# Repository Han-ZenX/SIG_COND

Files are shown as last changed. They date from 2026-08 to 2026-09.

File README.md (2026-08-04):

# SIG_COND - 高精度频率计前端双通道信号调理电路模块

[]()
[]()
[]()

## 项目概述

SIG_COND 是一款专为高精度频率计设计的前端双通道信号调理电路模块，提供卓越的信号采集和处理能力。该模块支持灵活的阻抗切换和 AC/DC 耦合切换，能够处理从微伏级到大幅度的宽范围信号，并配备标准的 SPI 和 I2C 双接口通信方式。

### 核心特性

- ✅ **双通道独立信号调理** - 两个完全独立的信号通道，可同时采集两路信号
- ✅ **阻抗自动/手动切换** - 支持高阻抗和低阻抗模式的灵活切换，适配不同信号源
- ✅ **AC/DC 耦合切换** - 支持交流耦合和直流耦合模式切换，适应多种应用场景
- ✅ **宽动态范围** - 从小幅度微弱信号到大幅度强信号，全覆盖处理
- ✅ **双接口通信** - 同时支持 SPI 和 I2C 接口，灵活选择通信方式
- ✅ **高精度信号采集** - 低噪声、低失真设计，确保测量精度
- ✅ **模块化设计** - 分层架构，易于集成和扩展

## 目录结构

```
SIG_COND-master/
├── firmware/          # 固件代码（MCU 控制程序）
│   ├── boards/        # 板级配置文件
│   ├── include/       # 头文件
│   ├── lib/           # 第三方库
│   ├── src/           # 源代码
│   │   ├── app/       # 应用层业务逻辑
│   │   ├── drivers/   # 外设驱动（SPI/I2C 等）
│   │   ├── hal/       # 硬件抽象层
│   │   └── services/  # 服务层（通信、配置管理等）
│   └── tests/         # 单元测试
│
├── hardware/          # 硬件设计文件
│   ├── schematic/     # 原理图
│   ├── pcb/           # PCB 布局文件
│   ├── bom/           # 物料清单
│   ├── gerber/        # 生产 Gerber 文件
│   ├── 3d/            # 3D 结构模型
│   └── pinout/        # 引脚定义
│
├── software/          # 配套软件
│   ├── desktop/       # PC 桌面应用
│   ├── mobile/        # 移动应用
│   └── cloud/         # 云端服务
│
├── docs/              # 技术文档
│   ├── architecture/  # 架构设计文档
│   ├── api/           # API 接口文档
│   ├── hardware/      # 硬件说明
│   └── user-guide/    # 用户手册
│
├── tests/             # 系统测试
│   ├── unit/          # 单元测试
│   ├── integration/   # 集成测试
│   └── hwt/           # 硬件在环测试
│
├── tools/             # 工具链
│   ├── scripts/       # 构建脚本
│   └── utilities/     # 辅助工具
│
└── ci/                # CI/CD 流水线配置
```

## 硬件规格

### 通道特性

| 参数 | 指标 |
|---|---|
| 通道数 | 2 路独立通道 |
| 输入阻抗 | 可编程切换（高阻/低阻） |
| 耦合方式 | AC/DC 可选 |
| 输入范围 | 微伏级～大幅度信号 |
| 信噪比 | 高信噪比设计 |
| 带宽 | 宽频带响应 |

### 接口规范

#### SPI 接口
- 时钟频率：最高可达 XX MHz
- 模式：支持 Mode 0/1/2/3
- 数据位：8/16/32 位可选
- 引脚定义：见 `hardware/pinout/pinout.md`

#### I2C 接口
- 速率：标准模式 (100kHz)、快速模式 (400kHz)、高速模式 (3.4MHz)
- 地址：可配置 I2C 地址
- 支持多主机和从机模式

## 软件架构

本项目采用**分层模块化架构**，核心设计原则：

- **更换 MCU 只改 HAL 层，业务逻辑零修改**
- **各层解耦，独立编译和测试**
- **支持多板级并行开发**

### 层次结构

```
┌─────────────────┐
│     App Layer   │  ← 业务逻辑、状态机、用户交互
├─────────────────┤
│  Services Layer │  ← 通信协议、配置管理、数据存储
├─────────────────┤
│   Drivers Layer │  ← SPI/I2C 驱动、外设控制
├─────────────────┤
│     HAL Layer   │  ← GPIO、时钟、中断抽象
└─────────────────┘
```

## 快速开始

### 环境要求

- CMake 3.16+
- ARM GCC 工具链 (10-bit-32bit)
- Python 3.8+ (用于构建脚本)
- Git + Git LFS (大文件支持)

### 构建固件

```bash
# 克隆仓库
git clone --recurse-submodules https://github.com/your-repo/SIG_COND.git
cd SIG_COND

# Debug 版本构建
cmake -B firmware/build -DBOARD=default
cmake --build firmware/build

# Release 版本构建
cmake -B firmware/build -DBOARD=default -DCMAKE_BUILD_TYPE=Release
cmake --build firmware/build --config Release

# 使用构建脚本（推荐）
python tools/scripts/build.py --board=default
python tools/scripts/build.py --board=default --release
```

### 烧录固件

```bash
# 烧录到目标板
python tools/scripts/build.py --flash
```

## 使用说明

### 初始化配置

1. **接口选择**：通过软件配置选择 SPI 或 I2C 通信接口
2. **阻抗设置**：配置通道输入阻抗模式（高阻/低阻）
3. **耦合方式**：选择 AC 或 DC 耦合
4. **增益设置**：根据信号幅度调整放大倍数

### 典型应用场景

- 🔬 实验室精密测量
- 📡 通信信号分析
- ⚡ 电力电子监测
- 🎵 音频信号测试
- 🏭 工业过程控制

## 开发指南

### 新增功能

```bash
# 创建功能分支
git checkout -b feat/new-feature

# 开发完成后
git add .
git commit -m "feat: 添加新功能"
git push origin feat/new-feature
```

### 硬件改版

当需要修改硬件设计时：

```bash
# 1. 更新原理图和 PCB（在 EDA 工具中）
# 2. 更新引脚定义
cp -r hardware/schematic/v1.0 hardware/schematic/v2.0

# 3. 更新固件板级配置
cp -r firmware/boards/default firmware/boards/v2.0

# 4. 编译验证
cmake -B firmware/build -DBOARD=v2.0
```

## 测试

```bash
# 运行单元测试
python tools/scripts/build.py --test=unit

# 运行集成测试
python tools/scripts/build.py --test=integration

# 完整测试套件
python tools/scripts/build.py --test=all
```

## 版本历史

### v1.0.0 (2026-08-04)
- ✨ 初始版本发布
- ✅ 实现双通道信号调理
- ✅ 完成阻抗切换功能
- ✅ 完成 AC/DC 切换功能
- ✅ 支持 SPI 和 I2C 接口
- ✅ 实现宽范围信号处理能力

## 技术支持

如需技术支持或遇到问题，请：

1. 查阅 [用户手册](docs/user-guide/)
2. 查看 [API 文档](docs/api/)
3. 提交 [GitHub Issue](https://github.com/your-repo/SIG_COND/issues)

## 贡献指南

欢迎贡献代码！请阅读 [贡献指南](CONTRIBUTING.md) 后提交 PR。

## 许可证

本项目采用 MIT 许可证。详见 [LICENSE](LICENSE) 文件。

---

**注意**：本产品仅供教育和专业用途，使用前请确保安全操作规范。

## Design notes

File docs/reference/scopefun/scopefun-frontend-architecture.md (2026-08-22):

# ScopeFun 前端信号链架构分析

> 分析对象：`Scopefun原理图.pdf`（21 页）。前端在 p2–p5，四通道完全相同，本文以 p2 的**通道 4** 为准，位号后缀 `_4`。支撑电路取自 p10（偏置与失调）和 p13（前端电源）。
>
> PDF 为纯矢量图、文字已转曲，本文全部结论由渲染后逐页读图得出，**器件规格未经数据手册核实**。

四通道相同的模拟前端，从 BNC 到 ADC 共四级。核心是 **BUF802 与 OPA140 组成的混合路径缓冲**——它把 AC/DC 耦合切换从射频通路挪到了低频通路，因此一颗 CMOS 模拟开关就够，不需要射频继电器。

---

## 目录

- [信号链总览](#信号链总览)
- [Stage 1 端接与阻抗切换](#stage-1-端接与阻抗切换)
- [Stage 2 50× 衰减器](#stage-2-50-衰减器)
- [Stage 3 混合缓冲与 AC/DC 耦合](#stage-3-混合缓冲与-acdc-耦合)
- [Stage 4 可编程增益放大](#stage-4-可编程增益放大)
- [支撑电路](#支撑电路)
- [七个值得借鉴的手法](#七个值得借鉴的手法)
- [对频率计前端的适配](#对频率计前端的适配)
- [本文未覆盖的部分](#本文未覆盖的部分)
- [附：原理图切片](#附原理图切片)

---

## 信号链总览

四级串联，每一级由一个继电器或一颗芯片主导。级号是真实的信号顺序。

| 级 | 名称 | 主器件 | 作用 |
|---|---|---|---|
| **1** | 端接与阻抗切换 | `K1000_4` UD2-4.5NUN-L | DPDT 继电器选路 + 汇合，50 Ω 端接或 1 MΩ 高阻 |
| **2** | 50× 衰减器 | `K1001_4` + 976k/20k | 1× 直通或 50× 分压，多阶补偿网络 + 可调微调电容 |
| **3** | 混合缓冲与 AC/DC | `BUF802` + `OPA140` + `TMUX4053` | 高频走 JFET，低频走精密运放，AC/DC 在低频路径切换 |
| **4** | 可编程增益 | `LMH6518` | 单端进差分出，失调由 DAC 从 IN_N 注入 |

四级之后是 ADC Driver（p6–p9）与 ADC（p11），对频率计不适用，本文不展开。

---

## Stage 1 端接与阻抗切换

> Termination and Attenuation · `K1000_4` · 原理图：[`p2_term_L.png`](./p2_term_L.png)

### 信号路径

```
J1002_4 (BNC) ── BNC_IN ── K1000_4A pin3 (COM)
                              │
   ┌──[pin4] TERM_50Z ────────┴──┬── R1025_4  49.9Ω ── GND      (50 Ω 端接)
   │                             │
   │                             └── R1021_4  15Ω ────┬── TERM_50Z_R ── K1000_4B pin5
   │                                 C1058_4 18pF ────┘
   │                                 + R1053_4 0Ω  (与 15Ω 并联)
   │
   └──[pin2] TERM_1M ── R1022_4 30Ω ── TERM_1M_R ────────────── K1000_4B pin7
                                       C1022_4 (DNP) ── GND
                                                                      │
                                                    K1000_4B pin6 (COM) ── ATTEN_IN
```

一颗 DPDT 继电器用掉两组触点：**A 组选路、B 组汇合**。这是双通路架构的标准用法——两组触点同步动作，保证输入端和输出端永远选中同一条路径。

### 元件

| 位号 | 值 | 作用 |
|---|---|---|
| **R1025_4** | 49.9 Ω | 50 Ω 档的端接电阻，接在继电器输出侧、限流电阻之前 |
| **R1021_4** | 15 Ω | 50 Ω 路径的串联阻尼／限流 |
| C1058_4 + R1053_4 | 18 pF + 0 Ω | 并联在 15 Ω 两端做高频旁路，抵消它在高频段的插损。容抗等于 15 Ω 的频点约 590 MHz |
| **R1022_4** | 30 Ω | 1 MΩ 路径的串联限流保护。相对 1 MΩ 可忽略，故障时限制冲入后级的电流 |
| C1022_4 | DNP | 预留位，不贴 |

### 继电器驱动值得单独看

```
+VUSB ──┬── R1027_4 22Ω ──┬────────── pin1 (线圈+)
        │                  │
   C1026_4 22µF        C1027_4 22µF     C1009_4 1µF
        │                  │                 │
       GND                GND               GND

pin8 (线圈−) ──┬── D1000_4 (1N4148WT-7) ── +VUSB   续流
               └── Q1002_4 (DMN62D0UW) ── GND

TERMD ──┬── R1029_4 10K ── Q1002_4 栅极
        └── R1031_4 10K ── GND                      栅极下拉
```

**22 Ω 串联 + 44 µF 储能**——切换瞬间由大电容放电提供吸合所需的大电流，稳态时 22 Ω 限制保持电流。既降低了对 +VUSB 的冲击，又减少了线圈持续发热带来的热漂移。

**栅极 10 K 下拉（R1031_4）**——控制信号悬空或上电未初始化时，MOS 确定关断，继电器状态不会不确定。四个通道八个继电器每一个都配了下拉。

---

## Stage 2 50× 衰减器

> 50x Attenuator · `K1001_4` · 原理图：[`p2_term_R.png`](./p2_term_R.png)

只有 **1× 和 50× 两档**，没有 10×、没有 100×。这印证了通用做法：衰减档是保护档，不是量程档——量程由后面 LMH6518 的可编程增益和失调 DAC 承担。

### 分压与补偿网络

```
ATTEN_IN ── K1001_4A pin3 (COM)
              ├──[pin4] ATTEN_1X ─────────────────── K1001_4B pin5
              │                                              │
              └──[pin2] ATTEN_50X_IN                         │
                          │                                  │
                          ├── R1001_4 1K ── C1011_4 3pF ── GND   (输入阻尼)
                          │
                          ├── R1024_4 976k ─────────────┬── ATTEN_50X_OUT ── pin7
                          │                             │
                          ├── C1023_4 3pF ──┐           ├── R1026_4  20k    ── GND
                          │                 ├── M ──────┤   C1021_4  3pF    ── GND
                          └── C1012_4 0.3pF │           └── C1059_4  2–6pF  ── GND  ★可调
                              └ R1002_4 976k┘
                                    M ── C1025_4 8pF ── GND
                                    M ── C1024_4 1pF ── ATTEN_50X_OUT
                                                                  │
                                             K1001_4B pin6 (COM) ── ATTEN_OUT
```

直流分压比由主链决定：

```
20k / (976k + 20k) = 1/49.8 ≈ 1/50
```

高频段则由电容网络决定。`C1012_4 0.3pF`、`C1023_4 3pF`、`C1024_4 1pF`、`C1025_4 8pF` 与 `R1002_4 976k` 构成的中间网络，是在基本的两元件补偿之外再加的**多阶极点／零点整形**，用来把过渡区的响应压平。这比教科书上的「上下臂各并一颗电容」复杂得多，是宽带衰减器做到平坦的实际代价。

### 两个工程细节

- `C1059_4` 是 **2–6 pF 可调电容**，装在下臂。杂散电容量产不可控，补偿必须留一个可调元件，出厂用方波逐档校准——和示波器探头上那颗补偿螺丝是同一回事。
- 衰减器区域盖了**金属屏蔽罩**：`SHLD1000_4`（TE 2118727-2）和 `SHLD1001_4`（TE 2118728-2，DNP 预留）。高阻抗节点必须屏蔽。

---

## Stage 3 混合缓冲与 AC/DC 耦合

> Input Buffer and AC/DC Coupling · `BUF802` + `OPA140` + `TMUX4053` · 原理图：[`p2_buf.png`](./p2_buf.png)

整个前端最精彩的一级。BUF802 是双路径器件：**高频走内部 JFET 缓冲，低频和直流走外部精密运放经 Aux 输入注入**。两条路径在芯片内部合并，输出既有 JFET 的带宽，又有精密运放的直流精度。

### 双路径结构

```
                        ┌── 高频路径 ───────────────────────────┐
ATTEN_OUT ── R1035_4 30Ω ── ATTEN_OUT_R ── C1030_4 1nF ── BUF_IN ──┤ pin2  IN
    │                                                              │
    │                          R1038_4 10M ── BUF_IN_BIAS ─────────┤ pin3  IN_Bias
    │                                                              │
    │                   ┌── 低频/直流路径 ──┐                       │  BUF802
    ├── R1039_4 909k ───┤                   │                      │  U1009_4
    │                   ├─ C1031_4 10nF ─┐  │                      │
    ├── R1047_4 90.9k ──┘   (可被短路)   │  │                      │
    │        │                           │  │                      │
    │       GND                          ▼  │                      │
    │                            OPA140 U1011_4 (+)                │
    │                            DC_FB ────── (−)                  │
    │                                    │                          │
    │                              OPA_OUT ── R1043_4 2K ──────────┤ pin4  IN_Aux
    │                                         C1035_4 100pF ∥       │
    │                                         C1034_4 100pF ── GND  │
    │                                                               │
    │                              R1036_4 35.7k ── −5V ────────────┤ pin7  R_Bias
    │                                                               │
    └───────────────────────────────────────── BUF_OUT ◄────────────┤ pin11 OUT
                                                   │
              DC 伺服：BUF_OUT ── R1041_4 90.9k ── R1042_4 90.9k
                                       └── R1044_4 10K ── DC_FB ──► OPA140 (−)
```

### AC/DC 切换在低频路径上完成

**这是本次分析最有价值的发现。** 主高频路径上的 `C1030_4 1nF` 是**固定隔直电容，永不切换**——因为高频路径本来就只传交流，直流分量完全由 Aux 路径提供。于是 AC/DC 切换只需要在低频路径上做，而那条路径是高阻、低频的，**一颗 CMOS 模拟开关就够，完全不需要射频继电器。**

| 耦合方式 | `DC_CPLD` | TMUX4053 动作 | 效果 |
|---|---|---|---|
| **DC 耦合** | 1 | S1B–D1 导通，短路 `C1031_4`；S2B/S3B 接入 `C1002_4 68pF` | OPA140 直接看到分压后的直流，Aux 路径传递直流分量 |
| **AC 耦合** | 0 | S1A–D1 导通（S1A 悬空即断开），`C1031_4 10nF` 串入；S2A/S3A 接入 `C1001_4 100pF` | OPA140 看不到直流，输出中直流分量被消除 |

#### 交越补偿随耦合方式一起切换

注意上表第三列的后半段：AC 耦合接 **100 pF**，DC 耦合接 **68 pF**，原理图上明确注了 *"This cap is switched in during AC / DC coupling"*。

原因是 AC 耦合时低频路径里串入了 `C1031_4 10nF`，改变了该路径的传递函数，两条路径的**交越频率**随之偏移，必须重新补偿才能保证合并后的响应平坦。`TMUX4053` 三组开关由同一根 `DC_CPLD` 同步驱动，一次动作同时完成耦合切换和补偿匹配。

### 直流精度靠伺服环路

输出 `BUF_OUT` 经 `90.9k / 90.9k / 10K` 分压得到 `DC_FB`，送回 OPA140 的反相输入。OPA140 比较输入分压与输出分压，通过 Aux 路径持续校正 BUF802 的直流输出——**整机的直流精度由 OPA140 这颗精密运放决定，而不是由 JFET 决定**。这正是混合架构存在的意义。

### 元件

| 位号 | 值 | 作用 |
|---|---|---|
| R1035_4 | 30 Ω | 进 BUF802 前的串联限流／阻尼（与 Stage 1 的 30 Ω 同一思路） |
| C1030_4 | 1 nF | 高频路径固定隔直，不参与 AC/DC 切换 |
| R1038_4 | 10 M | BUF802 的 IN_Bias 偏置电阻 |
| R1039 / R1047 | 909k / 90.9k | 低频路径分压，合计约 1 MΩ，分压比 1/11 |
| R1043_4 | 2 K | OPA140 输出到 IN_Aux 的串联电阻，与切换电容一起决定交越特性 |
| **R1036_4** | 35.7 k | R_Bias 到 −5 V，设定 BUF802 静态电流。图上注明约 **24 mA/rail**；换 100k 则降到约 17 mA/rail |
| U1001_4 | TMUX4053 | 三组 SPDT 模拟开关，±5 V 供电，EN 接地常使能，SEL1/2/3 全部并到 `DC_CPLD`，`R1052_4 10K` 下拉 |

---

## Stage 4 可编程增益放大

> Programmable Gain Amplifier · `LMH6518` · 原理图：[`p2_pga.png`](./p2_pga.png)

```
BUF_OUT ── R1037_4 49.9Ω ── BUF_OUT_R ──► pin6  IN_P        pin15 OUT_P ──► R52_4 0Ω ── OUT_P
                                                            pin14 OUT_N ──► R97_4 0Ω ── OUT_N
PGA_BIAS ───────────────────────────────► pin7  IN_N        pin13 VCM   ──► VCM
                                                            pin1/2/16 AUX_P / AUX_N / AUX_VCM ── 未使用
PGA_CSn  ──► pin9  CSn  (R1033_4 10K 上拉)
PGA_SDIO ──► pin10 SDIO                  电源：pin3/4 VCC ◄── +VPGA (+5V 经 FB1000_4 120Ω@100MHz)
PGA_SCLK ──► pin11 SCLK                        pin12 VDD ◄── +3V3_PGA
                                               pin5/8 GND, pin17 PAD ── GND
```

**单端驱动、差分输出。** LMH6518 的输入引脚是 `IN_P`／`IN_N` 一对，但用法是单端：信号经 49.9 Ω 进 `IN_P`，`IN_N` 接一个直流参考电平 `PGA_BIAS`。芯片放大的是两者之差。

### IN_N 就是失调／电平注入点

`PGA_BIAS` 由 `+VBIAS`（2.5 V 基准）经 `R1045_4 ∥ R1046_4`（1K ∥ 1K）与 DAC 输出的 `TRIM` 信号混合形成，`TRIM` 先过一颗 `FB1001_4 120Ω@100MHz` 磁珠再进来，`C1042_4 100nF` 滤波。

改变 `IN_N` 的电平，就等于移动了信号的参考零点。对示波器这是**垂直位置**；对频率计，这就是**触发电平**——而且是在放大之前设定的，DAC 的分辨率要求远低于在比较器端设阈值。

### 省电细节

原理图注明 *"Max VCC current before configuration (AUX output on): 0.225 A / after configuration turns off AUX output: 0.165 A"*。**ScopeFun 没有使用 AUX 输出**，并在 SPI 配置时主动关闭它，省下 60 mA。`J3_4`／`J4_4` 两个 UFL 座标为 DNP，看得出原本打算把 AUX 引出。

---

## 支撑电路

### 基准与失调 DAC（p10）

> 原理图：[`p10_trim.png`](./p10_trim.png)、[`p10_bias.png`](./p10_bias.png)

| 位号 | 器件 | 说明 |
|---|---|---|
| U4 | REF2025 | 精密基准。**+VBIAS 取自 VREF 脚 = 2.5 V**，原理图注明「VBIAS Pin is 1/2 of 2.5V VREF，Use VREF For OUR +VBIAS」——即不用它自带的 1.25 V 分压脚 |
| U5 | 运放反相器 | 10k/10k 增益 −1，把 +2.5 V 翻成 **−VBIAS = −2.5 V**，反馈上并 C4 补偿，±5 V 供电 |
| U3 | MCP4728 | **4 通道 12 位 I²C DAC（带 EEPROM）**，+5 V 供电，默认地址 `1100000`。VOUTA–D 分别给四个通道的 TRIM |
| Q1 / Q2 | DMN62D0UW | I²C 电平转换，3.3 V ↔ 5 V，配 4.7K 上拉四颗 |

### 前端电源（p13）

> 原理图：[`p13_fe_pwr.png`](./p13_fe_pwr.png)

| 位号 | 器件 | 说明 |
|---|---|---|
| U15 | TPS7A9101 | **超低噪声 LDO**，+5V3 → +5 V（图上算得 5.01 V），软启动 13 ms（刻意大于前级的 6 ms）。注明 968 mA / 728 mA 两个负载点 |
| U16 | NCP161ASN330 | +5 V → +3V3_PGA，给 LMH6518 的数字域 |
| FB1000 / FB1001 | 120Ω@100MHz | 磁珠分域：PGA 电源与 TRIM 信号各自隔离 |

模拟前端用的是**超低噪声 LDO 而不是普通 LDO**，且每一路电源都配了 10 µF + 1 µF 的密集去耦阵列（单通道就有近二十颗）。高阻节点对电源纹波极其敏感，这笔成本省不得。

---

## 七个值得借鉴的手法

### 1. 把 AC/DC 切换挪出射频通路

混合路径架构下，直流分量只走低频支路，所以耦合切换也只需在低频支路上做。一颗 TMUX4053 取代了射频继电器和大体积高压隔直电容——这是 BUF802 架构带来的最大结构性简化。

### 2. 补偿参数跟着工作模式一起切换

AC 与 DC 两种耦合下，两条路径的交越频率不同，于是交越补偿电容也跟着切（100 pF / 68 pF），由同一根控制线同步完成。只切信号不切补偿，响应就会在交越区出现凸起或凹陷。

### 3. 继电器的储能式节能驱动

22 Ω 串联加 44 µF 储能：吸合瞬间靠电容放电供大电流，稳态靠电阻限流。既不冲击电源，又压低了线圈的持续发热——发热就是漂移。

### 4. 每个 MOS 栅极都有下拉

八个继电器驱动无一例外配了 10 K 下拉。控制器复位、上电未初始化、固件跑飞时，继电器状态都是确定的。

### 5. 衰减器必须留可调元件

2–6 pF 可调电容装在下臂。杂散电容随批次、布局、器件批号变化，补偿条件不可能靠固定值满足，出厂逐台校准是必经步骤。

### 6. 高阻节点要有金属屏蔽罩

衰减器区域盖 TE 屏蔽罩并预留第二个位置。976 kΩ 量级的节点上，几毫伏的空间耦合就是可观的误差。

### 7. 超低噪声 LDO + 磁珠分域 + 密集去耦

电源不是「能用就行」的部分。前端用 TPS7A9101 这类超低噪声 LDO，PGA 电源和 DAC 输出各经磁珠隔离，单通道近二十颗去耦电容。

---

## 对频率计前端的适配

ScopeFun 用的正是 **BUF802 + LMH6518** 组合，衰减档也正是 **1× / 50×** 两档。这为几个悬而未决的选型提供了实证。

### 可以直接搬过来的

| | 内容 |
|---|---|
| **直接抄** | **Stage 3 整块。** BUF802 + OPA140 + TMUX4053 的混合缓冲，含 AC/DC 方案、交越补偿切换、DC 伺服环路。这一块同时解决 1 mHz 直流精度需求和 500 MHz 带宽需求，还省掉原本要用 K3 继电器加两颗隔直电容的整套 AC/DC 电路 |
| **直接抄** | **Stage 1 的继电器用法与驱动。** 一颗 DPDT 分「选路 + 汇合」两组触点，与现有 K1 用法一致，确认方向正确。储能式驱动和栅极下拉直接补进电路 |
| **直接抄** | **LMH6518 的 IN_N 做电平注入。** ScopeFun 用它做垂直位置，频率计用它做触发电平，接法完全相同：基准电压经电阻网络与 DAC 输出混合，DAC 侧串磁珠。MCP4728 这类 4 通道 12 位 I²C DAC 就够用 |
| **直接抄** | **电源与偏置架构。** 超低噪声 LDO、REF2025 产生 ±2.5 V 基准、磁珠分域 |

### 必须为频率计改动的

| | 内容 |
|---|---|
| **要改** | **输出级完全不同。** ScopeFun 的 LMH6518 主输出经 0 Ω 送 ADC Driver 再进 ADC；频率计要送 ADCMP573 比较器。有意思的是 **ScopeFun 关掉不用的 AUX 输出，对频率计恰好是现成的比较器通道**——AUX_VCM 还能独立设定共模，正好匹配比较器的输入范围 |
| **要改** | **要补一级 100 kHz 低通。** 示波器不需要，所以 ScopeFun 全图没有；但 1 mHz 指标下噪声导致的重复触发是主要误差源，这一级必须自己加，且要用 Bessel 或一阶 RC，不能用 Chebyshev |
| **要改** | **衰减比按最大输入电压定。** ScopeFun 选 50×（976k/20k）。若最大输入定在 ±40 V 附近，10× 就够；要对齐示波器的 ±300 V 则需要 50× 或 100× |
| **要核** | **过压保护。** 这次读图没有看到明显的输入保护（TVS、箝位、过压检测跳闸）。可能在未细读的区域，也可能 ScopeFun 就是靠 30 Ω 限流加器件自身耐受。前端若要接用户任意信号，这一块不能照搬缺失 |

### 与本项目当前原理图的差距

| 环节 | ScopeFun | 本项目当前状态 |
|---|---|---|
| 阻抗切换 | K1000 DPDT，选路+汇合 | K1 同样用法，方向一致 |
| 衰减档 | 1× / 50×，单继电器选抽头 | 级联两组分压器 → 实际是 10×/100×，**缺 1× 档** |
| 缓冲器 | BUF802 + OPA140 混合 | OPA659 单路径，直流漂移是短板 |
| AC/DC | TMUX4053 在低频路径切换 | 计划用 K3 继电器 + 隔直电容，尚未实现 |
| PGA | LMH6518，IN_N 注入失调 | 已改用 LMH6518，**但整颗芯片尚未接线** |
| 触发电平 | MCP4728 → IN_N | 尚无 DAC 通路 |
| 低通滤波 | 无（示波器不需要） | 需自行增加（1 mHz 指标要求） |

---

## 本文未覆盖的部分

下列内容**没有读**，结论中不包含它们：

- p13 右半的 **−5 V 产生电路**
- p6–p9 的 **ADC Driver**（频率计不适用）
- p11 ADC、p12 时钟、p14–p20 的 FPGA 与电源

另外，全文所有器件规格——BUF802 的带宽与输入电容、LMH6518 的增益范围与输入阻抗、TMUX4053 的导通电阻、UD2-4.5NUN-L 是否为磁保持型——**均未经数据手册核实**，只是从原理图上读出的连接关系与标注值。落到自己的设计里之前，请逐条对照手册。

---

## 附：原理图切片

从 PDF 渲染的高分辨率切片，比直接翻 PDF 清楚。

| 文件 | 内容 |
|---|---|
| [`sheet.png`](./sheet.png) | 20 页缩略图联系表，用于定位 |
| [`p2_term_L.png`](./p2_term_L.png) | 端接与阻抗切换 + 继电器驱动 |
| [`p2_term_R.png`](./p2_term_R.png) | 50× 衰减器完整网络 |
| [`p2_buf.png`](./p2_buf.png) | **BUF802 + OPA140 + TMUX4053 混合缓冲**（核心） |
| [`p2_pga.png`](./p2_pga.png) | LMH6518 接线与 PGA_BIAS |
| [`p10_trim.png`](./p10_trim.png) | MCP4728 失调 DAC |
| [`p10_bias.png`](./p10_bias.png) | REF2025 基准生成 |
| [`p13_fe_pwr.png`](./p13_fe_pwr.png) | 前端 LDO |

---

*ScopeFun 为开源示波器项目，原理图为其公开资料。本文为架构分析，不含原文档的图形复制；附带切片仅为阅读便利，版权归原项目所有。*

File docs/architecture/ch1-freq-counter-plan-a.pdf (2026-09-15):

D E S I G N P L A N · F R E Q U E N C Y M E A S U R E M E N T P A T H

# CH1 测频方案 A：放弃 AUX，改由主输出分路

LMH6518 的辅助输出 AUX_P/N 在 CH1 单板上引不出来。本方案删掉 AUX 这一路，测频信号改从主输出 CH1_P / CH1_N 取，分路放到接收板上。 文档包含三部分：CH1 板的改动清单、固件配置、对接收板的接口要求。标 推断 或 待确认 的结 论，没有在器件手册里找到直接依据。

工程 | Thunderscope_Rev5.3_CH1
器件 | U1008_1 · LMH6518
手册 | ZHCSPP6E（2024-07 修订）
日期 | 2026-09-15
状态 | 方案草稿 · 尚未改图

结论

## 1 信号没有损失

AUX 与主输出的增益匹配在 ±0.2 dB 以内，−3 dB 带宽匹 配在 5% 以内，SPI 选的带宽滤波器同时作用于两路。手册 的原话是 AUX 与主输出"几乎相同"，只是失真略差。测频从 OUT 取还是从 AUX 取，拿到的是同一个信号。

## 2 CH1 板只删不加

删除 RF3、RF4、R52_8、R97_8 四个元件；U1008 的 pin1、pin2、pin16 标为不连接。AUX 相关网络在 PCB 上 本来就没有任何走线，R52_8、R97_8 还在板框外没摆放， 所以删除不需要改线。

## 3 分路挪到接收板

CH1 板只负责把 CH1_P/N 经 RF1、RF2 送出。100 Ω 端 接、比较器分支、电平转换都放在接收板。固件上电后通过 SPI 把 D10 置 1，关闭 AUX 输出级，VCC 电流大约减少 60 mA。

## 为什么不走 AUX：两路输出参数对照

数据取自 LMH6518 手册 5.5 节电气特性（测试条件：VCC = 5 V、VCM = VCM_AUX = 1.2 V、两路负载均为 100 Ω 差分），以及 6.4 节、7.2.1.2 节。

项目 | 主输出 OUT（pin15 / pin14） | 辅助输出 AUX（pin1 / pin2） | 对测频的含义
增益 | 随前置放大 HG/LG 和梯形衰减档位变化 | 与主输出匹配：典型 ±0.1 dB，最大 ±0.2 dB | AUX 并不是固定幅度的输出，幅度问题两路一样
带宽 | SPI 可选 20 / 100 / 200 / 350 / 650 / 750 MHz 或 全带宽 | 带宽匹配 5%；手册注明滤波器"同时作用于主输出和辅 助输出" | 两路带宽相同
满幅摆幅（100 MHz 时 THD ≤ −40 dBc） | 典型 800 mVpp | 典型 800 mVpp | 相同
传播延时 | 两路匹配在 100 ps 以内 | | 测频不关心
失真 | 略好 | 100 MHz：HD2 −48 dBc，HD3 −50 dBc，比主输出 略差 | 过零比较对谐波不敏感
输出共模 | 由 pin13 VCM 设定 | 由 pin16 VCM_AUX 单独设定，目前悬空 | 用 AUX 要多做一路偏置和去耦
VCC 电流 | AUX 打开：典型 210 mA，最大 225 mA ｜ AUX 关闭：典型 150 mA，最大 165 mA | 用 AUX 要多耗约 60 mA
CH1 测频方案 A · Thunderscope_Rev5.3_CH1 | 第 1 / 5 页

## 改动前后对比

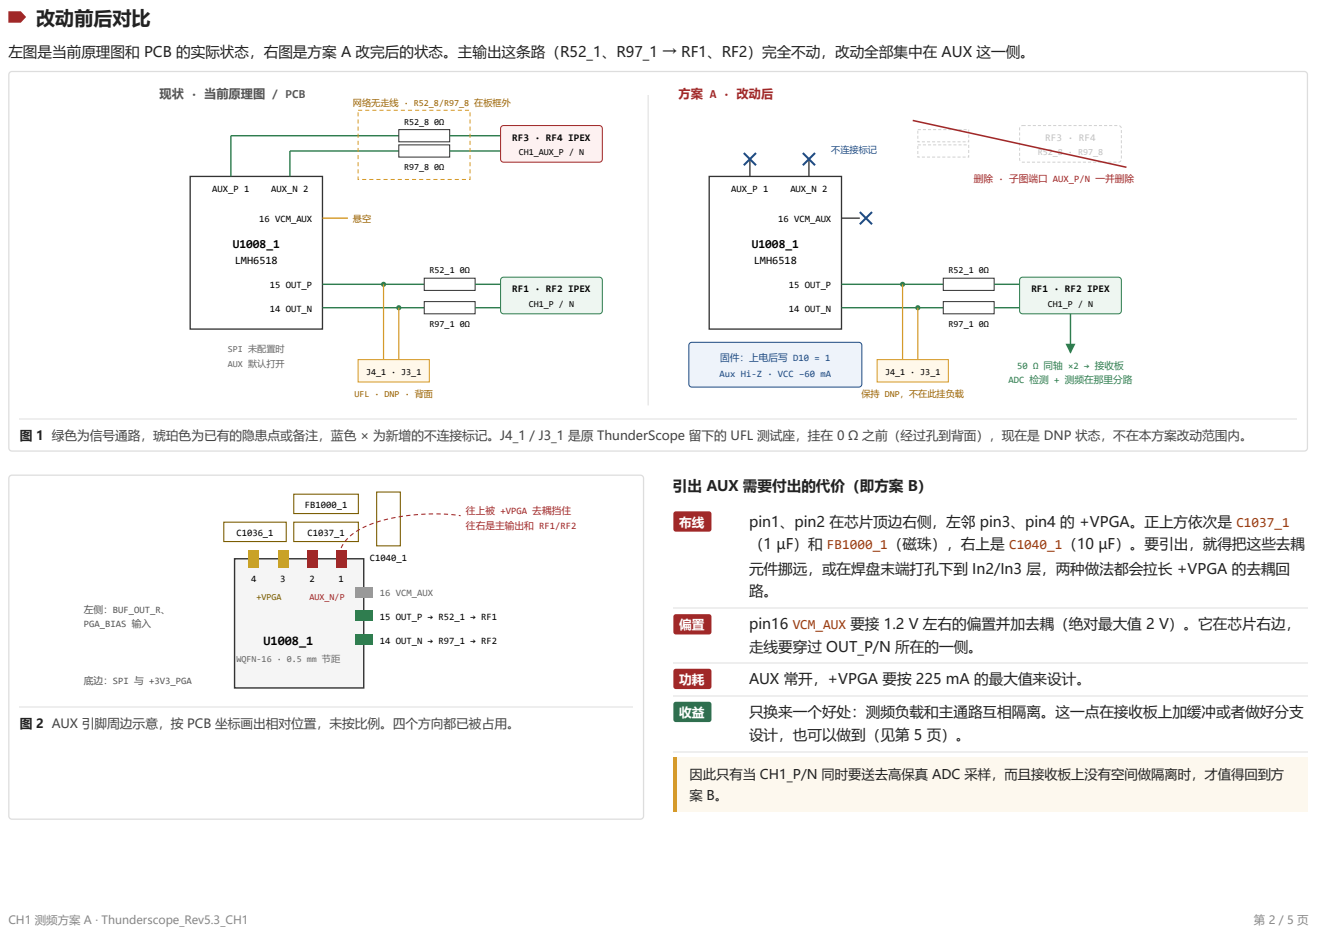
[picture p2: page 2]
U1008_1 LMH6518; AUX_P 1; AUX_N 2; RF3 · RF4 IPEX CH1_AUX_P / N; 网络无走线 · R52_8/R97_8 在板框外; 16 VCM_AUX; 15 OUT_P; 14 OUT_N; RF1 · RF2 IPEX CH1_P / N; SPI 未配置时 AUX 默认打开; 方案 A · 改动后; 不连接标记; +VPGA; AUX_N/P; 15 OUT_P → R52_1 → RF1; 14 OUT_N → R97_1 → RF2; 左侧：BUF_OUT_R、 PGA_BIAS 输入; 底边：SPI 与 +3V3_PGA; pin1、pin2 在芯片顶边右侧，左邻 pin3、pin4 的 +VPGA。正上方依次是 C1037_1; pin16 VCM_AUX 要接 1.2 V 左右的偏置并加去耦（绝对最大值 2 V）。它在芯片右边，; 走线要穿过 OUT_P/N 所在的一侧。; AUX 常开，+VPGA 要按 225 mA 的最大值来设计。; 只换来一个好处：测频负载和主通路互相隔离。这一点在接收板上加缓冲或者做好分支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

左图是当前原理图和 PCB 的实际状态，右图是方案 A 改完后的状态。主输出这条路（R52_1、R97_1 → RF1、RF2）完全不动，改动全部集中在 AUX 这一侧。

现状 · 当前原理图 / PCB

删除 · 子图端口 AUX_P/N 一并删除

固件：上电后写 D10 = 1
Aux Hi-Z · VCC −60 mA

50 Ω 同轴 ×2 → 接收板
ADC 检测 + 测频在那里分路

保持 DNP，不在此挂负载

UFL · DNP · 背面

图 1 绿色为信号通路，琥珀色为已有的隐患点或备注，蓝色 × 为新增的不连接标记。J4_1 / J3_1 是原 ThunderScope 留下的 UFL 测试座，挂在 0 Ω 之前（经过孔到背面），现在是 DNP 状态，不在本方案改动范围内。

引出 AUX 需要付出的代价（即方案 B）

往上被 +VPGA 去耦挡住
往右是主输出和 RF1/RF2

（1 µF）和 FB1000_1（磁珠），右上是 C1040_1（10 µF）。要引出，就得把这些去耦
元件挪远，或在焊盘末端打孔下到 In2/In3 层，两种做法都会拉长 +VPGA 的去耦回

WQFN-16 · 0.5 mm 节距

图 2 AUX 引脚周边示意，按 PCB 坐标画出相对位置，未按比例。四个方向都已被占用。

设计，也可以做到（见第 5 页）。

因此只有当 CH1_P/N 同时要送去高保真 ADC 采样，而且接收板上没有空间做隔离时，才值得回到方

## CH1 板改动清单

以下对象都在当前网表和 PCB 文件里核对过。改图顺序：先改三张原理图，ERC 通过后再在 PCB 编辑器里执行"从原理图更新 PCB"，最后跑 DRC。改之前要先在 KiCad 里保存并关闭工程，目录下现在 有 .lck 锁文件。

文件 | 对象 | 操作 | 说明

原理图

FE_Channel.kicad_sch | R52_8、R97_8（0 Ω 0402） | 删除 | 同时删除它们两端的导线和网络标签 AUX_R_P、AUX_R_N
FE_Channel.kicad_sch | 层次标签 AUX_P、AUX_N | 删除 | 删除后子图不再有 AUX 端口
FE_Channel.kicad_sch | U1008_1 pin1、pin2、pin16 | 加不连接标记 | 避免 ERC 报"引脚未连接"；pin16 目前没有标记，本来就在报警
FE_Channel.kicad_sch | 文字注释 "Max VCC current … AUX output …" | 保留 | 这两行（0.225 A / 0.165 A）正好说明固件要关 AUX，不用改
Thunderscope_Rev5.3.kicad_sch CH1 子图符号上的 AUX_P、AUX_N 引脚 | 删除 | 在子图符号上用"删除未使用的层次引脚"

Thunderscope_Rev5.3.kicad_sch IO 子图符号上的 AUX_P、AUX_N 引脚；标

| 签 CH1_AUX_P、CH1_AUX_N 及导线 | 删除 | 顶层不再有 CH1_AUX 网络
External_IO.kicad_sch | RF3、RF4（KH-IPEX-K501-29） | 删除 | 同时删除层次标签 AUX_P、AUX_N；只服务 RF3、RF4 的 GND 符号一并删除

PCB
Thunderscope_Rev5.3.kicad_pcb 从原理图更新 | 同步 | 自动移除 RF3（147.4, 78.2）、RF4（147.4, 73.8）和板框外的 R52_8、R97_8。这 4 个网络上没有走线、
| | | 过孔或铺铜连接，不需要手工清理
Thunderscope_Rev5.3.kicad_pcb RF3、RF4 腾出的区域 | 可选 | 约在板子右下角，可以留给后续的 VCM / +VBIAS 基准电路（接口图册里列为"必须补"的项目）
Thunderscope_Rev5.3.kicad_pcb U1008 周边、主输出走线 | 不动 | R52_1、R97_1、RF1、RF2 以及 +VPGA 去耦都保持原样
BOM 与文档
BOM | −2 × KH-IPEX-K501-29，−2 × 0 Ω 0402 | 减少 | 其他器件不变
docs/architecture/ ch1-frontend-interface.pdf | 第 1、2、3、9 页中 AUX / RF3 / RF4 相关 内容 | 同步更新 | 端口从 12 个变为 10 个；"用 AUX 时"一项改为"AUX 已关闭，固件须写 D10"

明确不做的事

不做 | 不在 CH1 板上的 OUT_R_P/N 上并联比较器或测试座负载。主输出唯一的负载应该是 远端的 100 Ω 差分端接。
不做 | 不给 pin16 加偏置电路。AUX 关闭后这个脚不再起作用，而且把偏置引过去同样会碰 到图 2 里的布线问题。
不做 | 不动 J3_1、J4_1。它们是 DNP，当前只是焊盘和过孔形成的一小段短截线。要不要删 属于另一项清理工作，不和本方案捆在一起。

本方案依赖、但不在范围内的前提

前提 | VCM（pin13）目前没有驱动源。主输出共模不确定时，接收板的直流耦合比较器无法设 计，所以这一项要先解决。手册的测试条件是 1.2 V，绝对最大值 2 V。
前提 | +VBIAS、−VBIAS 没有来源，LMH6518 输入端的直流工作点不成立。这是整板能否工 作的问题，与测频无关，见接口图册第 9 页。
CH1 测频方案 A · Thunderscope_Rev5.3_CH1 | 第 3 / 5 页

## 固件：关闭 AUX，设置测频档位

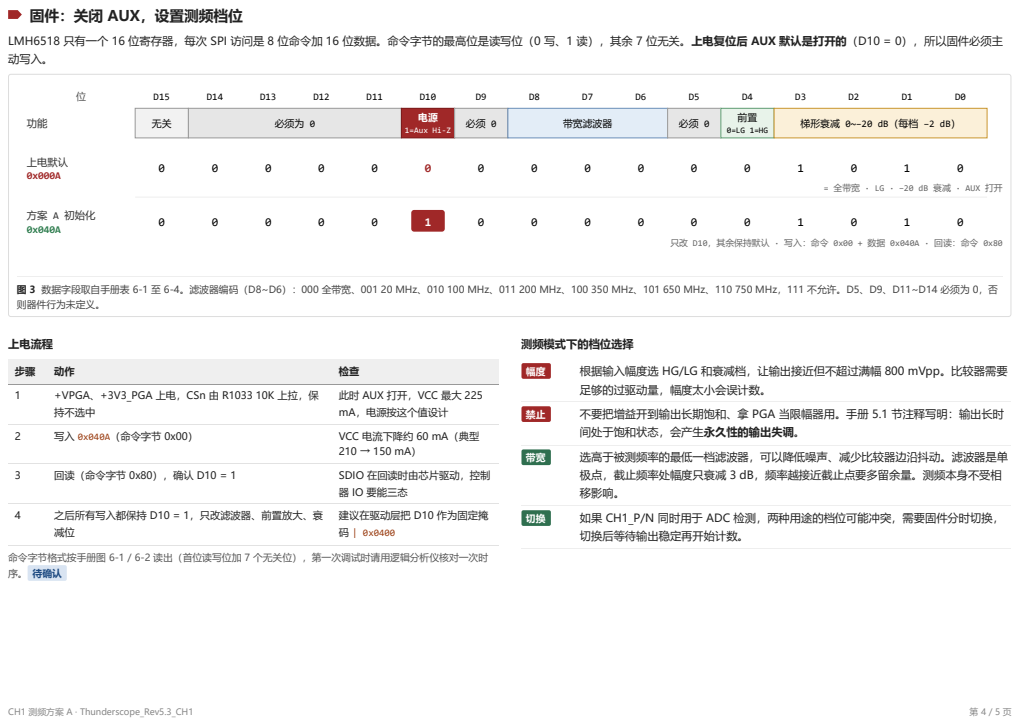
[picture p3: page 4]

LMH6518 只有一个 16 位寄存器，每次 SPI 访问是 8 位命令加 16 位数据。命令字节的最高位是读写位（0 写、1 读），其余 7 位无关。上电复位后 AUX 默认是打开的（D10 = 0），所以固件必须主
动写入。

= 全带宽 · LG · −20 dB 衰减 · AUX 打开

只改 D10，其余保持默认 · 写入：命令 0x00 + 数据 0x040A · 回读：命令 0x80

图 3 数据字段取自手册表 6-1 至 6-4。滤波器编码（D8~D6）：000 全带宽、001 20 MHz、010 100 MHz、011 200 MHz、100 350 MHz、101 650 MHz、110 750 MHz，111 不允许。D5、D9、D11~D14 必须为 0，否
则器件行为未定义。

此时 AUX 打开，VCC 最大 225
mA，电源按这个值设计

极点，截止频率处幅度只衰减 3 dB，频率越接近截止点要多留余量。测频本身不受相
移影响。

命令字节格式按手册图 6-1 / 6-2 读出（首位读写位加 7 个无关位），第一次调试时请用逻辑分析仪核对一次时
序。 待确认

## 接收板：接口要求与参考拓扑

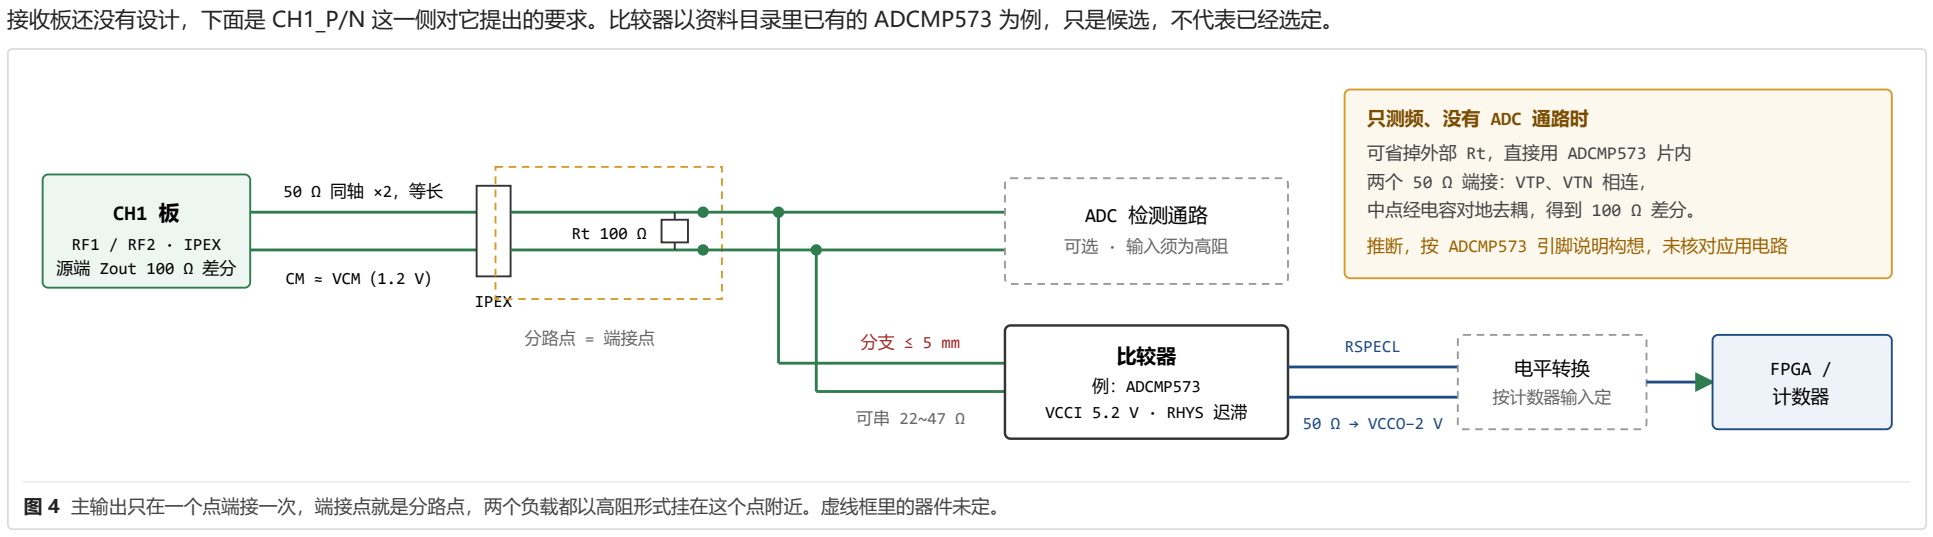
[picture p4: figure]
接收板还没有设计，下面是 CH1_P/N 这一侧对它提出的要求。比较器以资料目录里已有的 ADCMP573 为例，只是候选，不代表已经选定。; RF1 / RF2 · IPEX 源端 Zout 100 Ω 差分; CM ≈ VCM（1.2 V）; IPEX; 分路点 = 端接点; ADC 检测通路 可选 · 输入须为高阻; 比较器; 例：ADCMP573 VCCI 5.2 V · RHYS 迟滞; RSPECL; 50 Ω → VCCO−2 V; 电平转换 按计数器输入定; FPGA / 计数器; 只测频、没有 ADC 通路时; 可省掉外部 Rt，直接用 ADCMP573 片内 两个 50 Ω 端接：VTP、VTN 相连， 中点经电容对地去耦，得到 100 Ω 差分。; 推断，按 ADCMP573 引脚说明构想，未核对应用电路

图 4 主输出只在一个点端接一次，端接点就是分路点，两个负载都以高阻形式挂在这个点附近。虚线框里的器件未定。

项目 | 要求 | 依据
差分阻抗与端接 | 走线 100 Ω 差分；在接收端跨接一个 100 Ω，不要每根线 50 Ω 对地 | LMH6518 差分输出阻抗 92~108 Ω（典型 100 Ω），手册所有输出参数都在 RL = 100 Ω 差分下给 出；对地端接会拉偏输出共模
分支长度 | 比较器分支 ≤ 5 mm，必要时每根线串 22~47 Ω 隔离 | 全带宽上升时间约 460 ps。按"分支延时小于上升时间 1/10"估算，约 46 ps，FR4 表层约 6 ps/mm，即约 7 mm。 经验规则
输入共模 | 比较器必须接受约 1.2 V 共模、单端 0.5~1.8 V 的直流耦合输入 | 主输出每个脚钳位范围 0.5~1.8 V（VCM = 1.2 V）。ADCMP573 在 VCCI = 3.3 V 时输入范围只有 −0.2~+1.2 V，不够；VCCI = 5.2 V 时为 −0.2~+3.2 V，满足。也可以交流耦合后重新偏置
输入负载 | 分支上的器件输入要远高于 100 Ω | ADCMP573 片内端接断开时，差模输入电阻 50 kΩ、共模 500 kΩ，偏置电流最大 50 µA
迟滞 | 比较器必须加迟滞，数值按信号噪声实测确定 | ADCMP573 的 HYS 脚悬空时迟滞约为 0，经 RHYS 接地来设定（手册图 7）。慢速正弦过零时没有 迟滞会产生多次翻转
输出电平 | 比较器输出端接与计数器输入电平匹配 | ADCMP573 为 RSPECL 输出，需要 50 Ω 端接到 VCCO − 2 V。资料目录里有 SN65LVDS20，可以 作为转换候选 待确认

验证步骤：① ERC、DRC 通过，网表中不再有 CH1_AUX 网络；② 上电后在 SPI 写入前后测量 +VPGA 电流，应有约 60 mA 的差值；③ 回读寄存器得到 0x040A；④ 用信号源在各档增益下扫频率和幅度，记录每档能正确计数的最 小输入幅度，写进固件的档位选择表。
数据来源：LMH6518 手册 ZHCSPP6E 5.1、5.5、6.4、6.5、7.2.1.2 节；ADCMP572/573 手册 Rev.PrB（资料版，定稿前换正式版核对）；当前工程 FE_Channel、External_IO、顶层原理图与 kicad_pcb 文件（2026-09-15）。
CH1 测频方案 A · Thunderscope_Rev5.3_CH1 | 第 5 / 5 页

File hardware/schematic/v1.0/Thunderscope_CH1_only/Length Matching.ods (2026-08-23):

Input Net | Length | Output Net | Length |  | Total Length | Input Net Target Length | Reported Length
CH1_N | 40.2025 | 1/OUT_N | 10.1266 |  | 50.3291 | 63.8937 | 63.8717
CH1_P | 40.6287 | 1/OUT_P | 9.9265 |  | 50.5552 | 64.0938 | 64.0511
CH2_N | 39.9981 | 2/OUT_N | 5.8623 |  | 45.8604 | 68.158 | 68.1512
CH2_P | 40.4224 | 2/OUT_P | 5.861 |  | 46.2834 | 68.1593 | 68.151
CH3_N | 63.788 | 3/OUT_N | 5.8657 |  | 69.6537 | 68.1546 | 68.151
CH3_P | 64.2142 | 3/OUT_P | 5.8576 |  | 70.0718 | 68.1627 | 68.151
CH4_N | 63.4822 | 4/OUT_N | 9.9297 |  | 73.4119 | 64.0906 | 64.0984
CH4_P | 63.9084 | 4/OUT_P | 10.1119 |  | 74.0203 | 63.9084 | 63.9084
 |  |  |  | Longest | 74.0203

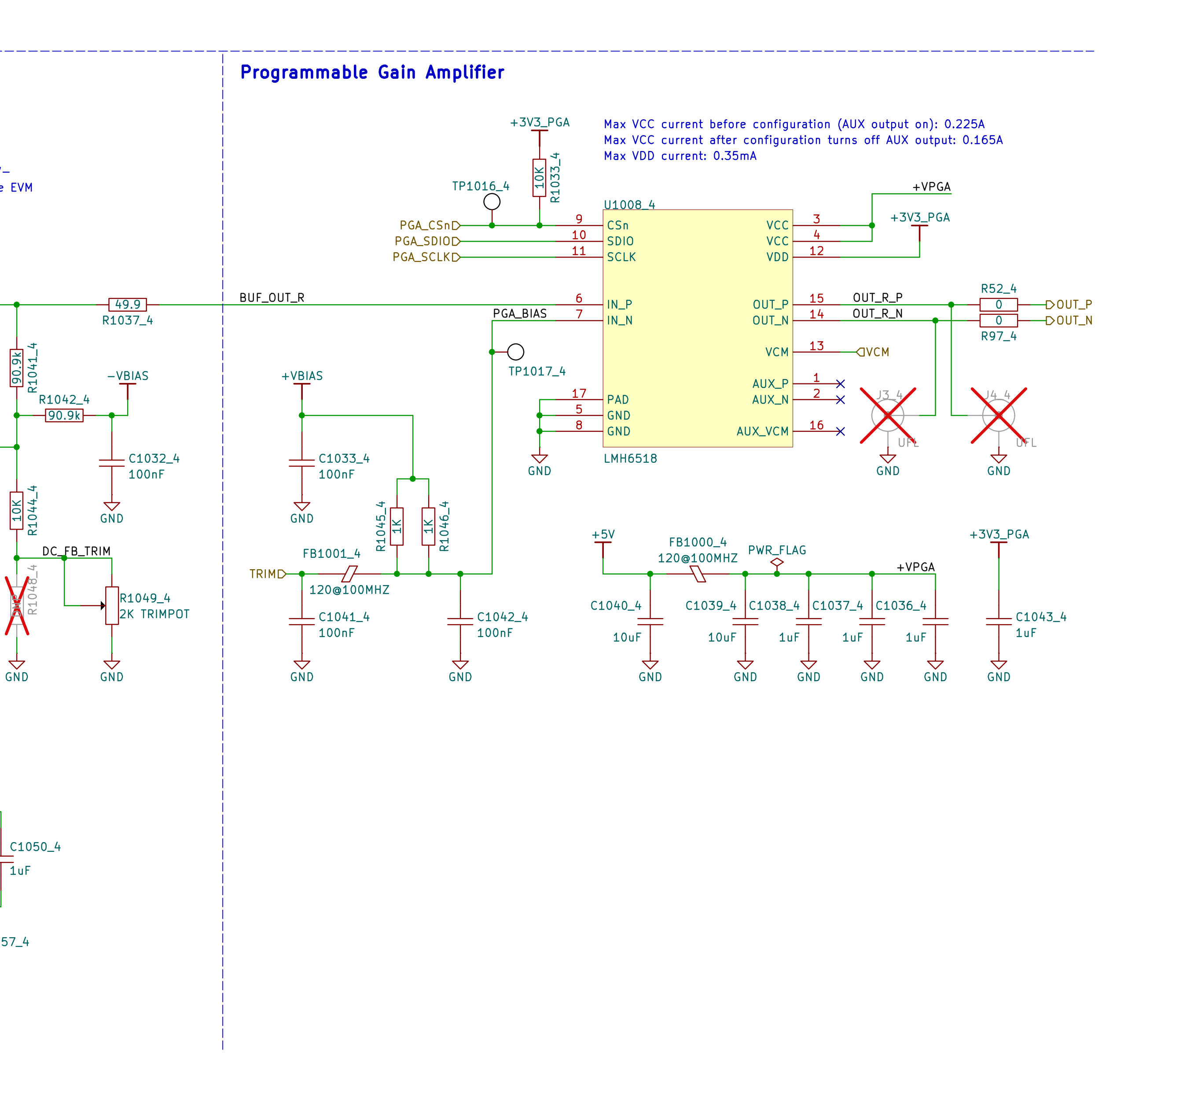
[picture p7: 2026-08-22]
docs/reference/scopefun/p2_pga.png

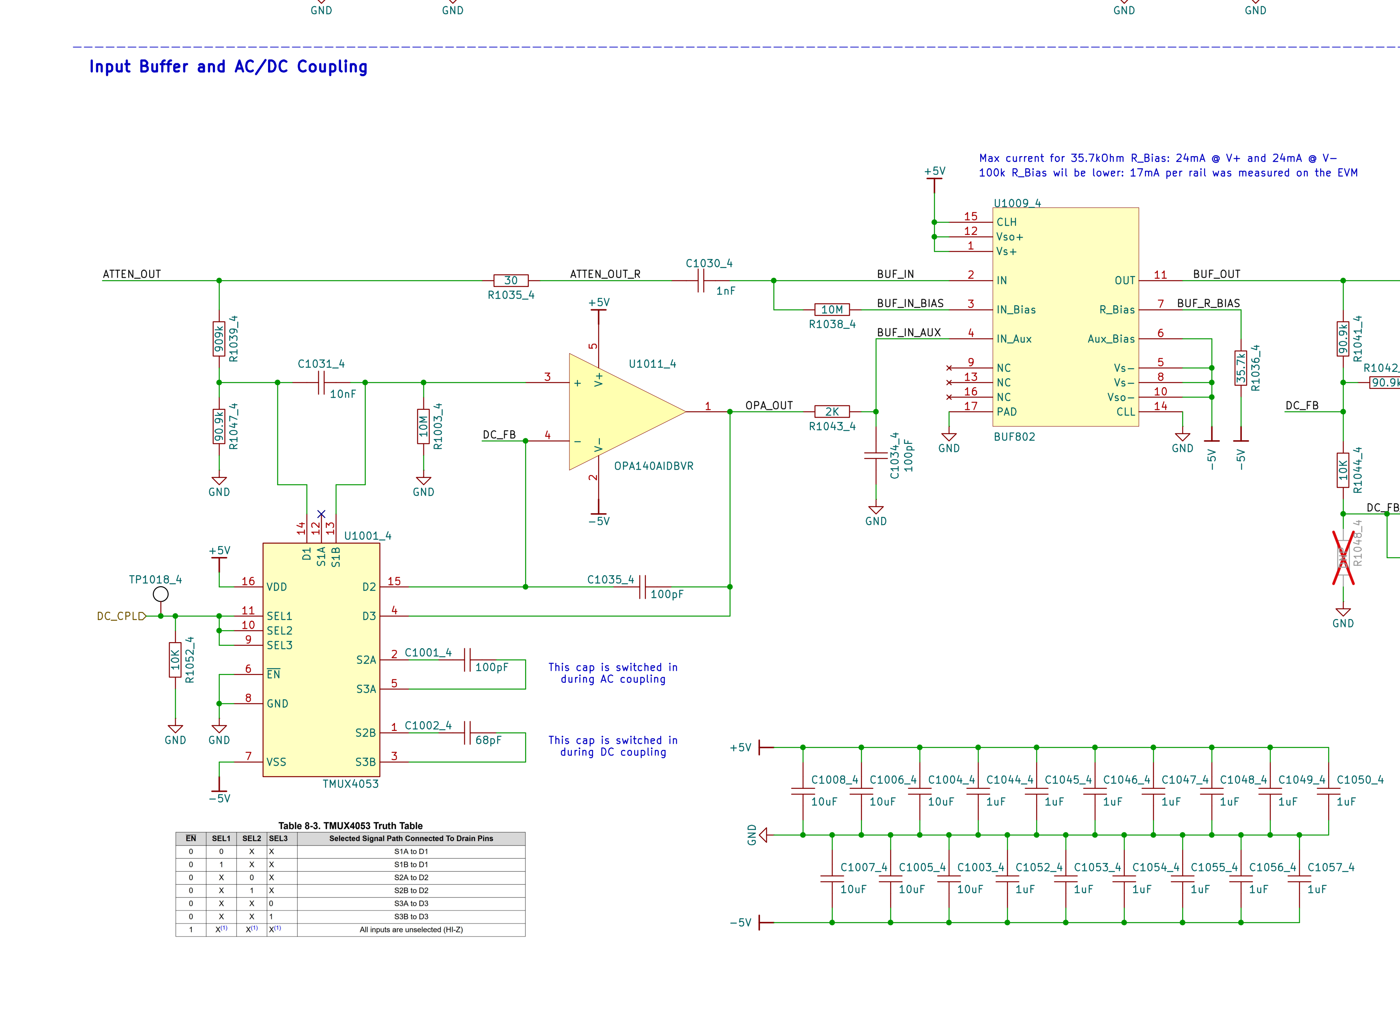
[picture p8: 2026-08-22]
docs/reference/scopefun/p2_buf.png

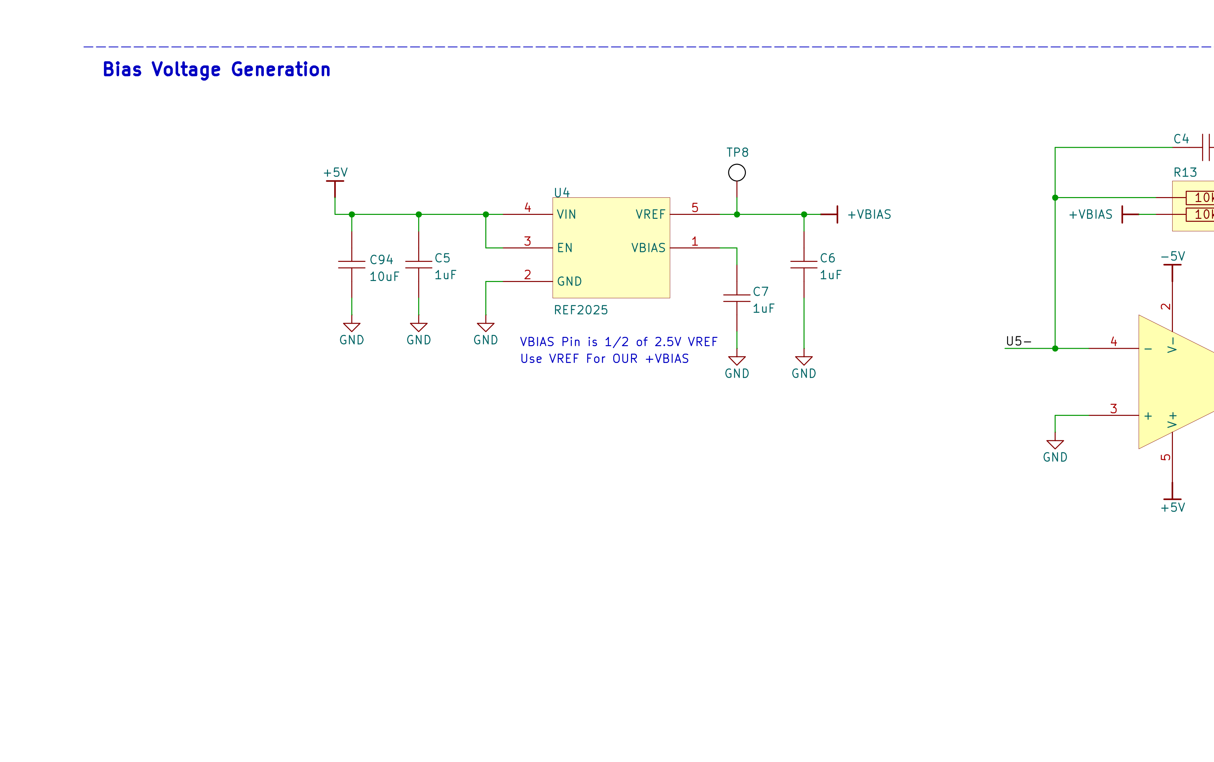
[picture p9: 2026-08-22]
docs/reference/scopefun/p10_bias.png

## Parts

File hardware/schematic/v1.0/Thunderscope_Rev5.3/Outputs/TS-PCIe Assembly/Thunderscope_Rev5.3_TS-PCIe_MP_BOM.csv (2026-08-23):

Line Item | Qty | Value | Description | PACKAGE | Reference | MANUFACTURER | MANUFACTURER PART NUMBER | Substitutions Policy
1 | 149 | 1uF | 1 µF ±10% 25V Ceramic Capacitor X5R 0402 (1005 Metric) | 0402 | C1,C2,C3,C5,C6,C7,C8,C11,C16,C17,C18,C19,C24,C25,C48,C49,C50,C51,C52,C53,C54,C55,C56,C57,C58,C59,C60,C61,C62,C63,C68,C70_1,C70_2,C70_3,C70_4,C76,C78,C88,C89,C90,C91,C92,C102,C103,C104_1,C104_2,C104_3,C104_4,C105_1,C105_2,C105_3,C105_4,C112,C125,C126,C130,C138,C139,C140,C141,C148,C149,C150,C151,C154,C155,C156,C157,C164,C165,C166,C167,C191,C1009_1,C1009_2,C1009_3,C1009_4,C1010_1,C1010_2,C1010_3,C1010_4,C1036_1,C1036_2,C1036_3,C1036_4,C1037_1,C1037_2,C1037_3,C1037_4,C1038_1,C1038_2,C1038_3,C1038_4,C1043_1,C1043_2,C1043_3,C1043_4,C1044_1,C1044_2,C1044_3,C1044_4,C1045_1,C1045_2,C1045_3,C1045_4,C1046_1,C1046_2,C1046_3,C1046_4,C1047_1,C1047_2,C1047_3,C1047_4,C1048_1,C1048_2,C1048_3,C1048_4,C1049_1,C1049_2,C1049_3,C1049_4,C1050_1,C1050_2,C1050_3,C1050_4,C1052_1,C1052_2,C1052_3,C1052_4,C1053_1,C1053_2,C1053_3,C1053_4,C1054_1,C1054_2,C1054_3,C1054_4,C1055_1,C1055_2,C1055_3,C1055_4,C1056_1,C1056_2,C1056_3,C1056_4,C1057_1,C1057_2,C1057_3,C1057_4 | Murata | GRM155R61E105KA12D | Any Parametric Equivalent
2 | 4 | 68pF | 68 pF ±1% 50V Ceramic Capacitor C0G, NP0 0402 (1005 Metric) | 0402 | C1002_1,C1002_2,C1002_3,C1002_4 | Murata | GCM1555C1H680FA16J | Any Parametric Equivalent
3 | 12 | 3pF | 3 pF ±0.1pF 200V Ceramic Capacitor C0G, NP0 0402 (1005 Metric) | 0402 | C1011_1,C1011_2,C1011_3,C1011_4,C1021_1,C1021_2,C1021_3,C1021_4,C1023_1,C1023_2,C1023_3,C1023_4 | KEMET | CBR04C309B2GAC | No Substitutions
4 | 4 | 0.3pF | 0.3 pF ±0.01pF Thin Film Capacitor 100 V 0402 | 0402 | C1012_1,C1012_2,C1012_3,C1012_4 | KYOCERA AVX | 04021J0R3ZBSTR | No Substitutions
5 | 4 | 1pF | 1 pF ±0.05pF 50V Ceramic Capacitor C0G, NP0 0402 (1005 Metric) | 0402 | C1024_1,C1024_2,C1024_3,C1024_4 | KEMET | CBR04C109A5GAC | No Substitutions
6 | 4 | 8pF | 8 pF ±0.1pF 50V Ceramic Capacitor C0G, NP0 0402 (1005 Metric) | 0402 | C1025_1,C1025_2,C1025_3,C1025_4 | KEMET | CBR04C809B5GAC | No Substitutions
7 | 4 | 1nF | 1000 pF ±1% 100V Ceramic Capacitor C0G, NP0 0603 (1608 Metric) | 0603 | C1030_1,C1030_2,C1030_3,C1030_4 | Murata | GCM1885C2A102FA16D | ECO Required for Substitution
8 | 4 | 10nF | 10000 pF ±5% 50V Ceramic Capacitor C0G, NP0 0603 (1608 Metric) | 0603 | C1031_1,C1031_2,C1031_3,C1031_4 | Murata | GRM1885C1H103JA01J | ECO Required for Substitution
9 | 4 | 18pF | 18 pF ±1% 50V Ceramic Capacitor C0G, NP0 0402 (1005 Metric) | 0402 | C1058_1,C1058_2,C1058_3,C1058_4 | KEMET | CBR04C180F5GAC | No Substitutions
10 | 4 | 2-6pF | 2 ~ 6pF Trimmer Capacitor 100 V Top Surface Mount | 2-SMD (4.5x3.2mm) | C1059_1,C1059_2,C1059_3,C1059_4 | EW Electronics | SGC3S060 | ECO Required for Substitution
11 | 30 | 22uF | 22 µF ±20% 25V Ceramic Capacitor X5R 0805 (2012 Metric) | 0805 | C12,C22,C75,C80,C83,C84,C97,C98,C101,C128,C176,C177,C180,C188,C1026_1,C1026_2,C1026_3,C1026_4,C1027_1,C1027_2,C1027_3,C1027_4,C1028_1,C1028_2,C1028_3,C1028_4,C1029_1,C1029_2,C1029_3,C1029_4 | Murata | GRM21BR61E226ME44L | Any Parametric Equivalent
12 | 36 | 100nF | 0.1 µF ±10% 16V Ceramic Capacitor X7R 0402 (1005 Metric) | 0402 | C13,C27,C44,C45,C65,C66,C67,C77,C81,C82,C123,C124,C129,C169,C170,C171,C172,C185,C189,C190,C1032_1,C1032_2,C1032_3,C1032_4,C1033_1,C1033_2,C1033_3,C1033_4,C1041_1,C1041_2,C1041_3,C1041_4,C1042_1,C1042_2,C1042_3,C1042_4 | Murata | GCM155R71C104KA55D | Any Parametric Equivalent
13 | 8 | 220nF | 0.22 µF ±10% 16V Ceramic Capacitor X7R 0402 (1005 Metric) | 0402 | C28,C29,C32,C33,C36,C37,C40,C41 | Murata | GCM155R71C224KE02D | Any Parametric Equivalent
14 | 17 | 100pF | 100 pF ±1% 50V Ceramic Capacitor C0G, NP0 0402 (1005 Metric) | 0402 | C4,C74,C174,C178,C186,C1001_1,C1001_2,C1001_3,C1001_4,C1034_1,C1034_2,C1034_3,C1034_4,C1035_1,C1035_2,C1035_3,C1035_4 | Murata | GCM1555C1H101FA16D | Any Parametric Equivalent
15 | 25 | 0 | 0 Ohms Jumper Chip Resistor 0402 (1005 Metric) Moisture Resistant Thick Film | 0402 | C64,R3,R5,R25,R26,R29,R30,R33,R34,R37,R38,R41,R52_1,R52_2,R52_3,R52_4,R83,R97_1,R97_2,R97_3,R97_4,R1053_1,R1053_2,R1053_3,R1053_4 | Yageo | RC0402JR-070RL | Any Parametric Equivalent
16 | 8 | 47uF | 47 µF ±20% 6.3V Ceramic Capacitor X5R 0805 (2012 Metric) | 0805 | C86,C87,C144,C145,C152,C153,C160,C161 | Samsung | CL21A476MQYNNNE | Any Parametric Equivalent
17 | 85 | 10uF | 10 µF ±20% 25V Ceramic Capacitor X5R 0603 (1608 Metric) | 0402 | C9,C10,C14,C15,C20,C21,C23,C26,C69_1,C69_2,C69_3,C69_4,C71,C72,C73,C79,C85,C93,C94,C95,C96,C106,C107,C108,C109,C110,C111,C114,C115,C116,C117,C118,C119,C120,C121,C122,C142,C143,C146,C147,C158,C159,C162,C163,C168,C173,C175,C179,C181,C182,C183,C184,C187,C1003_1,C1003_2,C1003_3,C1003_4,C1004_1,C1004_2,C1004_3,C1004_4,C1005_1,C1005_2,C1005_3,C1005_4,C1006_1,C1006_2,C1006_3,C1006_4,C1007_1,C1007_2,C1007_3,C1007_4,C1008_1,C1008_2,C1008_3,C1008_4,C1039_1,C1039_2,C1039_3,C1039_4,C1040_1,C1040_2,C1040_3,C1040_4 | Murata | GRM188R61E106MA73D | Any Parametric Equivalent
18 | 1 | RGB | Red, Green, Blue (RGB) 625nm Red, 525nm Green, 465nm Blue LED Indication - Discrete 1.8V Red, 2.7V Green, 2.7V Blue 4-SMD, No Lead | 4-SMD | D1 | Kingbright | APFA3010LSEKJ3ZGKQBC | ECO Required for Substitution
19 | 8 | 1N4148WT-7 | Diode 80 V 125mA Surface Mount SOD-523 | SOD-523 | D1000_1,D1000_2,D1000_3,D1000_4,D1001_1,D1001_2,D1001_3,D1001_4 | Diodes | 1N4148WT-7 | ECO Required for Substitution
20 | 2 | TPD1E1B04 | 8.5V (Typ) Clamp 6.3A (8/20µs) Ipp Tvs Diode Surface Mount 2-X1SON (1x.60) | 2-X1SON (1x0.6mm) | D4,D5 | Texas Instruments | TPD1E1B04DPYR | No Substitutions
21 | 2 | 2286211-3 | RFI Shield Finger, Surface Mount | Surface Mount | EMI1,EMI2 | TE Connectivity | 2286211-3 | No Substitutions
22 | 15 | 120@100MHZ | 120 Ohms @ 100 MHz 1 Power Line Ferrite Bead 0402 (1005 Metric) 2A 55mOhm | 0402 | FB1,FB2,FB3,FB11,FB12,FB13,FB1000_1,FB1000_2,FB1000_3,FB1000_4,FB1001_1,FB1001_2,FB1001_3,FB1001_4,R91 | Murata | BLM15PX121SN1D | No Substitutions
23 | 1 | 1.27mm 6 Pin TH | 2x5 Pin 0.050" (1.27mm) Through Hole, Right Angle Header | Through Hole | J3 | CNC Tech | 3220-10-0200-00 | ECO Required for Substitution
24 | 1 | TSW-101-16-G-Q-RA | 2 Pin, 0.200" (5.08mm), Through Hole, Right Angle Header | Through Hole | J4 | Samtec | TSW-101-16-G-Q-RA | ECO Required for Substitution
25 | 1 | 2.54mm 6 Pin TH | 6 pin 0.100" (2.54mm) Through Hole, Right Angle Header | Through Hole | J5 | Wurth Electronics | 61300611021 | ECO Required for Substitution
26 | 1 | F300-1B7H1-11036-E100 | 36 Position FFC, FPC Connector Contacts, Bottom 0.020" (0.50mm) Surface Mount, Right Angle | Surface Mount | J9 | Amphenol ICC | F300-1B7H1-11036-E100 | No Substitutions
27 | 4 | BNC | 50 Ohm BNC Jack, Through Hole, Right Angle | Through Hole | J1002_1,J1002_2,J1002_3,J1002_4 | Molex | 73100-0105 | No Substitutions
28 | 2 | 009155002852006 | 2 Position Spring Battery Contact Connector Surface Mount, Right Angle | Surface Mount | J12,J13 | KYOCERA AVX | 009155002852006 | No Substitutions
29 | 8 | UD2-4.5NUN-L | DPDT (2 Form C) Relay, 4.5V Coil Voltage, Surface Mount | Surface Mount | K1000_1,K1000_2,K1000_3,K1000_4,K1001_1,K1001_2,K1001_3,K1001_4 | KEMET | UD2-4.5NUN-L | No Substitutions
30 | 4 | 1uH | 1 µH Shielded Drum Core, Wirewound Inductor 5.5 A 32mOhm Max 1210 (3225 Metric) | 1210 | L2,L3,L4,L5 | Bourns | SRP3212-1R0M | ECO Required for Substitution
31 | 11 | DMN62D0UW | N-Channel 60 V 340mA (Ta) 320mW (Ta) Surface Mount SOT-323 | SOT-323 | Q1,Q2,Q3,Q1002_1,Q1002_2,Q1002_3,Q1002_4,Q1003_1,Q1003_2,Q1003_3,Q1003_4 | Diodes | DMN62D0UW-7 | ECO Required for Substitution
32 | 1 | 10K | 10k Ohm ±0.1% 125mW Power Per Element Isolated 2 Resistor Network/Array ±25ppm/°C 0606, Convex | 0606 | R13 | Vishay Beyschlag | ACASN1002S1002P1ATF1002X | No Substitutions
33 | 1 | 280K | 280 kOhms ±1% 0.063W, 1/16W Chip Resistor 0402 (1005 Metric) Automotive AEC-Q200, Moisture Resistant Thick Film | 0402 | R93 | Yageo | RC0402FR-07280KL | Any Parametric Equivalent
34 | 59 | 10K | 10 kOhms ±1% 0.063W, 1/16W Chip Resistor 0402 (1005 Metric) Moisture Resistant Thick Film | 0402 | R1,R8,R15,R16,R17,R45,R58,R59,R61,R62,R66,R67,R68,R76,R77,R80,R81,R86,R87,R92,R94,R101,R108,R111,R117,R118,R121,R124,R128,R129,R130,R1029_1,R1029_2,R1029_3,R1029_4,R1030_1,R1030_2,R1030_3,R1030_4,R1031_1,R1031_2,R1031_3,R1031_4,R1032_1,R1032_2,R1032_3,R1032_4,R1033_1,R1033_2,R1033_3,R1033_4,R1044_1,R1044_2,R1044_3,R1044_4,R1052_1,R1052_2,R1052_3,R1052_4 | Yageo | RC0402FR-0710KL | Any Parametric Equivalent
35 | 8 | 976k | 976 kOhms ±1% 0.1W, 1/10W Chip Resistor 0402 (1005 Metric) Automotive AEC-Q200 Thick Film | 0402 | R1002_1,R1002_2,R1002_3,R1002_4,R1024_1,R1024_2,R1024_3,R1024_4 | KOA Speer | RK73H1ETTP9763F | ECO Required for Substitution
36 | 8 | 10M | 10 MOhms ±1% 0.1W, 1/10W Chip Resistor 0603 (1608 Metric) Automotive AEC-Q200 Thick Film | 0603 | R1003_1,R1003_2,R1003_3,R1003_4,R1038_1,R1038_2,R1038_3,R1038_4 | KOA Speer | RK73H1JTTD1005F | No Substitutions
37 | 4 | 15 | 15 Ohms ±1% 0.5W, 1/2W Chip Resistor 0603 (1608 Metric) Automotive AEC-Q200, Pulse Withstanding Thick Film | 0603 | R1021_1,R1021_2,R1021_3,R1021_4 | KOA Speer | SG73P1JTTD15R0F | No Substitutions
38 | 8 | 30 | 30 Ohms ±1% 0.5W, 1/2W Chip Resistor 0603 (1608 Metric) Automotive AEC-Q200, Pulse Withstanding Thick Film | 0603 | R1022_1,R1022_2,R1022_3,R1022_4,R1035_1,R1035_2,R1035_3,R1035_4 | KOA Speer | SG73P1JTTD30R0F | No Substitutions
39 | 4 | 49.9 | 49.9 Ohms ±1% 1W Chip Resistor Wide 0805 (2012 Metric), 0508 Automotive AEC-Q200, Moisture Resistant Thick Film | 0508 | R1025_1,R1025_2,R1025_3,R1025_4 | KOA Speer | WK73R2ATTD49R9F | No Substitutions
40 | 8 | 22 | 22 Ohms ±1% 0.5W, 1/2W Chip Resistor 0603 (1608 Metric) Automotive AEC-Q200, Pulse Withstanding Thick Film | 0603 | R1027_1,R1027_2,R1027_3,R1027_4,R1028_1,R1028_2,R1028_3,R1028_4 | KOA Speer | SG73P1JTTD22R0F | No Substitutions
41 | 4 | 909k | 909 kOhms ±1% 0.063W, 1/16W Chip Resistor 0402 (1005 Metric) Moisture Resistant Thick Film | 0402 | R1039_1,R1039_2,R1039_3,R1039_4 | Yageo | RC0402FR-07909KL | Any Parametric Equivalent
42 | 4 | 2K TRIMPOT | 2 kOhms 0.15W J Lead Surface Mount Trimmer Potentiometer Cermet 1.0 Turn Top Adjustment | 2-SMD (3.8x3.6mm) | R1049_1,R1049_2,R1049_3,R1049_4 | Bourns | TC33X-2-202E | ECO Required for Substitution
43 | 4 | 120 | 120 Ohms ±1% 0.063W, 1/16W Chip Resistor 0402 (1005 Metric) Moisture Resistant Thick Film | 0402 | R131_1,R131_2,R131_3,R131_4 | Yageo | RC0402FR-07120RL | Any Parametric Equivalent
44 | 16 | 300 | 300 Ohms ±0.1% 0.063W, 1/16W Chip Resistor 0402 (1005 Metric) Automotive AEC-Q200 Thin Film | 0402 | R132_1,R132_2,R132_3,R132_4,R133_1,R133_2,R133_3,R133_4,R134_1,R134_2,R134_3,R134_4,R135_1,R135_2,R135_3,R135_4 | Panasonic | ERA-2AEB301X | ECO Required for Substitution
45 | 8 | 4.99 | 4.99 Ohms ±1% 0.063W, 1/16W Chip Resistor 0402 (1005 Metric) Moisture Resistant Thick Film | 0402 | R136_1,R136_2,R136_3,R136_4,R137_1,R137_2,R137_3,R137_4 | Yageo | RC0402FR-074R99L | Any Parametric Equivalent
46 | 7 | 49.9 | 49.9 Ohms ±1% 0.063W, 1/16W Chip Resistor 0402 (1005 Metric) Moisture Resistant Thick Film | 0402 | R23,R43,R63,R1037_1,R1037_2,R1037_3,R1037_4 | Yageo | RC0402FR-0749R9L | Any Parametric Equivalent
47 | 10 | 0.01 | 10 mOhms ±1% 0.25W, 1/4W Chip Resistor 0603 (1608 Metric) Current Sense Thin Film | 0603 | R42,R57,R71,R89,R97,R98,R116,R120,R123,R126 | Susumu | RL0816T-R010-F | Any Parametric Equivalent
48 | 24 | 1K | 1 kOhms ±1% 0.063W, 1/16W Chip Resistor 0402 (1005 Metric) Moisture Resistant Thick Film | 0402 | R44,R48,R49,R50,R51,R52,R53,R65,R74,R85,R95,R125,R1001_1,R1001_2,R1001_3,R1001_4,R1045_1,R1045_2,R1045_3,R1045_4,R1046_1,R1046_2,R1046_3,R1046_4 | Yageo | RC0402FR-071KL | Any Parametric Equivalent
49 | 14 | 90.9k | 90.9 kOhms ±1% 0.063W, 1/16W Chip Resistor 0402 (1005 Metric) Moisture Resistant Thick Film | 0402 | R55,R96,R1041_1,R1041_2,R1041_3,R1041_4,R1042_1,R1042_2,R1042_3,R1042_4,R1047_1,R1047_2,R1047_3,R1047_4 | Yageo | RC0402FR-0790K9L | Any Parametric Equivalent
50 | 9 | 20k | 20 kOhms ±1% 0.063W, 1/16W Chip Resistor 0402 (1005 Metric) Moisture Resistant Thick Film | 0402 | R56,R100,R103,R105,R122,R1026_1,R1026_2,R1026_3,R1026_4 | Yageo | RC0402FR-0720KL | Any Parametric Equivalent
51 | 7 | 2K | 2 kOhms ±1% 0.063W, 1/16W Chip Resistor 0402 (1005 Metric) Moisture Resistant Thick Film | 0402 | R6,R64,R127,R1043_1,R1043_2,R1043_3,R1043_4 | Yageo | RC0402FR-072KL | Any Parametric Equivalent
52 | 6 | 100 | 100 Ohms ±1% 0.063W, 1/16W Chip Resistor 0402 (1005 Metric) Moisture Resistant Thick Film | 0402 | R7,R22,R60,R107,R112,R115 | Yageo | RC0402FR-07100RL | Any Parametric Equivalent
53 | 5 | 35.7k | 35.7 kOhms ±1% 0.063W, 1/16W Chip Resistor 0402 (1005 Metric) Moisture Resistant Thick Film | 0402 | R88,R1036_1,R1036_2,R1036_3,R1036_4 | Yageo | RC0402FR-0735K7L | Any Parametric Equivalent
54 | 15 | 4.7K | 4.7 kOhms ±1% 0.063W, 1/16W Chip Resistor 0402 (1005 Metric) Moisture Resistant Thick Film | 0402 | R9,R10,R11,R12,R46,R47,R69,R70,R73,R99,R102,R104,R113,R114,R119 | Yageo | RC0402FR-074K7L | Any Parametric Equivalent
55 | 2 | 0.1 | 100 mOhms ±1% 0.167W, 1/6W Chip Resistor 0402 (1005 Metric) Automotive AEC-Q200, Current Sense Thick Film | 0402 | R90,R106 | Panasonic | ERJ-2BSFR10X | Any Parametric Equivalent
56 | 4 | 2118728-2 | RF Shield Frame 0.728" (18.50mm) X 1.156" (29.36mm) Surface Mount | Surface Mount | SHLD1001_1,SHLD1001_2,SHLD1001_3,SHLD1001_4 | TE Connectivity | 2118728-2 | No Substitutions
57 | 1 | SN74LVC1G17 | Buffer, Non-Inverting 1 Element 1 Bit per Element Push-Pull Output SC-70-5 | SC-70-5 | U1 | Texas Instruments | SN74LVC1G17DCKR | ECO Required for Substitution
58 | 1 | MCP4452-104E | Digital Potentiometer 100k Ohm 4 Circuit 257 Taps I2C Interface 14-TSSOP | 14-TSSOP | U2 | Microchip | MCP4452-104E | ECO Required for Substitution
59 | 1 | MCP4728 | 12 Bit Digital to Analog Converter 4 10-MSOP | 10-MSOP | U3 | Microchip | MCP4728T-E/UN | ECO Required for Substitution
60 | 1 | REF2025 | Series Voltage Reference IC Fixed 1.24V, 2.5V V ±0.05% 20 mA SOT-23-THIN | SOT-23-5 | U4 | Texas Instruments | REF2025AIDDCR | No Substitutions
61 | 1 | HMCAD1520 | 8, 12, 14, 16 Bit Analog to Digital Converter 1, 2, 4 Input 4 Pipelined 48-QFN (7x7) | 48-QFN (7x7mm) | U6 | Analog Devices | HMCAD1520 | No Substitutions
62 | 1 | ZL30260LDG1 | Clock Multiplier, Frequency Synthesizer IC 1.045GHz 1 56-VFQFN Exposed Pad | 56-VFQFN (8x8mm) | U7 | Microchip | ZL30260LDG1 | No Substitutions
63 | 1 | FIN1019MTCX | 1/1 Transceiver Full LVDS 14-TSSOP | 14-TSSOP | U10 | onsemi | FIN1019MTCX | No Substitutions
64 | 1 | TPSM82913 | Non-Isolated PoL Module DC DC Converter 1 Output 0.8 ~ 5.5V 3A 3V - 17V Input, 28-B0QFN (4.5x5.5) | 28-B0QFN (4.5x5.5mm) | U11 | Texas Instruments | TPSM82913RDUR | No Substitutions
65 | 1 | LM27761 | Charge Pump Switching Regulator IC Negative Adjustable -1.5V 1 Output 250mA 8-WFDFN Exposed Pad | 8-WFDFN (2x2mm) | U13 | Texas Instruments | LM27761DSGR | No Substitutions
66 | 1 | IC FPGA XC7A35T-2CSG325C | Artix-7 FPGA, 150 User I/Os, 4 GTP, 324-Ball BGA, Speed Grade 2, Commercial Grade, Pb-Free | 324-BGA (15x15mm) | U18 | Xilinx | XC7A35T-2CSG325C | No Substitutions | Note that this part has changed from the XC7A50T-2CSG325C used on PVT
67 | 1 | MX25L6433FZNI-08G | FLASH - NOR Memory IC 64Mbit SPI - Quad I/O 133 MHz 8-WSON (6x5) | 8-WSON (6x5mm) | U19 | Macronix | MX25L6433FZNI-08G-TR | ECO Required for Substitution
68 | 4 | TMUX4053 | 3 Circuit IC Switch 2:1 240Ohm 16-SOT-23-THIN | 16-SOT-23-THIN | U1001_1,U1001_2,U1001_3,U1001_4 | Texas Instruments | TMUX4053DYYR | No Substitutions
69 | 4 | LMH6518 | Variable Gain Amplifier 1 Circuit Differential 16-WQFN (4x4) | 16-WQFN (4x4mm) | U1008_1,U1008_2,U1008_3,U1008_4 | Texas Instruments | LMH6518SQX/NOPB | No Substitutions
70 | 4 | BUF802 | J-FET Amplifier 1 Circuit Push-Pull 16-VQFN (3x3) | 16-VQFN (3x3mm) | U1009_1,U1009_2,U1009_3,U1009_4 | Texas Instruments | BUF802IRGTR | No Substitutions
71 | 4 | ADA4930-1YCPZ | Differential Amplifier 1 Circuit Differential 16-LFCSP-VQ (3x3) | 16-QFN (3x3mm) | U12_1,U12_2,U12_3,U12_4 | Analog Devices | ADA4930-1YCPZ-R7 | No Substitutions
72 | 3 | TPS7A9101 | Linear Voltage Regulator IC Positive Adjustable 1 Output 1.05A 10-SON (2.5x2.5) | 10-DFN (2.5x2.5mm) | U14,U15,U22 | Texas Instruments | TPS7A9101DSKR | No Substitutions
73 | 5 | OPA140AIDBVR | J-FET Amplifier 1 Circuit Rail-to-Rail SOT-23-5 | SOT-23-5 | U5,U1011_1,U1011_2,U1011_3,U1011_4 | Texas Instruments | OPA140AIDBVR | No Substitutions
74 | 4 | TPS62A02 | Buck Switching Regulator IC Positive Adjustable 0.6V 1 Output 2A SOT-563 | SOT-563 | U8,U20,U21,U23 | Texas Instruments | TPS62A02DRLR | No Substitutions
75 | 2 | NCP161ASN330T1G | Linear Voltage Regulator IC Positive Fixed 1 Output 450mA SOT-23-5 | SOT-23-5 | U9,U16 | onsemi | NCP161ASN330T1G | No Substitutions
76 | 1 | 10MHz | 10 MHz ±2.5ppm TCXO HCMOS Oscillator 1.6V ~ 3.6V Enable/Disable 4-SMD, No Lead | 4-SMD (3.2x2.5mm) | Y1 | ECS International | ECS-TXO-3225MV-100-TR | ECO Required for Substitution
77 | 1 | 25MHz | 25 MHz ±2.5ppm TCXO HCMOS Oscillator 3.3V Enable/Disable 4-SMD, No Lead | 4-SMD (2.0x1.6mm) | Y2 | ECS International | ECS-TXO-2016-33-250-TR | ECO Required for Substitution

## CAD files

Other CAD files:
tools/LC_3D_Module_Download-master/step/ANT-SMD_KH-IPEX-K501-29.step

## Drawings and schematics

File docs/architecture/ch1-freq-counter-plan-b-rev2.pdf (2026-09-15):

D E S I G N P L A N · F R E Q U E N C Y M E A S U R E M E N T P A T H · R E V . 2

# CH1 测频方案 B 修订版：去耦移到背面，AUX 全程顶层

把挡在 AUX 引脚上方的 C1037_1、FB1000_1、C1040_1 翻到背面，腾出顶层通道。AUX_P/N 从 pin1、pin2 引出后全程走 顶层、不打过孔，拐角全部为 45°，接到 RF3、RF4；主输出 CH1_P/N 保持原样。 本文替代上一版方案 B（In2 内层走线）。 走线已在 PCB 副本上画出并通过 DRC，原工程没有改动。标 推断 或 待确认 的结论，没有直接依据或还需要进一步核对。

工程 | Thunderscope_Rev5.3_CH1
器件 | U1008_1 · LMH6518
手册 | ZHCSPP6E（2024-07 修订）
验证 | kicad-cli 10.0.4 DRC（副本）
日期 | 2026-09-15
状态 | 方案草稿 · 尚未改图

结论

## 1 AUX 零过孔，DRC 已验证

两根线在顶层全程保持 0.13 mm 间距，拐角全部 45°（程序 检查最大转角 45°），与其他网络最近 0.19 mm。线宽和网 络类规则与 OUT_P/N 完全相同，不新增规则。在副本上跑

### DRC：违规项 42 条，类型和数量都与改动前相同；AUX 的

4 个未连接项全部消除。

## 2 只动三个件，就近去耦保留

真正挡路的只有 C1037_1、FB1000_1、C1040_1。 C1036_1、C1038_1、C1039_1 在 pin3、pin4 左侧，留在 顶层原位，仍经 +VPGA 铺铜直连引脚。离引脚最近的电容 焊盘仍是 0.43 mm，和原设计相同。

## 3 比上一版少了三项代价

不再切 In2 电源铺铜，不再需要 0.15 mm 的极限间距， C1037 也不用绕线接地。代价是这三个件变成背面贴装（板 背面本来就有贴片件），+5V 馈电过孔要挪位置，J3_1、 J4_1 仍需删除。

## 三种做法对照

项目 | 上一版方案 B · 走 In2 | 本修订版 · 搬 3 个件 | 整块搬到背面 | 结论
AUX 过孔 | 4 个 | 0 | 0 | 修订版
In2 电源铺铜 | 让出一个角 | 不动 | 不动 | 修订版
最紧间距（异网络） | 约 0.15 mm | 0.19 mm | 约 0.18 mm | 修订版
pin3/pin4 就近去耦 | 顶层，C1037 绕线接地 | C1036、C1038、C1039 仍在顶层 | 全部隔着过孔 | 修订版
背面新增元件 | 无 | 3 个 | 6 个 | 上一版
网络类规则 | 新建 FE_AUX_Diff | 不新增，与 OUT_P/N 相同 | 同修订版 | 修订版
AUX 线长 P / N | 25.7 / 24.5 mm | 29.2 / 28.1 mm | 约 30 / 29 mm | 都可忽略

三种做法都验证过 DRC。整块搬到背面同样能走通，但 C1036、C1038、C1039 本来就不挡路，全部搬走只会让去耦多隔一层过孔（按 1.5 mm 板厚估算，每个过孔约 1.35 nH 推断 ），所以不推荐。

CH1 测频方案 B 修订版 · Thunderscope_Rev5.3_CH1 | 第 1 / 6 页

## PGA 周边：顶层与背面（按 PCB 坐标生成，按比例）

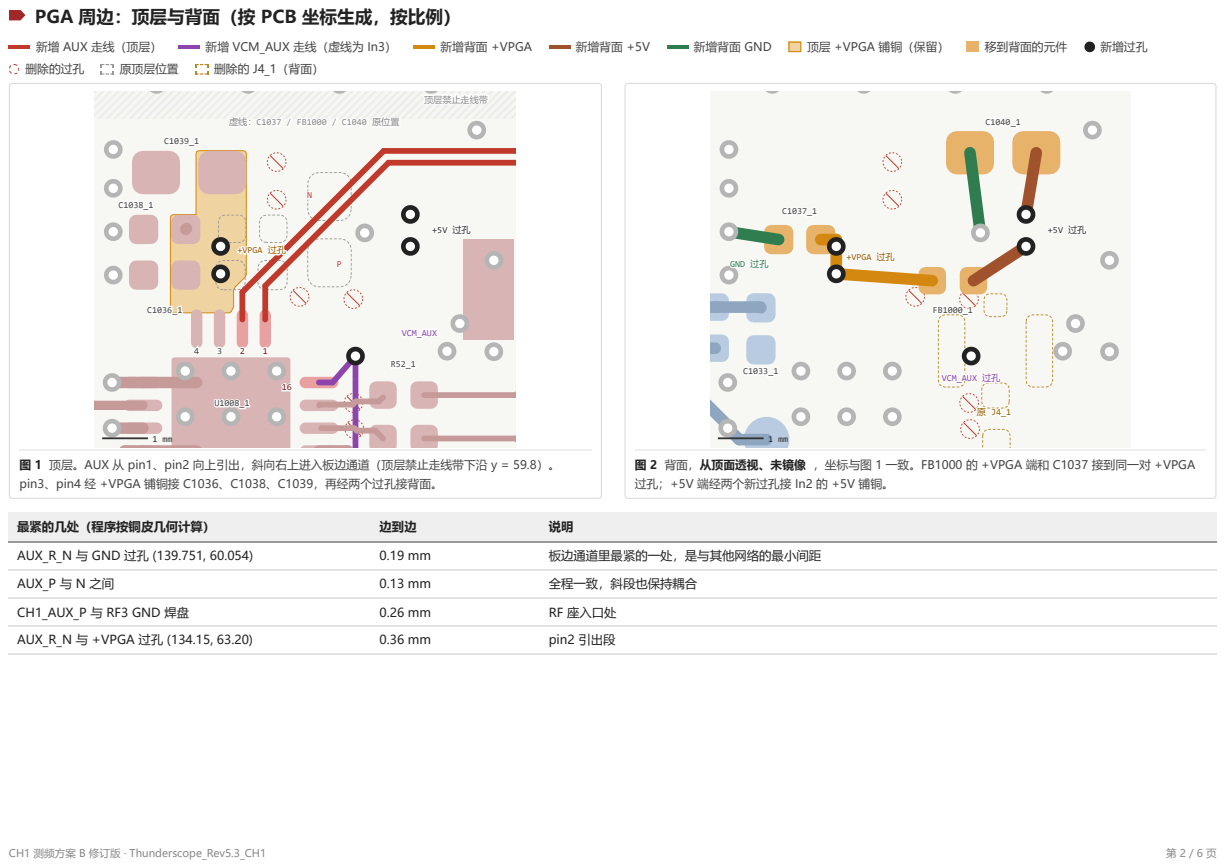
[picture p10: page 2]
新增 AUX 走线（顶层）; 新增 VCM_AUX 走线（虚线为 In3）; 新增背面 +VPGA; 新增背面 +5V; 新增背面 GND; 顶层 +VPGA 铺铜（保留）; 移到背面的元件; 新增过孔; 删除的过孔; 原顶层位置; 删除的 J4_1（背面）; ++5V 5V 过过孔孔; VVCM_AUX CM_AUX; 顶顶层禁止走线带 层禁止走线带; 虚虚线：线：CC1037 / FB1000 / C1040 1037 / FB1000 / C1040 原原位置位置; FFB1000_1 B1000_1; VVCM_AUX CM_AUX 过过孔孔; 最紧的几处（程序按铜皮几何计算）; 边到边; AUX_R_N 与 GND 过孔 (139.751, 60.054); 板边通道里最紧的一处，是与其他网络的最小间距; AUX_P 与 N 之间; 全程一致，斜段也保持耦合; CH1_AUX_P 与 RF3 GND 焊盘; RF 座入口处; AUX_R_N 与 +VPGA 过孔 (134.15, 63.20); pin2 引出段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

++VPGA VPGA 过过孔孔

GGND ND 过过孔孔

图 1 顶层。AUX 从 pin1、pin2 向上引出，斜向右上进入板边通道（顶层禁止走线带下沿 y = 59.8）。
pin3、pin4 经 +VPGA 铺铜接 C1036、C1038、C1039，再经两个过孔接背面。

图 2 背面，从顶面透视、未镜像 ，坐标与图 1 一致。FB1000 的 +VPGA 端和 C1037 接到同一对 +VPGA
过孔；+5V 端经两个新过孔接 In2 的 +5V 铺铜。

## 全程走线与去耦对比

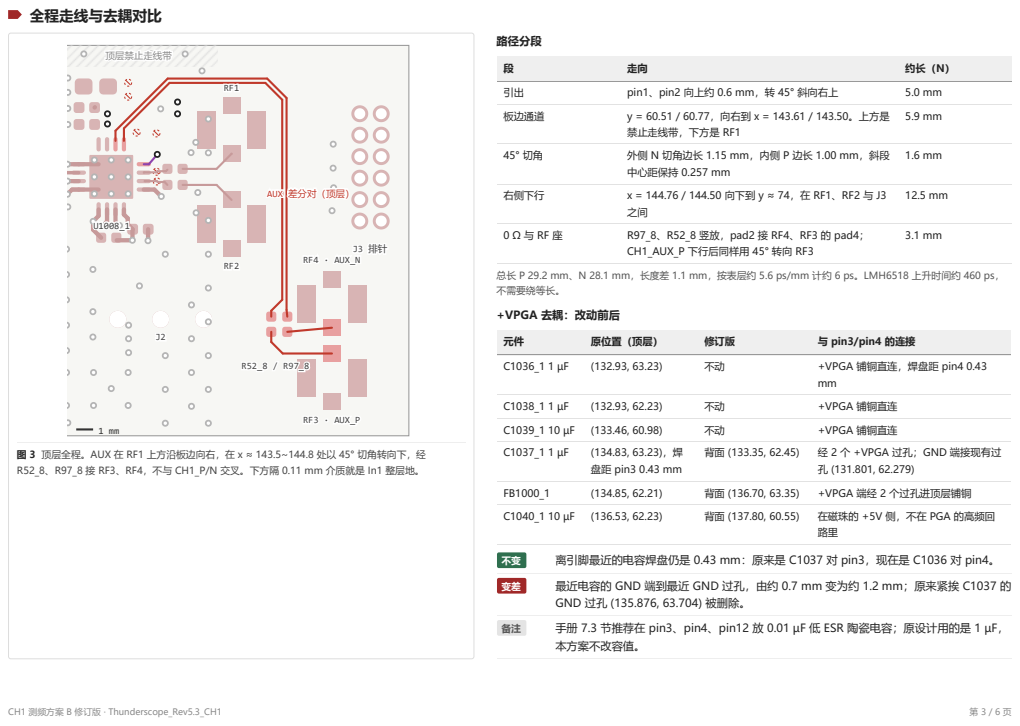
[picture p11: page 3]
RRF11; RRF22; RRFF44 ·· AAUUXX__NN; RRFF33 ·· AAUUXX__PP; J33 排排针针; AAUUXX; 差差分分对对（（顶顶层层））; 顶顶层层禁禁止止走走线线带带; 路径分段; pin1、pin2 向上约 0.6 mm，转 45° 斜向右上; 板边通道; y = 60.51 / 60.77，向右到 x = 143.61 / 143.50。上方是; 禁止走线带，下方是 RF1; 外侧 N 切角边长 1.15 mm，内侧 P 边长 1.00 mm，斜段; 中心距保持 0.257 mm; 右侧下行; x = 144.76 / 144.50 向下到 y ≈ 74，在 RF1、RF2 与 J3; R97_8、R52_8 竖放，pad2 接 RF4、RF3 的 pad4；; CH1_AUX_P 下行后同样用 45° 转向 RF3; 原位置（顶层）; 修订版; 与 pin3/pin4 的连接; +VPGA 铺铜直连，焊盘距 pin4 0.43; +VPGA 铺铜直连; 盘距 pin3 0.43 mm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

总长 P 29.2 mm、N 28.1 mm，长度差 1.1 mm，按表层约 5.6 ps/mm 计约 6 ps。LMH6518 上升时间约 460 ps，
不需要绕等长。
+VPGA 去耦：改动前后

图 3 顶层全程。AUX 在 RF1 上方沿板边向右，在 x ≈ 143.5~144.8 处以 45° 切角转向下，经
R52_8、R97_8 接 RF3、RF4，不与 CH1_P/N 交叉。下方隔 0.11 mm 介质就是 In1 整层地。

GND 过孔 (135.876, 63.704) 被删除。
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

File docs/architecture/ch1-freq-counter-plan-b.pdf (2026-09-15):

D E S I G N P L A N · F R E Q U E N C Y M E A S U R E M E N T P A T H

# CH1 测频方案 B：在 PCB 上把 AUX 引出来

把 LMH6518 的辅助输出 AUX_P/N 引到 RF3、RF4 两个 IPEX 座，专门给测频用，主输出 CH1_P/N 保持原样继续给 ADC 检 测。 下面的走线方案已经在 PCB 副本上实际画出来并通过了 DRC，原工程没有改动。标 推断 或 待确认 的结论，没有直接 依据或还需要进一步核对。

工程 | Thunderscope_Rev5.3_CH1
器件 | U1008_1 · LMH6518
手册 | ZHCSPP6E（2024-07 修订）
验证 | kicad-cli 10.0.4 DRC（副本）
日期 | 2026-09-15
状态 | 方案草稿 · 尚未改图

结论

## 1 能布通，DRC 已验证

pin1、pin2 在顶层从 C1037_1 下方 0.43 mm 的缝隙穿 出，在芯片右上方打孔下到 In2，从 RF1 下方绕到 RF3、 RF4。在副本上画完后跑 DRC：违规项仍是原来的 42 条， 没有新增；AUX 相关的 4 个未连接项全部消除。

## 2 代价在 PGA 周边

要删掉两个 DNP 的 UFL 测试座 J3_1、J4_1，拿掉 2 个 GND 过孔（补回 1 个），C1037_1 的地回路变长；In2 电 源铺铜右上角要让出一块；顶层引出线与相邻焊盘的间距只 有约 0.15 mm。另外 VCC 电流多约 60 mA。

## 3 换来两路互不干扰

测频走 AUX，有独立的输出级。比较器和它的端接不会挂在 ADC 通路上，两边的端接、共模和负载可以各自设计。 pin16 VCM_AUX 直接接到 VCM，不增加元件。

## 方案 A 与方案 B 对照

项目 | 方案 A · 主输出分路 | 方案 B · 引出 AUX | 更优
CH1 板元件 | 删 RF3、RF4、R52_8、R97_8 | 保留全部；删 DNP 的 J3_1、J4_1 | A 少 4 个件
PCB 改动量 | 从原理图更新即可，不改走线 | 新增约 55 mm 走线、6 个过孔，挪 2 个电阻、改 1 处铺铜 | A
PGA 去耦 | 不动 | C1037_1 地回路变长，少 1 个 GND 过孔 | A
测频与 ADC 的隔离 | 共用一路输出，靠接收板的分支设计或缓冲器隔离 | 两路独立输出级，互不影响 | B
档位冲突 | 两个用途共用同一个信号，档位完全一样 | 同样存在：AUX 跟随主输出的增益和带宽 | 相同
接收板 | 一个接收点，要做分路 | 两个接收点，各自端接，结构更简单 | B
功耗 | AUX 关闭，VCC 典型 150 mA | AUX 打开，VCC 典型 210 mA，最大 225 mA | A
固件 | 上电后要写 D10 = 1 | 保持上电默认（D10 = 0），但不能误写成 1 | B 略简单

方案 B 解决的只是"负载隔离"，解决不了"测频和 ADC 需要不同档位"的问题，因为手册写明 AUX 的增益和带宽都跟随主输出。如果主要顾虑是后者，两个方案都要靠固件分时切换。

CH1 测频方案 B · Thunderscope_Rev5.3_CH1 | 第 1 / 5 页

## 走线方案（按 PCB 坐标生成，按比例）

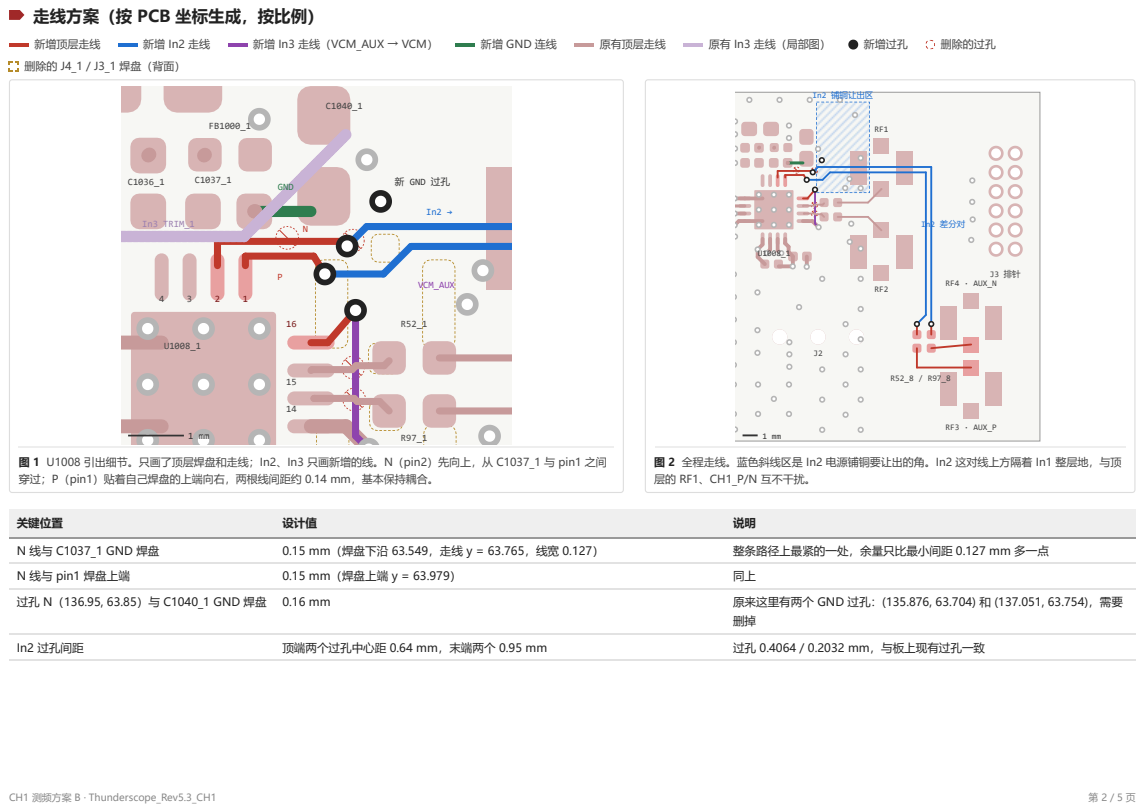
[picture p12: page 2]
新增顶层走线; 新增 In3 走线（VCM_AUX → VCM）; 新增 GND 连线; 原有顶层走线; 原有 In3 走线（局部图）; 新增过孔; 删除的过孔; VCM_AUX; In3 TRIM_1; GND; 新 GND 过孔; RF4 · AUX_N; RF3 · AUX_P; In2 差分对; In2 铺铜让出区; 关键位置; 设计值; N 线与 C1037_1 GND 焊盘; 0.15 mm（焊盘下沿 63.549，走线 y = 63.765，线宽 0.127）; 整条路径上最紧的一处，余量只比最小间距 0.127 mm 多一点; N 线与 pin1 焊盘上端; 0.15 mm（焊盘上端 y = 63.979）; 过孔 N（136.95, 63.85）与 C1040_1 GND 焊盘 0.16 mm; 原来这里有两个 GND 过孔：(135.876, 63.704) 和 (137.051, 63.754)，需要; In2 过孔间距; 顶端两个过孔中心距 0.64 mm，末端两个 0.95 mm; 过孔 0.4064 / 0.2032 mm，与板上现有过孔一致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

删除的 J4_1 / J3_1 焊盘（背面）

图 1 U1008 引出细节。只画了顶层焊盘和走线；In2、In3 只画新增的线。N（pin2）先向上，从 C1037_1 与 pin1 之间
穿过；P（pin1）贴着自己焊盘的上端向右，两根线间距约 0.14 mm，基本保持耦合。

图 2 全程走线。蓝色斜线区是 In2 电源铺铜要让出的角。In2 这对线上方隔着 In1 整层地，与顶
层的 RF1、CH1_P/N 互不干扰。

## 改动清单

顺序：先改原理图和网络类规则，ERC 通过后从原理图更新 PCB，再按下表布线，最后跑 DRC。坐标单位是 mm，取自 PCB 文件；验证用的副本脚本就是按这些坐标画的。改图前请先在 KiCad 里保存 并关闭工程（目录下有 .lck 锁文件）。

位置 | 对象 | 操作 | 说明

原理图 · FE_Channel.kicad_sch

U1008_1 pin16 | VCM_AUX 接到网络 VCM | 加连线 | 放一个 VCM 网络标签即可。理由见第 4 页。
J3_1、J4_1 | UFL 测试座（DNP） | 删除 | 背面焊盘正好压在 AUX 和 VCM_AUX 的过孔位置上，而且本身是挂在 OUT_R_P/N 上的短截线
网络类与 DRC 规则 · kicad_pro / kicad_dru
网络类 | 新建 FE_AUX_Diff，匹配 */AUX_R_* | 新增 | /CH1_AUX_* 已经被 /CH1_* 规则归入 FE_100Z_Diff（只准表层、禁止过孔），所以换层必须放 在 0 Ω 之前的 AUX_R 段上
DRC 规则 | FE_AUX_Diff：内层线宽 0.127、间距 0.230；表层线宽 0.127、间距 0.130；过孔 ≤ 2 个 | 新增 | 线宽和间距照抄现有 LVDS 内层规则和 FE_100Z_Diff 表层规则

PCB · Thunderscope_Rev5.3.kicad_pcb

U1008 右上 | GND 过孔 (135.876, 63.704)、(137.051, 63.754) | 删除 | 腾出引出线和过孔的位置
U1008 右上 | GND 过孔 (137.55, 63.05)；GND 线 C1037_1 pad2 → C1040_1 pad1，线宽 0.2 | 新增 | C1037_1 的 GND 焊盘被 N 线挡住后，要靠这根线接到 C1040_1 的地
顶层 N | pin2 → (134.626, 63.765) → (136.85, 63.765) → 过孔 (136.95, 63.85) | 新增 | 网络 /CH1/AUX_R_N
顶层 P | pin1 → (135.126, 64.03) → (136.35, 64.03) → 过孔 (136.55, 64.35) | 新增 | 网络 /CH1/AUX_R_P
In2 N | (136.95, 63.85) → (137.30, 63.50) → (144.80, 63.50) → 过孔 (144.80, 73.90) | 新增 | 从 RF1 下方经过（RF1 是表贴件，不占内层）
In2 P | (136.55, 64.35) → (137.60, 64.35) → (138.09, 63.86) → (144.44, 63.86) → (144.44, 73.30) → 过孔 (143.85, 73.90) | 新增 | P 从 N 的过孔下方绕过，与 N 保持 0.357 mm 中心距
In2 铺铜 | 矩形 x 137.2~140.7、y 59.2~65.2 禁止铺铜 | 新增 | 否则电源铺铜被这对线切出窄颈，DRC 报最小连接宽度。区域内没有 +5V / −VBIAS 过孔
R52_8、R97_8 | 移到 (143.85, 75.05)、(144.80, 75.05)，旋转 270° | 移动 | pad1 朝上接过孔，pad2 朝下接 RF。原来放在板框外
顶层末段 | R97_8 pad2 → RF4 pad4；R52_8 pad2 → (143.85, 76.779) → RF3 pad4 | 新增 | /CH1_AUX_N、/CH1_AUX_P，只走表层、无过孔，符合 FE_100Z_Diff
VCM_AUX | pin16 → (136.6, 65.579) → 过孔 (137.1, 65.0)；In3 → (137.1, 67.25) → VCM 过孔 (137.337, 67.487) | 新增 | In3 这段会穿过 +3V3_PGA 铺铜，重新铺铜后自动避让
J3_1、J4_1 | 连同 OUT_R_P/N 上的 2 个过孔和 7 段背面短线 | 删除 | 顶层主输出走线保持连续，不受影响

BOM 不变（J3_1、J4_1 本来就不贴）。接口图册需要同步：AUX 这一项从"原工程未使用"改为"已引出"，J3_1、J4_1 相关的描述删除。

CH1 测频方案 B · Thunderscope_Rev5.3_CH1 | 第 3 / 5 页
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

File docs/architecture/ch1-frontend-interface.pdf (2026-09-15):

## H I E R A R C H I CA L S HE E T · INT E R FAC E R E F E R ENC E

# CH1 前端接口图册

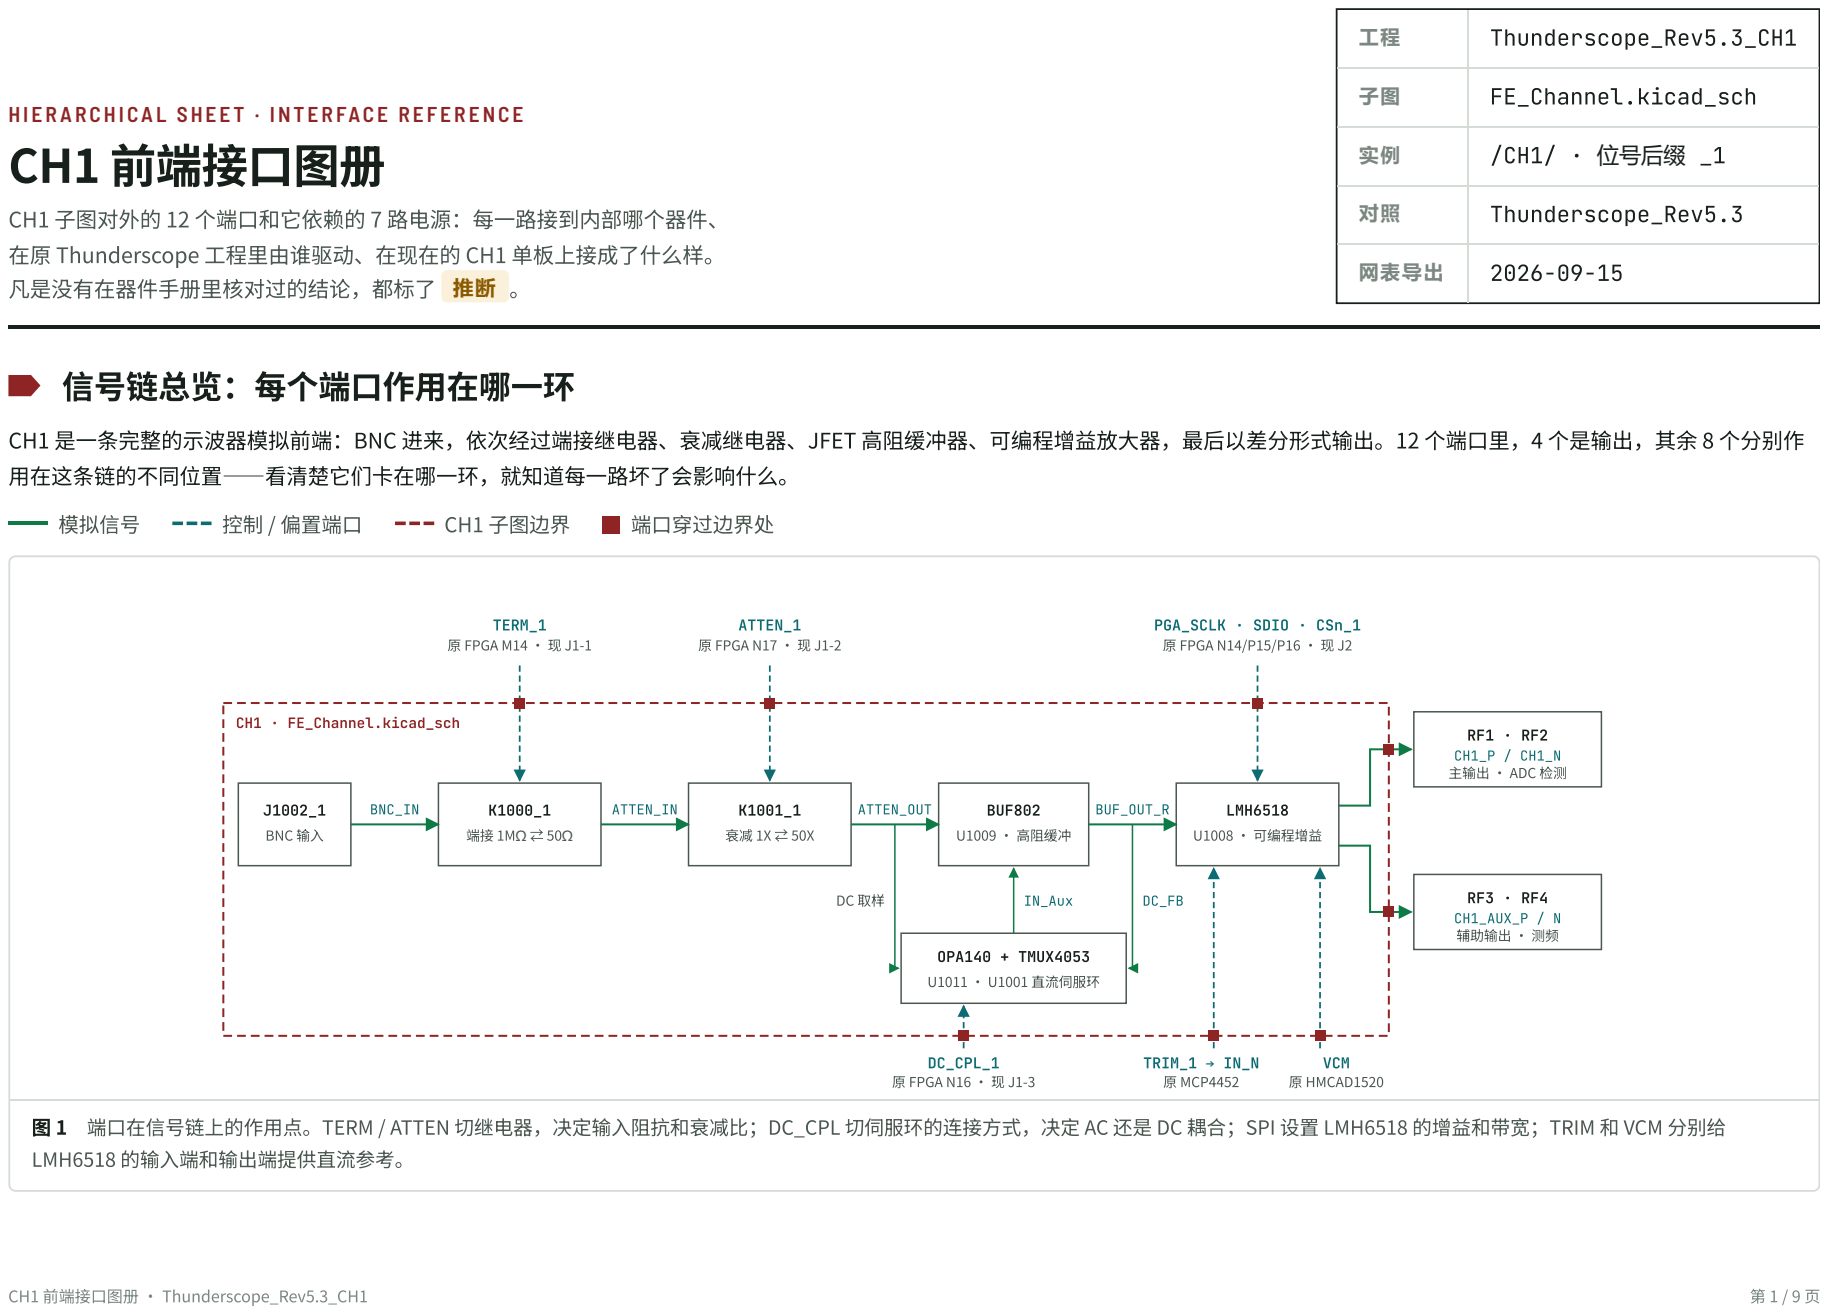
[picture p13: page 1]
CH1 前端接口图册 · Thunderscope_Rev5.3_CH1; Thunderscope_Rev5.3_CH1; FE_Channel.kicad_sch; /CH1/ · 位号后缀 _1; Thunderscope_Rev5.3; 网表导出; 信号链总览：每个端口作用在哪一环; 模拟信号; 控制 / 偏置端口; CH1 子图边界; 端口穿过边界处; CH1 · FE_Channel.kicad_sch; BNC 输入; BUF802; U1009 · 高阻缓冲; LMH6518; U1008 · 可编程增益; BNC_IN; ATTEN_IN; ATTEN_OUT; BUF_OUT_R; OPA140 + TMUX4053; U1011 · U1001 直流伺服环; IN_Aux; CH1_AUX_P / N 辅助输出 · 测频; TERM_1 原 FPGA M14 · 现 J1-1; ATTEN_1 原 FPGA N17 · 现 J1-2; PGA_SCLK · SDIO · CSn_1 原 FPGA N14/P15/P16 · 现 J2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

CH1 子图对外的 12 个端口和它依赖的 7 路电源：每一路接到内部哪个器件、
在原 Thunderscope 工程里由谁驱动、在现在的 CH1 单板上接成了什么样。
凡是没有在器件手册里核对过的结论，都标了 推断 。

CH1 是一条完整的示波器模拟前端：BNC 进来，依次经过端接继电器、衰减继电器、JFET 高阻缓冲器、可编程增益放大器，最后以差分形式输出。12 个端口里，4 个是输出，其余 8 个分别作
用在这条链的不同位置——看清楚它们卡在哪一环，就知道每一路坏了会影响什么。

主输出 · ADC 检测

图 1　端口在信号链上的作用点。TERM / ATTEN 切继电器，决定输入阻抗和衰减比；DC_CPL 切伺服环的连接方式，决定 AC 还是 DC 耦合；SPI 设置 LMH6518 的增益和带宽；TRIM 和 VCM 分别给
LMH6518 的输入端和输出端提供直流参考。

## 12 个端口一览

端口 | 顶层网络 | 方向 | CH1 内部去向 | 原工程来源 / 去向 | CH1 单板

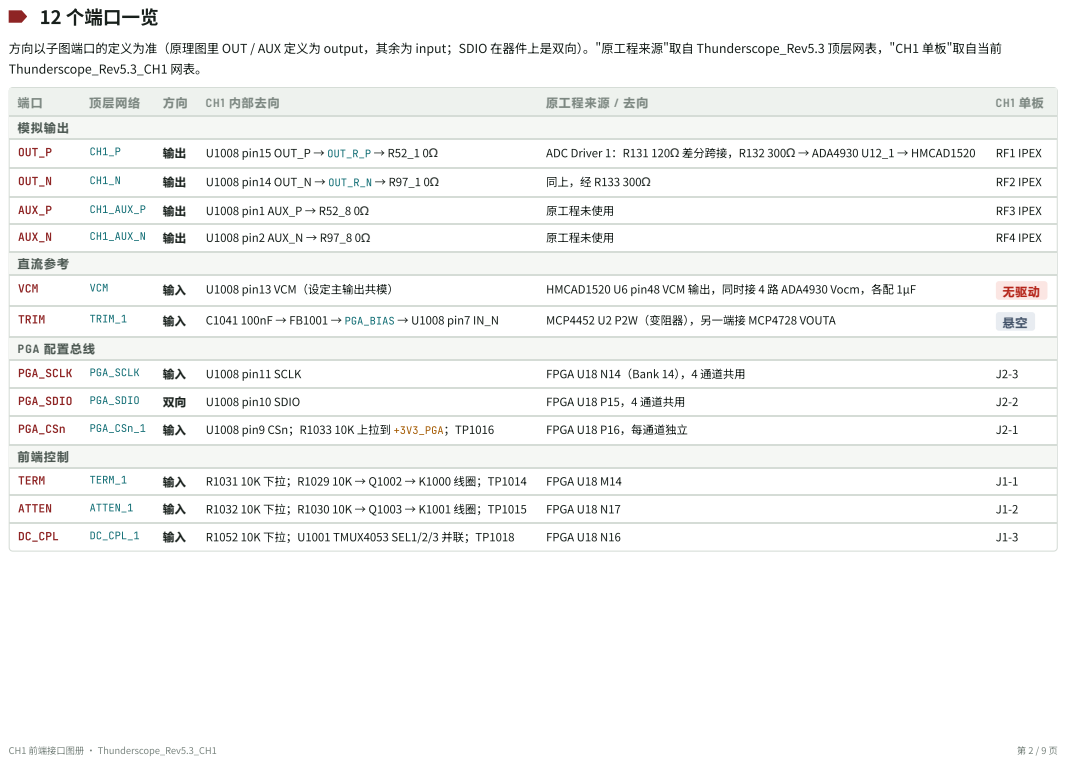
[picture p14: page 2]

方向以子图端口的定义为准（原理图里 OUT / AUX 定义为 output，其余为 input；SDIO 在器件上是双向）。"原工程来源"取自 Thunderscope_Rev5.3 顶层网表，"CH1 单板"取自当前
Thunderscope_Rev5.3_CH1 网表。

## 模拟输出与 VCM

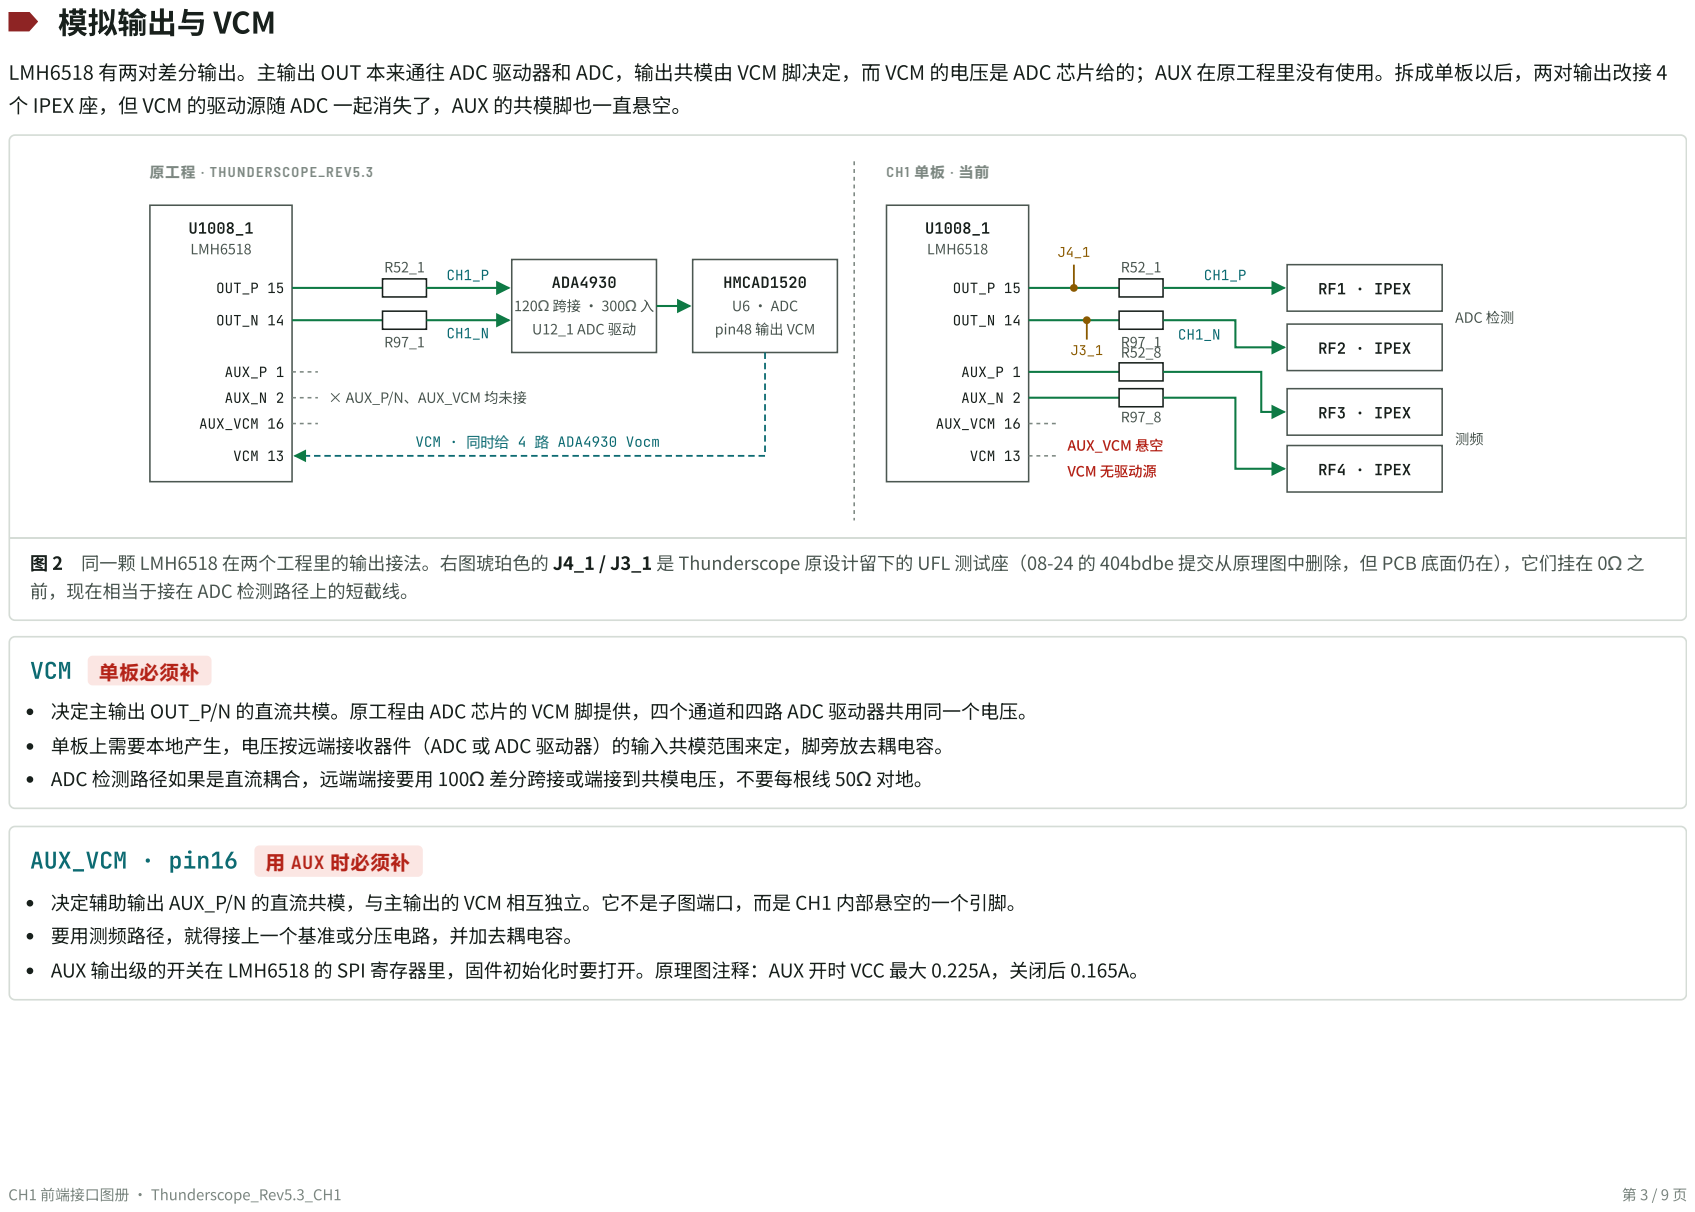
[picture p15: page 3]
CH1 前端接口图册 · Thunderscope_Rev5.3_CH1; 原工程 · THUNDERSCOPE_REV5.3; U1008_1 LMH6518; OUT_P 15; OUT_N 14; AUX_P 1; AUX_N 2; AUX_VCM 16; VCM 13; ADA4930 120Ω 跨接 · 300Ω 入; U12_1 ADC 驱动; HMCAD1520; U6 · ADC; pin48 输出 VCM; × AUX_P/N、AUX_VCM 均未接; RF1 · IPEX; RF2 · IPEX; ADC 检测; RF3 · IPEX; RF4 · IPEX; AUX_VCM 悬空; VCM 无驱动源; VCM; 单板必须补; AUX_VCM · pin16; 用 AUX 时必须补

LMH6518 有两对差分输出。主输出 OUT 本来通往 ADC 驱动器和 ADC，输出共模由 VCM 脚决定，而 VCM 的电压是 ADC 芯片给的；AUX 在原工程里没有使用。拆成单板以后，两对输出改接 4
个 IPEX 座，但 VCM 的驱动源随 ADC 一起消失了，AUX 的共模脚也一直悬空。

VCM · 同时给 4 路 ADA4930 Vocm

图 2 同一颗 LMH6518 在两个工程里的输出接法。右图琥珀色的 J4_1 / J3_1 是 Thunderscope 原设计留下的 UFL 测试座（08-24 的 404bdbe 提交从原理图中删除，但 PCB 底面仍在），它们挂在 0Ω 之
前，现在相当于接在 ADC 检测路径上的短截线。

决定主输出 OUT_P/N 的直流共模。原工程由 ADC 芯片的 VCM 脚提供，四个通道和四路 ADC 驱动器共用同一个电压。
单板上需要本地产生，电压按远端接收器件（ADC 或 ADC 驱动器）的输入共模范围来定，脚旁放去耦电容。
ADC 检测路径如果是直流耦合，远端端接要用 100Ω 差分跨接或端接到共模电压，不要每根线 50Ω 对地。

决定辅助输出 AUX_P/N 的直流共模，与主输出的 VCM 相互独立。它不是子图端口，而是 CH1 内部悬空的一个引脚。
要用测频路径，就得接上一个基准或分压电路，并加去耦电容。
AUX 输出级的开关在 LMH6518 的 SPI 寄存器里，固件初始化时要打开。原理图注释：AUX 开时 VCC 最大 0.225A，关闭后 0.165A。

# PGA SPI：增益、带宽、AUX 开关

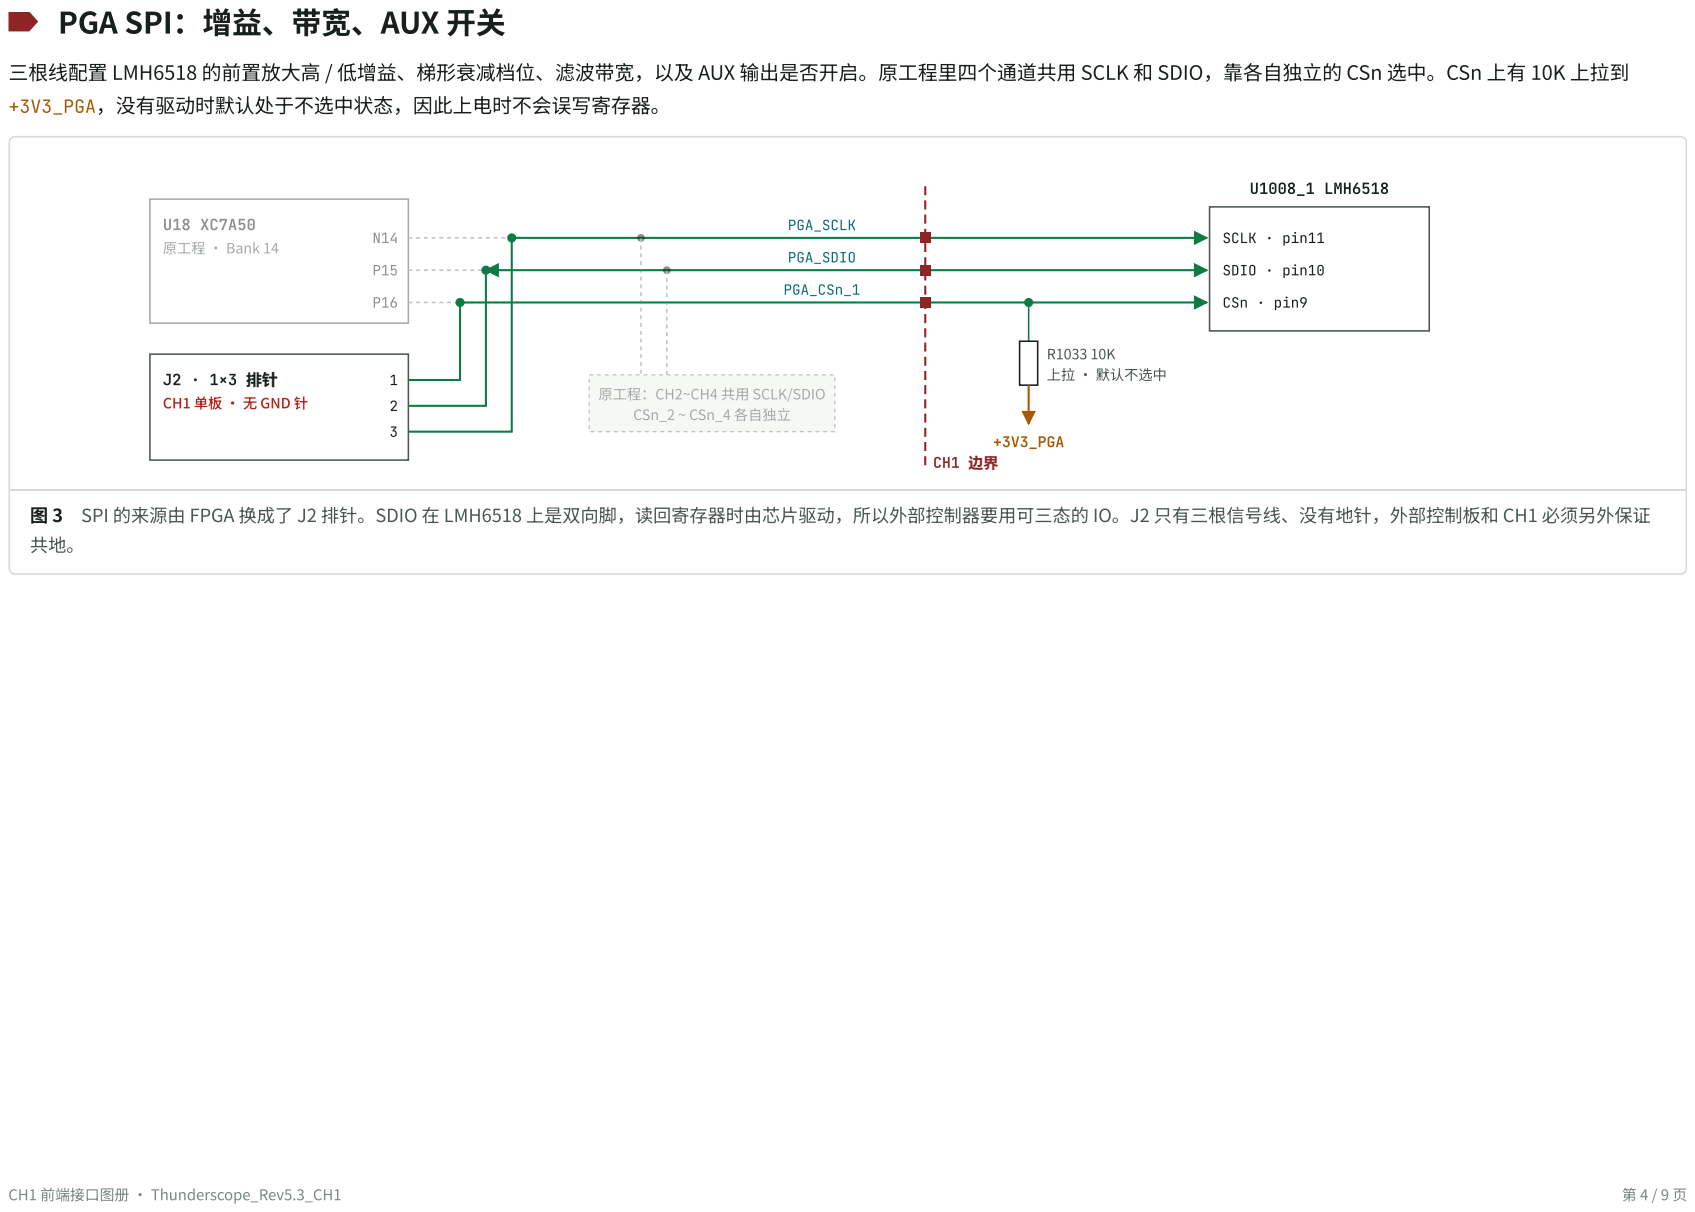
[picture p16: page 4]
CH1 前端接口图册 · Thunderscope_Rev5.3_CH1; 原工程 · Bank 14; CH1 单板 · 无 GND 针; PGA_SCLK; PGA_SDIO; PGA_CSn_1; R1033 10K 上拉 · 默认不选中; +3V3_PGA; U1008_1 LMH6518; SCLK · pin11; SDIO · pin10; CSn · pin9

三根线配置 LMH6518 的前置放大高 / 低增益、梯形衰减档位、滤波带宽，以及 AUX 输出是否开启。原工程里四个通道共用 SCLK 和 SDIO，靠各自独立的 CSn 选中。CSn 上有 10K 上拉到
+3V3_PGA，没有驱动时默认处于不选中状态，因此上电时不会误写寄存器。

原工程：CH2~CH4 共用 SCLK/SDIO
CSn_2 ~ CSn_4 各自独立

图 3 SPI 的来源由 FPGA 换成了 J2 排针。SDIO 在 LMH6518 上是双向脚，读回寄存器时由芯片驱动，所以外部控制器要用可三态的 IO。J2 只有三根信号线、没有地针，外部控制板和 CH1 必须另外保证

# TERM 与 ATTEN：两路继电器

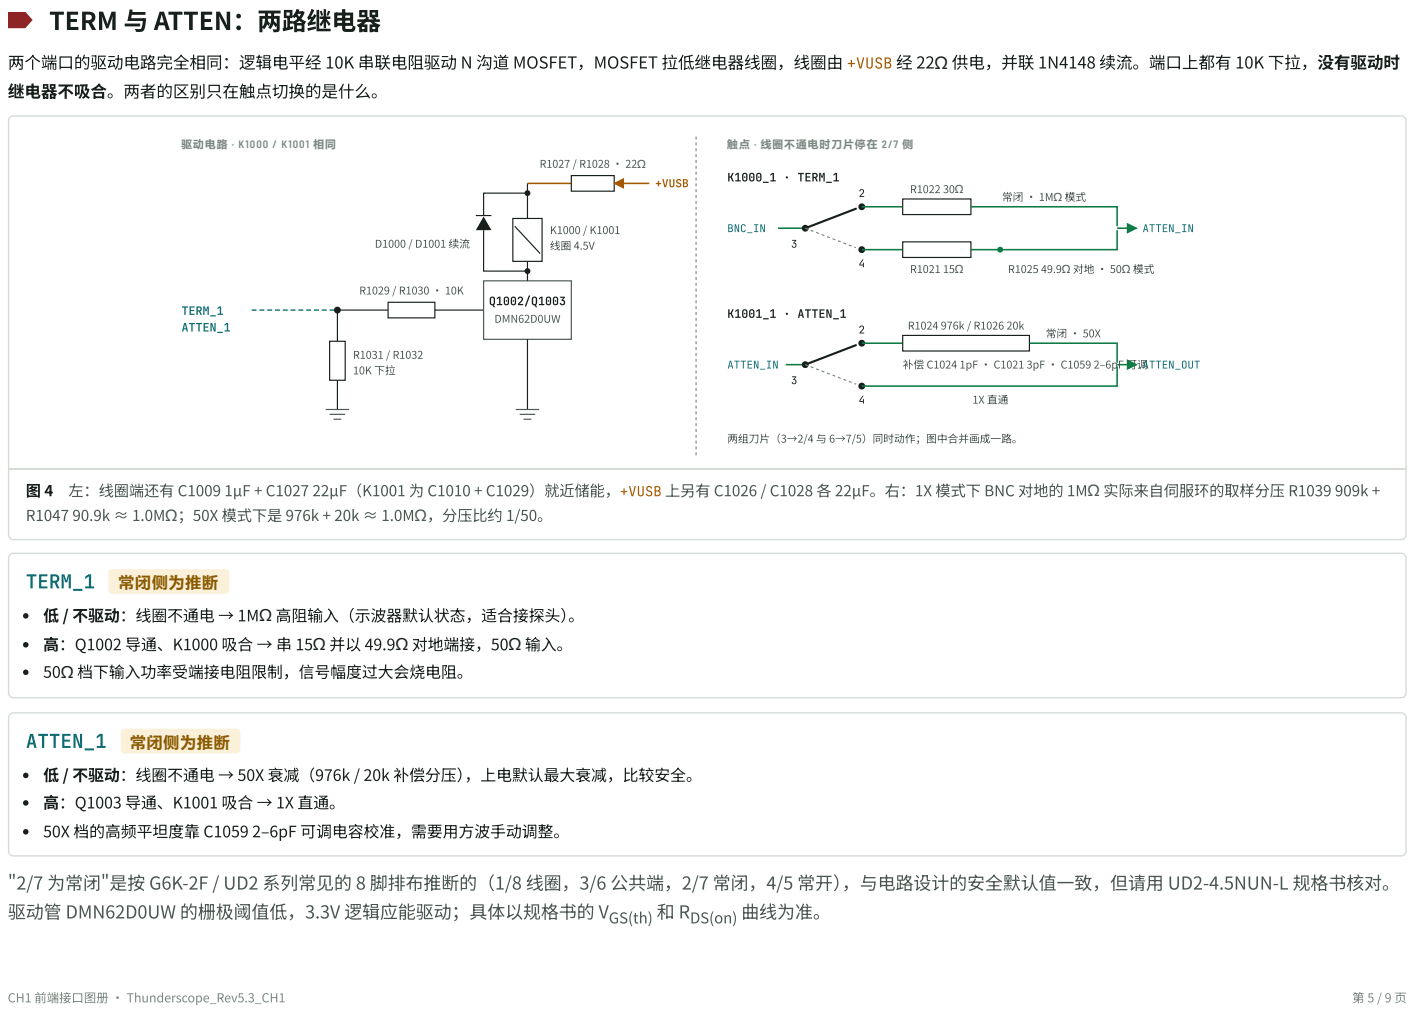
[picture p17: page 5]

两个端口的驱动电路完全相同：逻辑电平经 10K 串联电阻驱动 N 沟道 MOSFET，MOSFET 拉低继电器线圈，线圈由 +VUSB 经 22Ω 供电，并联 1N4148 续流。端口上都有 10K 下拉，没有驱动时

图 4 左：线圈端还有 C1009 1µF + C1027 22µF（K1001 为 C1010 + C1029）就近储能，+VUSB 上另有 C1026 / C1028 各 22µF。右：1X 模式下 BNC 对地的 1MΩ 实际来自伺服环的取样分压 R1039 909k +
R1047 90.9k ≈ 1.0MΩ；50X 模式下是 976k + 20k ≈ 1.0MΩ，分压比约 1/50。

低 / 不驱动：线圈不通电 → 1MΩ 高阻输入（示波器默认状态，适合接探头）。
高：Q1002 导通、K1000 吸合 → 串 15Ω 并以 49.9Ω 对地端接，50Ω 输入。
50Ω 档下输入功率受端接电阻限制，信号幅度过大会烧电阻。

低 / 不驱动：线圈不通电 → 50X 衰减（976k / 20k 补偿分压），上电默认最大衰减，比较安全。
50X 档的高频平坦度靠 C1059 2–6pF 可调电容校准，需要用方波手动调整。

"2/7 为常闭"是按 G6K-2F / UD2 系列常见的 8 脚排布推断的（1/8 线圈，3/6 公共端，2/7 常闭，4/5 常开），与电路设计的安全默认值一致，但请用 UD2-4.5NUN-L 规格书核对。
驱动管 DMN62D0UW 的栅极阈值低，3.3V 逻辑应能驱动；具体以规格书的 VGS(th) 和 RDS(on) 曲线为准。

# DC_CPL：伺服环切换 AC / DC 耦合

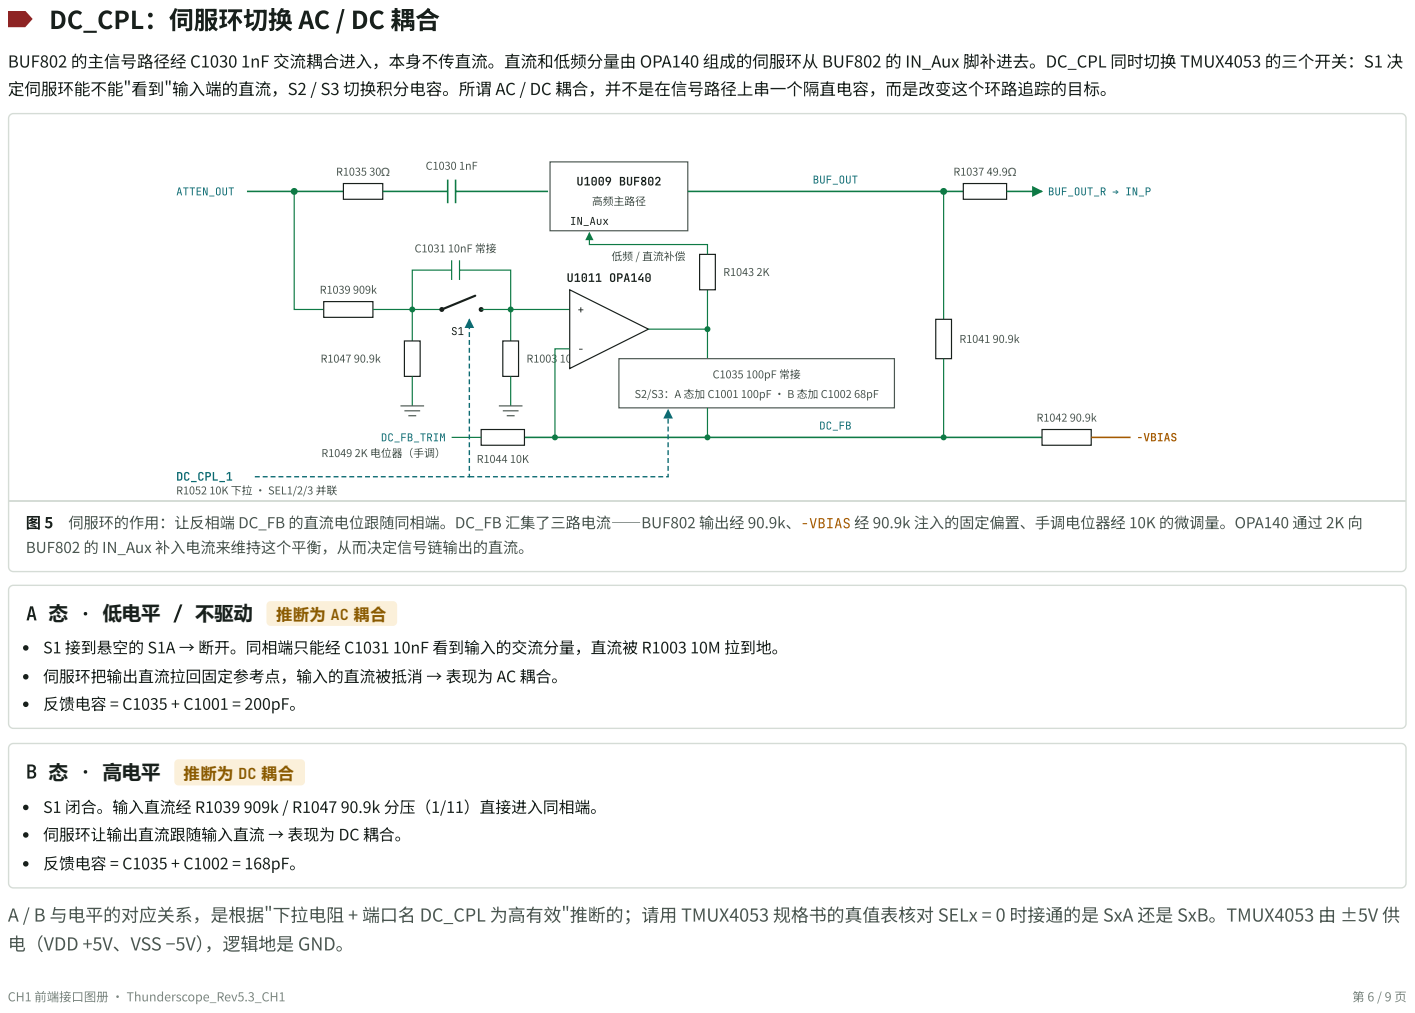
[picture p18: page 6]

BUF802 的主信号路径经 C1030 1nF 交流耦合进入，本身不传直流。直流和低频分量由 OPA140 组成的伺服环从 BUF802 的 IN_Aux 脚补进去。DC_CPL 同时切换 TMUX4053 的三个开关：S1 决
定伺服环能不能"看到"输入端的直流，S2 / S3 切换积分电容。所谓 AC / DC 耦合，并不是在信号路径上串一个隔直电容，而是改变这个环路追踪的目标。

图 5 伺服环的作用：让反相端 DC_FB 的直流电位跟随同相端。DC_FB 汇集了三路电流——BUF802 输出经 90.9k、−VBIAS 经 90.9k 注入的固定偏置、手调电位器经 10K 的微调量。OPA140 通过 2K 向
BUF802 的 IN_Aux 补入电流来维持这个平衡，从而决定信号链输出的直流。

A 态 · 低电平 / 不驱动 推断为 AC 耦合

S1 接到悬空的 S1A → 断开。同相端只能经 C1031 10nF 看到输入的交流分量，直流被 R1003 10M 拉到地。
伺服环把输出直流拉回固定参考点，输入的直流被抵消 → 表现为 AC 耦合。
反馈电容 = C1035 + C1001 = 200pF。

B 态 · 高电平 推断为 DC 耦合

S1 闭合。输入直流经 R1039 909k / R1047 90.9k 分压（1/11）直接进入同相端。
伺服环让输出直流跟随输入直流 → 表现为 DC 耦合。
反馈电容 = C1035 + C1002 = 168pF。

A / B 与电平的对应关系，是根据"下拉电阻 + 端口名 DC_CPL 为高有效"推断的；请用 TMUX4053 规格书的真值表核对 SELx = 0 时接通的是 SxA 还是 SxB。TMUX4053 由 ±5V 供
电（VDD +5V、VSS −5V），逻辑地是 GND。
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

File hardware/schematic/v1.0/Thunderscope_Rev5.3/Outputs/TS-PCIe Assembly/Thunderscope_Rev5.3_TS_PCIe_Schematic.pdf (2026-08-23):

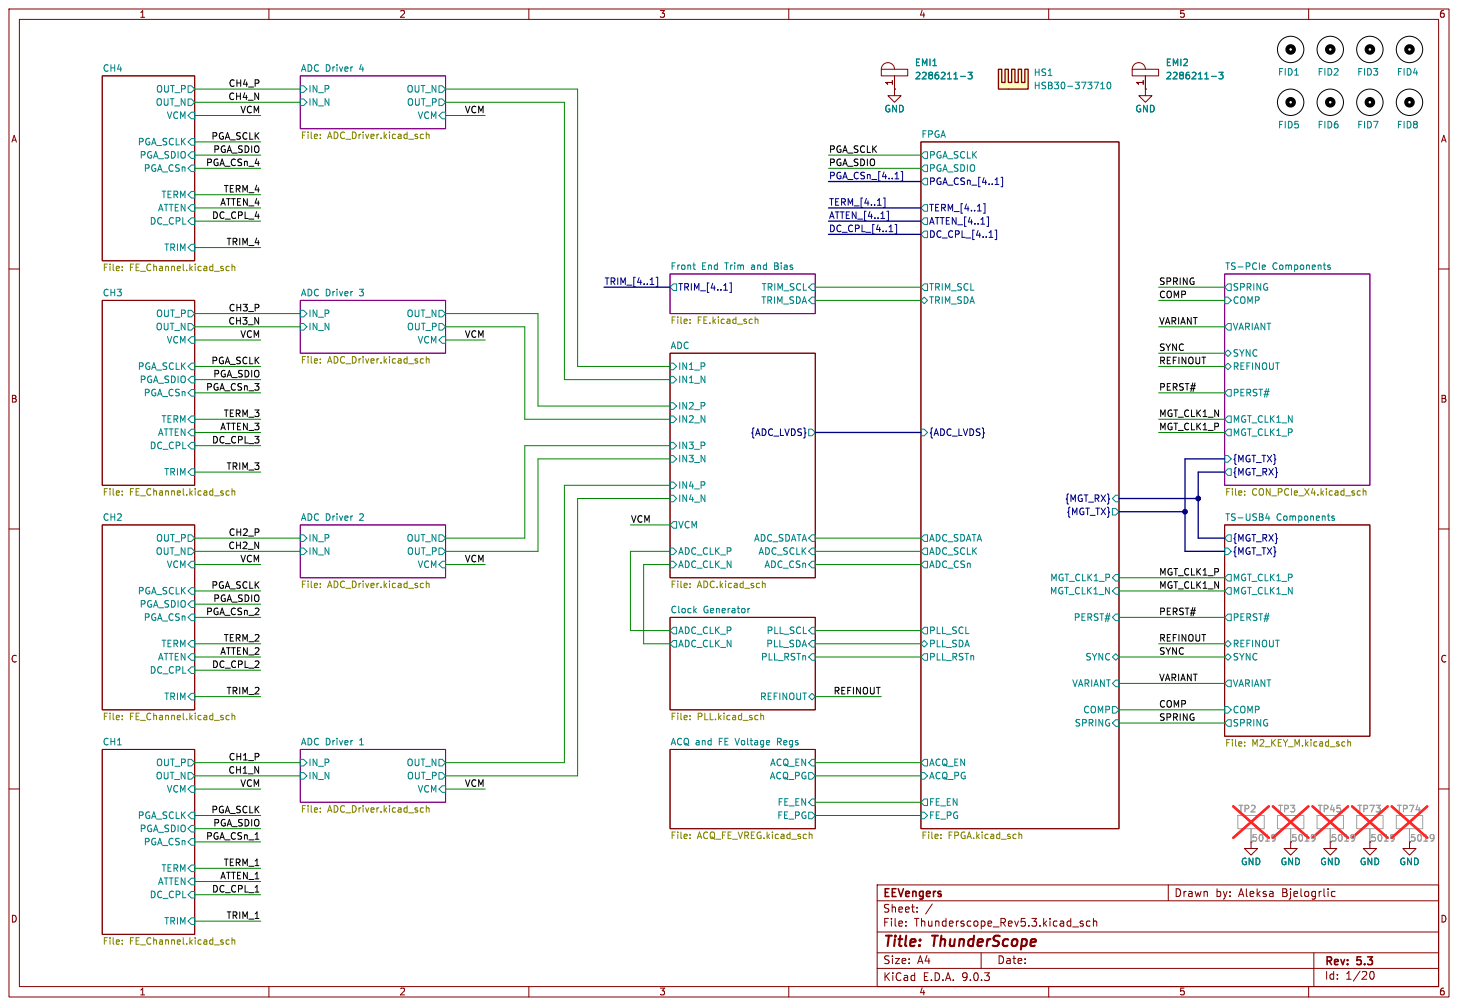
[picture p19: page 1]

2286211-3 1 GND
FID5 GND
TS-PCIe Components File: CON_PCIe_X4.kicad_sch TP3

TRIM_[4..1] Front End Trim and Bias File: FE.kicad_sch VCM

TS-USB4 Components File: M2_KEY_M.kicad_sch VCM

ACQ and FE Voltage Regs File: ACQ_FE_VREG.kicad_sch OUT_P

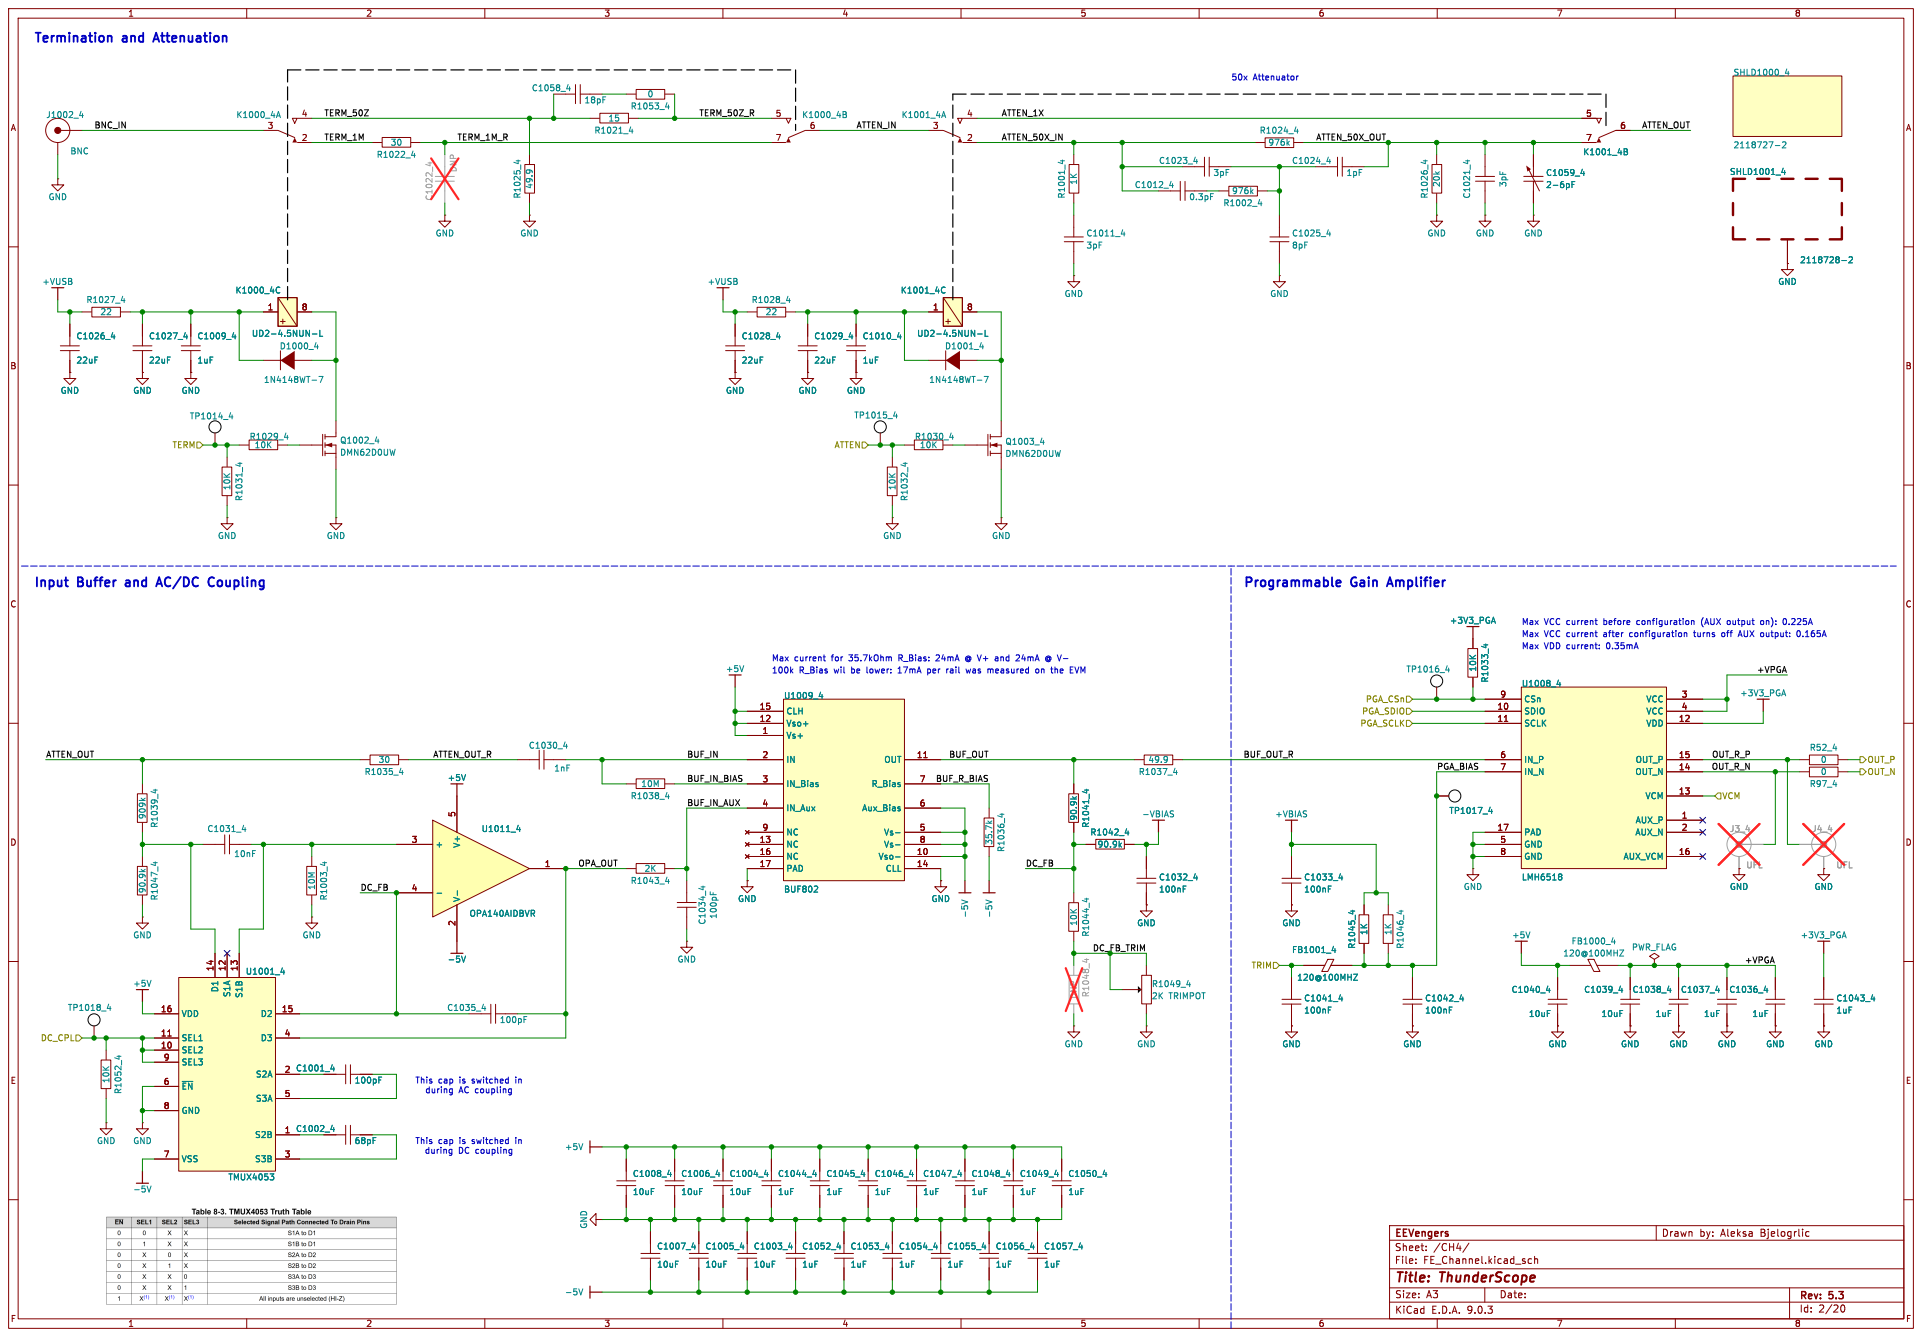
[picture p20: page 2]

Input Buffer and AC/DC Coupling

100k R_Bias wil be lower: 17mA per rail was measured on the EVM

This cap is switched in
during AC coupling This cap is switched in

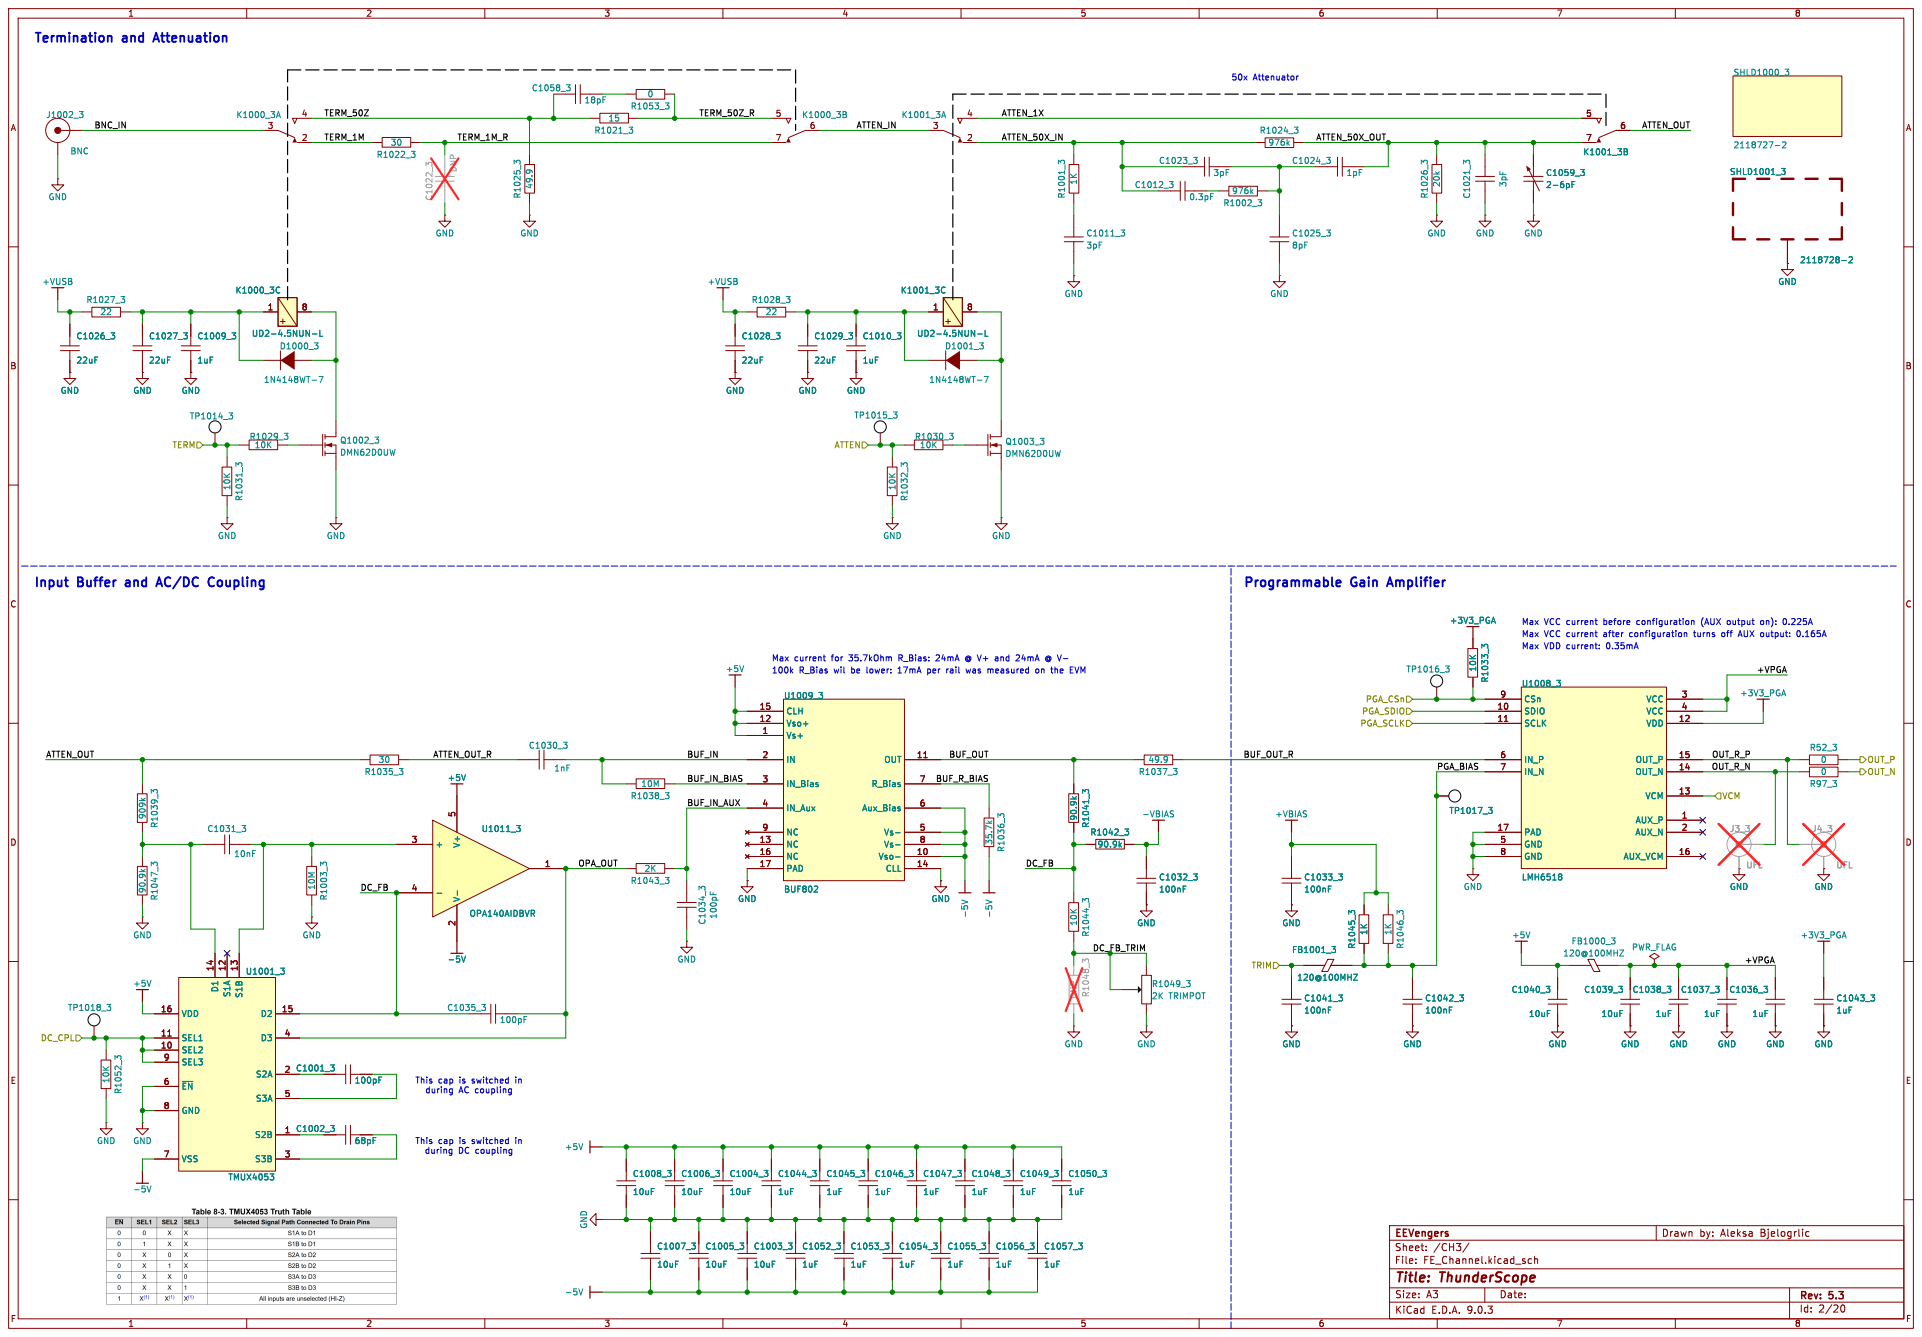
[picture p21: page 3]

Input Buffer and AC/DC Coupling

100k R_Bias wil be lower: 17mA per rail was measured on the EVM

This cap is switched in
during AC coupling This cap is switched in


Input Buffer and AC/DC Coupling

100k R_Bias wil be lower: 17mA per rail was measured on the EVM

This cap is switched in
during AC coupling This cap is switched in


Input Buffer and AC/DC Coupling

100k R_Bias wil be lower: 17mA per rail was measured on the EVM

This cap is switched in
during AC coupling This cap is switched in







1 AVSS2 31 AVDD 36 AVSS 39 AVDD2 32 AVSS 42 AVSS 45 DVDD 30 EPAD 49 DVDD

8 OVDD 33 DVSS 29 D4B- 28 D4B+ 27 D4A- 26 D4A+ 25 D3B- 24 D3B+ 23 D3A- 22 D3A+ 21 FCLK- 20 FCLK+ 19



Vout = 5.01V Front End Voltage Regulators


FPGA IO Banks File: FPGA_Bank_IO.kicad_sch TDI TDO
{USRIO} SYNC_IN_P




NOTE: Connect CLK25 to MRCC P pin



AC Couple REFCLK Lines with 100nF


Refclock and Sync BNCs

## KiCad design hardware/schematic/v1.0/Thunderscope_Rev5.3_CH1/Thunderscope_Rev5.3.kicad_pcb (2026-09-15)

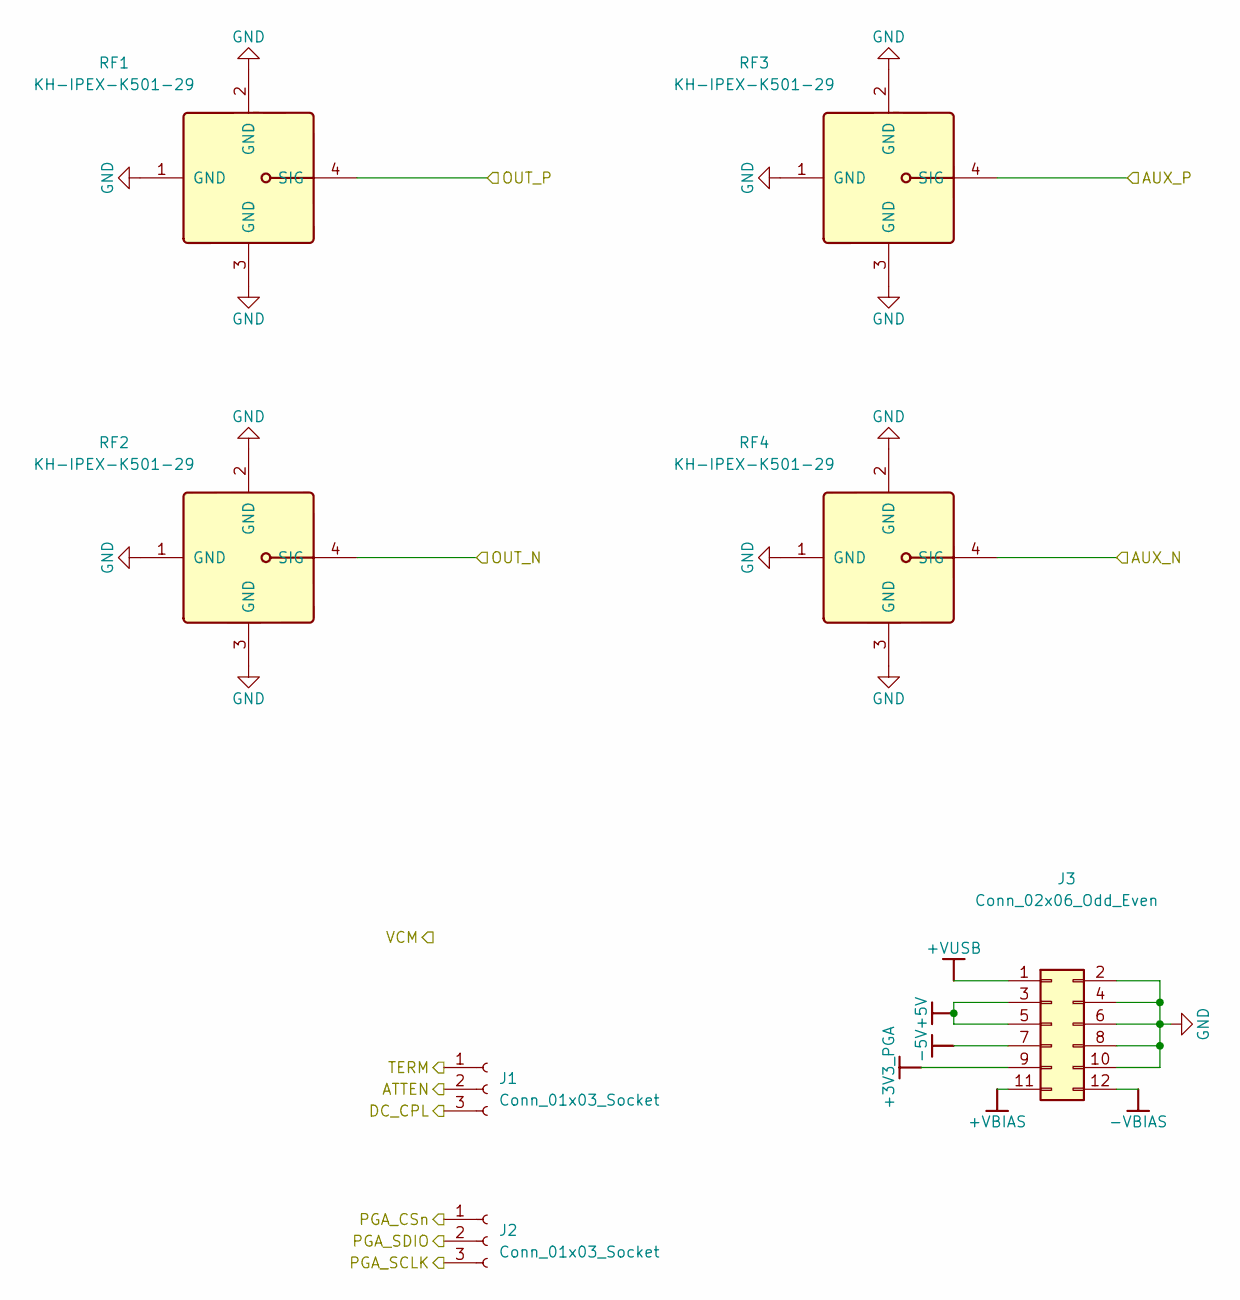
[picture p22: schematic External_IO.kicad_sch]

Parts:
J1, J2: Conn_01x03_Socket; PinHeader_1x03_P2.54mm_Vertical
J3: Conn_02x06_Odd_Even; PinSocket_2x06_P1.27mm_Horizontal
RF1, RF2, RF3, RF4: KH-IPEX-K501-29; Manufacturer Part KH-IPEX-K501-29; LCSC C411563

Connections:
+3V3_PGA: J3.9; also elsewhere on the board
+5V: J3.3, J3.5; also elsewhere on the board
+VBIAS: J3.11; also elsewhere on the board
+VUSB: J3.1; also elsewhere on the board
-5V: J3.7; also elsewhere on the board
-VBIAS: J3.12; also elsewhere on the board
/ATTEN_1: J1.2; also elsewhere on the board
/CH1_AUX_N: RF4.4 (SIG); also elsewhere on the board
/CH1_AUX_P: RF3.4 (SIG); also elsewhere on the board
/CH1_N: RF2.4 (SIG); also elsewhere on the board
/CH1_P: RF1.4 (SIG); also elsewhere on the board
/DC_CPL_1: J1.3; also elsewhere on the board
/PGA_CSn_1: J2.1; also elsewhere on the board
/PGA_SCLK: J2.3; also elsewhere on the board
/PGA_SDIO: J2.2; also elsewhere on the board
/TERM_1: J1.1; also elsewhere on the board
GND: J3.2, J3.4, J3.6, J3.8, J3.10, RF1.1 (GND), RF1.2 (GND), RF1.3 (GND), RF2.1 (GND), RF2.2 (GND), RF2.3 (GND), RF3.1 (GND), RF3.2 (GND), RF3.3 (GND), RF4.1 (GND), RF4.2 (GND), RF4.3 (GND); also elsewhere on the board

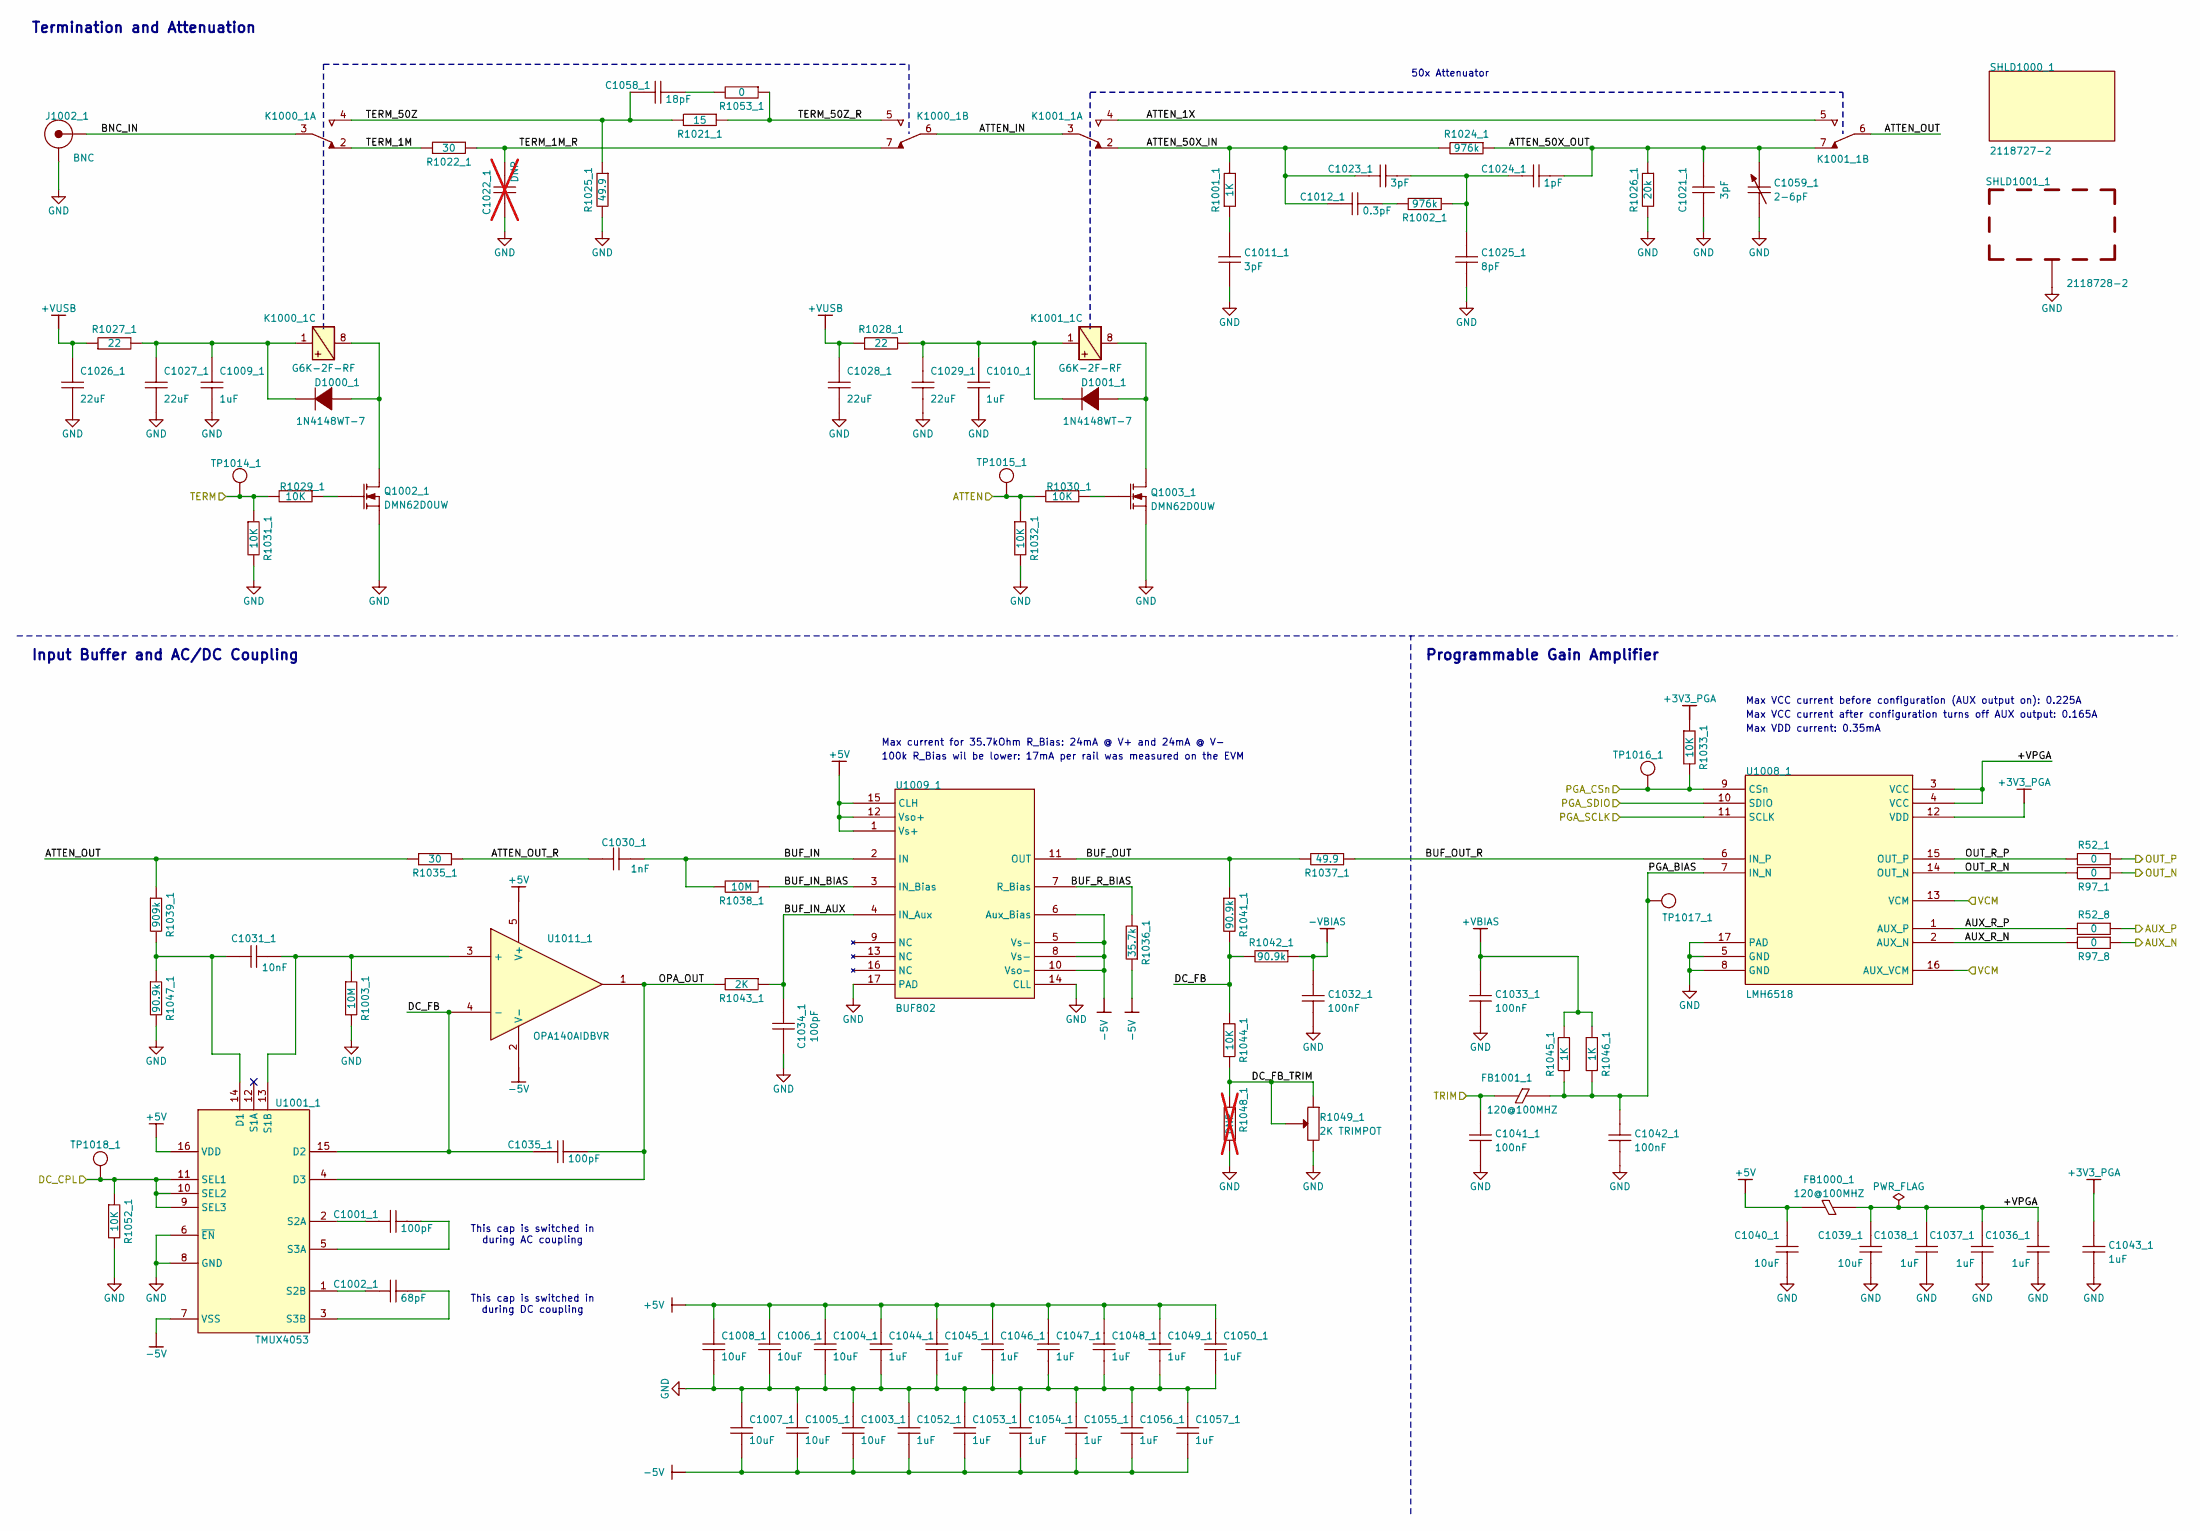
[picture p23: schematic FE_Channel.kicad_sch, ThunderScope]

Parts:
C1001_1, C1034_1, C1035_1: 100pF; GEN_C_0402; VOLTAGE RATING 50V; MANUFACTURER PART NUMBER GCM1555C1H101FA16D
C1002_1: 68pF; GEN_C_0402; VOLTAGE RATING 50V; MANUFACTURER PART NUMBER GCM1555C1H680FA16J
C1003_1, C1004_1, C1005_1, C1006_1, C1007_1, C1008_1, C1039_1, C1040_1: 10uF; GEN_C_0603; VOLTAGE RATING 25V; MANUFACTURER PART NUMBER GRM188R61E106MA73D
C1009_1, C1010_1, C1036_1, C1037_1, C1038_1, C1043_1, C1044_1, C1045_1, C1046_1, C1047_1, C1048_1, C1049_1, C1050_1, C1052_1, C1053_1, C1054_1, C1055_1, C1056_1, C1057_1: 1uF; GEN_C_0402; VOLTAGE RATING 25V; MANUFACTURER PART NUMBER GRM155R61E105KA12D
C1011_1, C1021_1, C1023_1: 3pF; GEN_C_0402; VOLTAGE RATING 200V; MANUFACTURER PART NUMBER CBR04C309B2GAC
C1012_1: 0.3pF; GEN_C_0402; VOLTAGE RATING 100V; MANUFACTURER PART NUMBER 04021J0R3ZBSTR
C1022_1: DNP; GEN_C_0603; not fitted
C1024_1: 1pF; GEN_C_0402; VOLTAGE RATING 50V; MANUFACTURER PART NUMBER CBR04C109A5GAC
C1025_1: 8pF; GEN_C_0402; VOLTAGE RATING 50V; MANUFACTURER PART NUMBER CBR04C809B5GAC
C1026_1, C1027_1, C1028_1, C1029_1: 22uF; GEN_C_0805; VOLTAGE RATING 25V; MANUFACTURER PART NUMBER GRM21BR61E226ME44L
C1030_1: 1nF; GEN_C_0603; VOLTAGE RATING 100V; MANUFACTURER PART NUMBER GCM1885C2A102FA16D
C1031_1: 10nF; GEN_C_0603; VOLTAGE RATING 50V; MANUFACTURER PART NUMBER GRM1885C1H103JA01J
C1032_1, C1033_1, C1041_1, C1042_1: 100nF; GEN_C_0402; VOLTAGE RATING 16V; MANUFACTURER PART NUMBER GCM155R71C104KA55D
C1058_1: 18pF; GEN_C_0402; VOLTAGE RATING 50V; MANUFACTURER PART NUMBER CBR04C180F5GAC
C1059_1: 2-6pF; EW_TRIMCAP; MANUFACTURER PART NUMBER SGC3S060
D1000_1, D1001_1: 1N4148WT-7; GEN_SOD_523; MANUFACTURER PART NUMBER 1N4148WT-7
FB1000_1, FB1001_1: 120@100MHZ; GEN_R_0402; MANUFACTURER PART NUMBER BLM15PX121SN1D
J1002_1: BNC; MOL_0731000105; MANUFACTURER PART NUMBER 73100-0105
K1000_1, K1001_1: G6K-2F-RF; KEMET_UD2-4.5NUN-L; MANUFACTURER PART NUMBER UD2-4.5NUN-L
Q1002_1, Q1003_1: DMN62D0UW; GEN_SOT_323; MANUFACTURER PART NUMBER DMN62D0UW-7
R52_1, R52_8, R97_1, R97_8, R1053_1: 0; GEN_R_0402; MANUFACTURER PART NUMBER RC0402JR-070RL
R1001_1, R1045_1, R1046_1: 1K; GEN_R_0402; TOLERANCE 1%; MANUFACTURER PART NUMBER RC0402FR-071KL
R1002_1, R1024_1: 976k; GEN_R_0402; TOLERANCE 1%; MANUFACTURER PART NUMBER RK73H1ETTP9763F
R1003_1, R1038_1: 10M; GEN_R_0603; TOLERANCE 1%; MANUFACTURER PART NUMBER RK73H1JTTD1005F
R1021_1: 15; GEN_R_0603; TOLERANCE 1%; MANUFACTURER PART NUMBER SG73P1JTTD15R0F
R1022_1, R1035_1: 30; GEN_R_0603; TOLERANCE 1%; MANUFACTURER PART NUMBER SG73P1JTTD30R0F
R1025_1: 49.9; GEN_R_0508; TOLERANCE 1%; POWER RATING 1W; MANUFACTURER PART NUMBER WK73R2ATTD49R9F
R1026_1: 20k; GEN_R_0402; TOLERANCE 1%; MANUFACTURER PART NUMBER RC0402FR-0720KL
R1027_1, R1028_1: 22; GEN_R_0603; TOLERANCE 1%; MANUFACTURER PART NUMBER SG73P1JTTD22R0F
R1029_1, R1030_1, R1031_1, R1032_1, R1033_1, R1044_1, R1052_1: 10K; GEN_R_0402; TOLERANCE 1%; MANUFACTURER PART NUMBER RC0402FR-0710KL
R1036_1: 35.7k; GEN_R_0402; TOLERANCE 1%; MANUFACTURER PART NUMBER RC0402FR-0735K7L
R1037_1: 49.9; GEN_R_0402; TOLERANCE 1%; MANUFACTURER PART NUMBER RC0402FR-0749R9L
R1039_1: 909k; GEN_R_0402; TOLERANCE 1%; MANUFACTURER PART NUMBER RC0402FR-07909KL
R1041_1, R1042_1, R1047_1: 90.9k; GEN_R_0402; TOLERANCE 1%; MANUFACTURER PART NUMBER RC0402FR-0790K9L
R1043_1: 2K; GEN_R_0402; TOLERANCE 1%; MANUFACTURER PART NUMBER RC0402FR-072KL
R1048_1: DNP; GEN_R_0402; TOLERANCE 1%; not fitted
R1049_1: 2K TRIMPOT; BOU_3mm_POT; TOLERANCE 1%; MANUFACTURER PART NUMBER TC33X-2-202E
SHLD1000_1: 2118727-2; MANUFACTURER PART NUMBER 2118727-2
SHLD1001_1: 2118728-2; TE_2118728-2; MANUFACTURER PART NUMBER 2118728-2
TP1014_1, TP1015_1, TP1016_1, TP1017_1, TP1018_1: PCB; GEN_TP_PCB
U1001_1: TMUX4053; TI_TSOT-23-16_DYY0016A; MANUFACTURER PART NUMBER TMUX4053DYYR
U1008_1: LMH6518; TI_WQFN_RGH0016A; MANUFACTURER PART NUMBER LMH6518SQX/NOPB
U1009_1: BUF802; TI_VQFN_RGT0016C; MANUFACTURER PART NUMBER BUF802IRGTR
U1011_1: OPA140AIDBVR; GEN_SOT23_5_950_2900X1600X1450; MANUFACTURER PART NUMBER OPA140AIDBVR

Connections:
+3V3_PGA: C1043_1.1, R1033_1.1, U1008_1.12 (VDD); also elsewhere on the board
+5V: C1004_1.2, C1006_1.2, C1008_1.2, C1040_1.2, C1044_1.1, C1045_1.1, C1046_1.1, C1047_1.1, C1048_1.1, C1049_1.1, C1050_1.1, FB1000_1.2, U1001_1.16 (VDD), U1009_1.1 (Vs+), U1009_1.12 (Vso+), U1009_1.15 (CLH), U1011_1.5 (V+); also elsewhere on the board
+VBIAS: C1033_1.2, R1045_1.1, R1046_1.1; also elsewhere on the board
+VUSB: C1026_1.2, C1028_1.2, R1027_1.1, R1028_1.1; also elsewhere on the board
-5V: C1003_1.1, C1005_1.1, C1007_1.1, C1052_1.2, C1053_1.2, C1054_1.2, C1055_1.2, C1056_1.2, C1057_1.2, R1036_1.2, U1001_1.7 (VSS), U1009_1.5 (Vs-), U1009_1.6 (Aux_Bias), U1009_1.8 (Vs-), U1009_1.10 (Vso-), U1011_1.2 (V-); also elsewhere on the board
-VBIAS: C1032_1.2, R1042_1.1; also elsewhere on the board
/ATTEN_1: R1030_1.2, R1032_1.1, TP1015_1.1 (1_1); also elsewhere on the board
/CH1/+VPGA: C1036_1.1, C1037_1.1, C1038_1.1, C1039_1.2, FB1000_1.1, U1008_1.3 (VCC), U1008_1.4 (VCC)
/CH1/ATTEN_1X: K1001_1.4, K1001_1.5
/CH1/ATTEN_50X_IN: C1012_1.2, C1023_1.2, K1001_1.2, R1001_1.2, R1024_1.1
/CH1/ATTEN_50X_OUT: C1021_1.2, C1024_1.1, C1059_1.1, K1001_1.7, R1024_1.2, R1026_1.2
/CH1/ATTEN_IN: K1000_1.6, K1001_1.3
/CH1/ATTEN_OUT: K1001_1.6, R1035_1.1, R1039_1.1
/CH1/ATTEN_OUT_R: C1030_1.2, R1035_1.2
/CH1/AUX_R_N: R97_8.1, U1008_1.2 (AUX_N)
/CH1/AUX_R_P: R52_8.1, U1008_1.1 (AUX_P)
/CH1/BNC_IN: J1002_1.1 (Signal), K1000_1.3
/CH1/BUF_IN: C1030_1.1, R1038_1.2, U1009_1.2 (IN)
/CH1/BUF_IN_AUX: C1034_1.2, R1043_1.1, U1009_1.4 (IN_Aux)
/CH1/BUF_IN_BIAS: R1038_1.1, U1009_1.3 (IN_Bias)
/CH1/BUF_OUT: R1037_1.1, R1041_1.1, U1009_1.11 (OUT)
/CH1/BUF_OUT_R: R1037_1.2, U1008_1.6 (IN_P)
/CH1/BUF_R_BIAS: R1036_1.1, U1009_1.7 (R_Bias)
/CH1/DC_FB: C1035_1.2, R1041_1.2, R1042_1.2, R1044_1.1, U1001_1.15 (D2), U1011_1.4 (-)
/CH1/DC_FB_TRIM: R1044_1.2, R1048_1.2, R1049_1.1, R1049_1.2
/CH1/OPA_OUT: C1035_1.1, R1043_1.2, U1001_1.4 (D3), U1011_1.1 (OUT)
/CH1/OUT_R_N: R97_1.1, U1008_1.14 (OUT_N)
/CH1/OUT_R_P: R52_1.1, U1008_1.15 (OUT_P)
/CH1/PGA_BIAS: C1042_1.2, FB1001_1.2, R1045_1.2, R1046_1.2, TP1017_1.1 (1_1), U1008_1.7 (IN_N)
/CH1/TERM_1M: K1000_1.2, R1022_1.2
/CH1/TERM_1M_R: C1022_1.2, K1000_1.7, R1022_1.1
/CH1/TERM_50Z: C1058_1.2, K1000_1.4, R1021_1.2, R1025_1.2
/CH1/TERM_50Z_R: K1000_1.5, R1021_1.1, R1053_1.2
/CH1_AUX_N: R97_8.2; also elsewhere on the board
/CH1_AUX_P: R52_8.2; also elsewhere on the board
/CH1_N: R97_1.2; also elsewhere on the board
/CH1_P: R52_1.2; also elsewhere on the board
/DC_CPL_1: R1052_1.1, TP1018_1.1 (1_1), U1001_1.9 (SEL3), U1001_1.10 (SEL2), U1001_1.11 (SEL1); also elsewhere on the board
/PGA_CSn_1: R1033_1.2, TP1016_1.1 (1_1), U1008_1.9 (CSn); also elsewhere on the board
/PGA_SCLK: U1008_1.11 (SCLK); also elsewhere on the board
/PGA_SDIO: U1008_1.10 (SDIO); also elsewhere on the board
/TERM_1: R1029_1.2, R1031_1.1, TP1014_1.1 (1_1); also elsewhere on the board
/TRIM_1: C1041_1.2, FB1001_1.1
/VCM: U1008_1.13 (VCM), U1008_1.16 (AUX_VCM)
GND: C1003_1.2, C1004_1.1, C1005_1.2, C1006_1.1, C1007_1.2, C1008_1.1, C1009_1.2, C1010_1.2, C1011_1.1, C1021_1.1, C1022_1.1, C1025_1.1, C1026_1.1, C1027_1.1, C1028_1.1, C1029_1.1, C1032_1.1, C1033_1.1, C1034_1.1, C1036_1.2, C1037_1.2, C1038_1.2, C1039_1.1, C1040_1.1, C1041_1.1, C1042_1.1, C1043_1.2, C1044_1.2, C1045_1.2, C1046_1.2, C1047_1.2, C1048_1.2, C1049_1.2, C1050_1.2, C1052_1.1, C1053_1.1, C1054_1.1, C1055_1.1, C1056_1.1, C1057_1.1, C1059_1.2, J1002_1.2 (SHIELD), Q1002_1.3 (S), Q1003_1.3 (S), R1003_1.2, R1025_1.1, R1026_1.1, R1031_1.2, R1032_1.2, R1047_1.2, R1048_1.1, R1049_1.3, R1052_1.2, SHLD1001_1.1 (1_1), U1001_1.6 (~EN), U1001_1.8 (GND), U1008_1.5 (GND), U1008_1.8 (GND), U1008_1.17 (PAD), U1009_1.14 (CLL), U1009_1.17 (PAD); also elsewhere on the board
unnamed: C1011_1.2, R1001_1.1
unnamed: C1012_1.1, R1002_1.1
unnamed: C1023_1.1, C1024_1.2, C1025_1.2, R1002_1.2
unnamed: C1058_1.1, R1053_1.1
unnamed: D1000_1.2 (A), K1000_1.8, Q1002_1.1 (D)
unnamed: C1009_1.1, C1027_1.2, D1000_1.1 (K), K1000_1.1, R1027_1.2
unnamed: D1001_1.2 (A), K1001_1.8, Q1003_1.1 (D)
unnamed: C1010_1.1, C1029_1.2, D1001_1.1 (K), K1001_1.1, R1028_1.2
unnamed: Q1002_1.2 (G), R1029_1.1
unnamed: Q1003_1.2 (G), R1030_1.1
unnamed: C1031_1.1, R1039_1.2, R1047_1.1, U1001_1.14 (D1)
unnamed: C1031_1.2, R1003_1.1, U1001_1.13 (S1B), U1011_1.3 (+)
unnamed: C1001_1.2, U1001_1.2 (S2A)
unnamed: C1002_1.2, U1001_1.1 (S2B)
unnamed: C1001_1.1, U1001_1.5 (S3A)
unnamed: C1002_1.1, U1001_1.3 (S3B)

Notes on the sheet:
Termination and Attenuation
Input Buffer and AC/DC Coupling
This cap is switched in during AC coupling
This cap is switched in during DC coupling
Max current for 35.7kOhm R_Bias: 24mA @ V+ and 24mA @ V-
100k R_Bias wil be lower: 17mA per rail was measured on the EVM
Max VDD current: 0.35mA
Max VCC current before configuration (AUX output on): 0.225A
Max VCC current after configuration turns off AUX output: 0.165A
Programmable Gain Amplifier
50x Attenuator

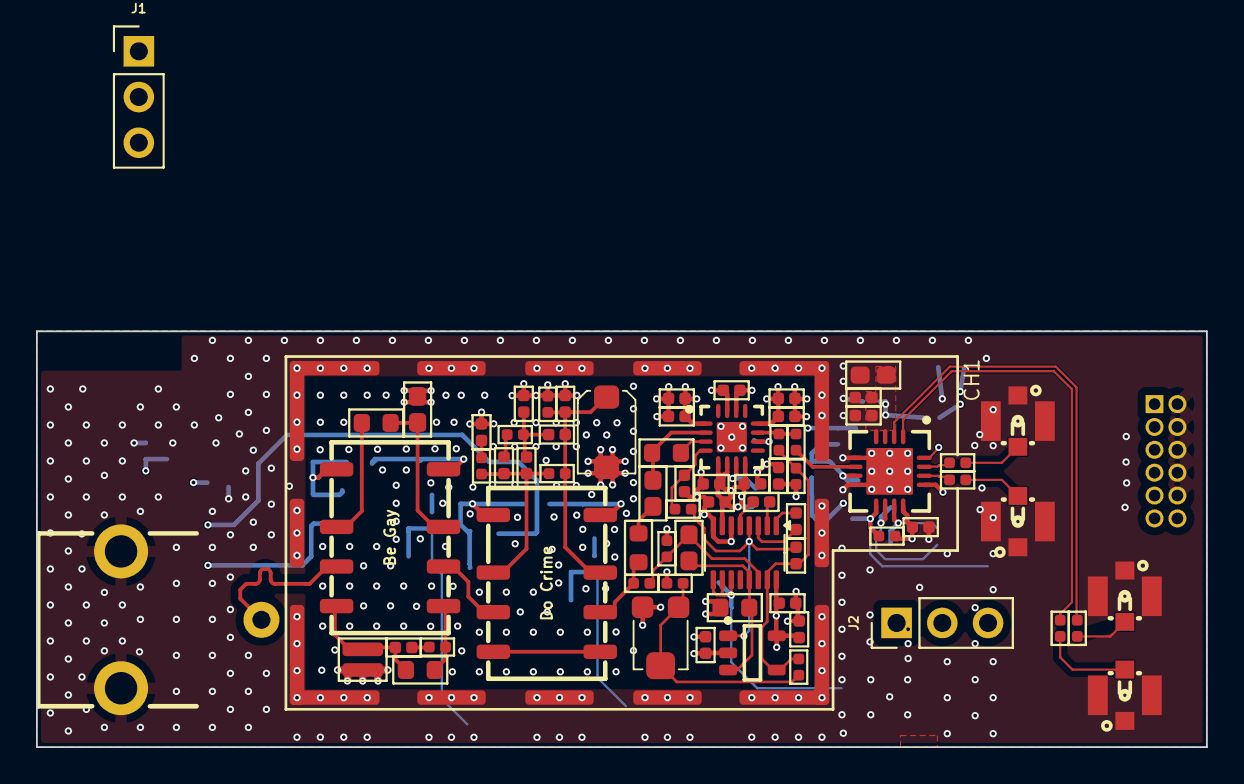
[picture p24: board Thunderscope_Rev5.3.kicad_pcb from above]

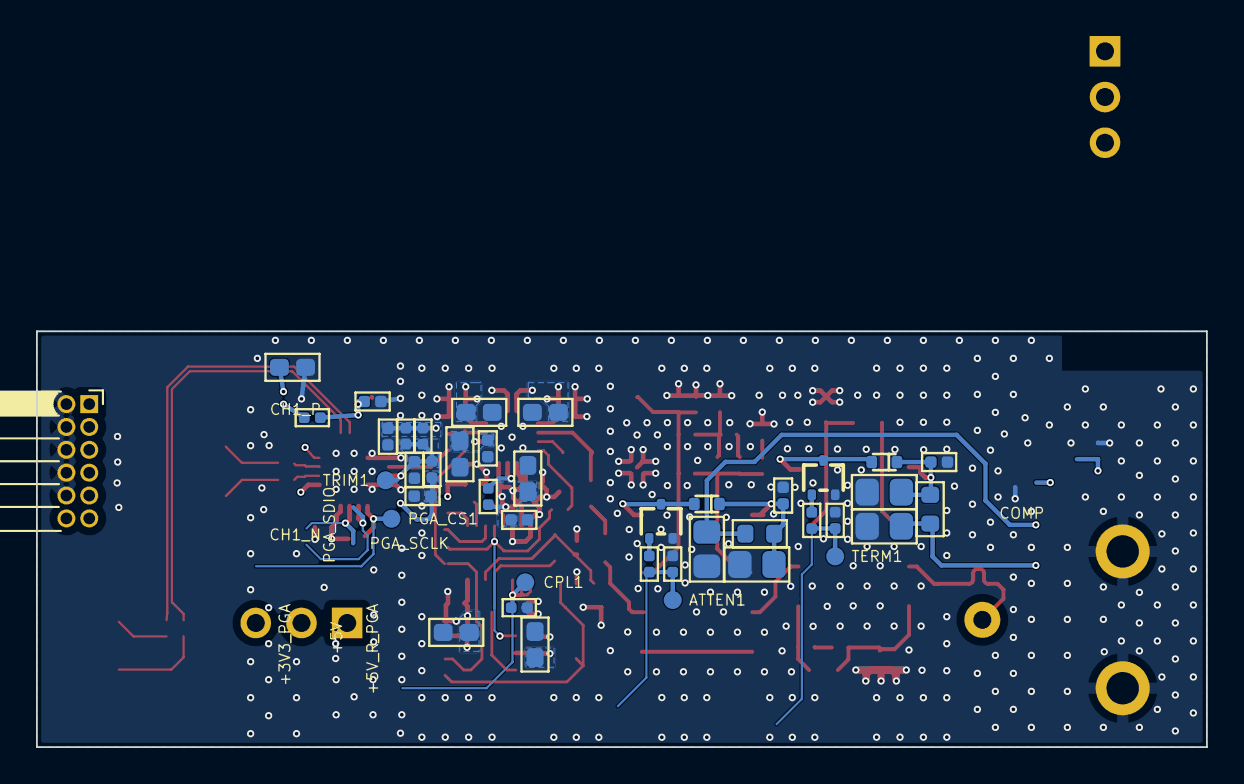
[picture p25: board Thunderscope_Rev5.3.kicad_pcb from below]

Board: 6 copper layers, 65.0 x 23.1 mm, 111 parts (41 on the bottom side), 61 nets.

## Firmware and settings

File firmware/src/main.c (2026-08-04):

/**
 * @file main.c
 * @brief 固件入口点
 *
 * 职责:
 *   - 系统初始化 (时钟/电源/外设)
 *   - 启动各服务模块
 *   - 进入主循环或 RTOS 调度
 */

#include "hal/hal_init.h"
#include "app/app_main.h"
#include "services/service_manager.h"

int main(void)
{
    /* 1. 硬件抽象层初始化 */
    hal_init();

    /* 2. 服务层启动 */
    service_manager_init();

    /* 3. 应用层入口 */
    app_run();

    /* 不应到达此处 */
    while (1) {
        /* idle / WFI */
    }

    return 0;
}

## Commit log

2026-08-04 Initial commit: 高精度频率计前端双通道信号调理电路模块
2026-08-04 feat: 完成高精度频率计前端双通道信号调理电路模块
    [SIG_COND.kicad_pcb, SIG_COND.kicad_sch]
2026-08-05 chore: 更新原理图和配置文件
    [SIG_COND.kicad_sch]
2026-08-05 chore: 移除 history 目录
2026-08-09 chore: 更新 KiCad 原理图相关配置
    [SIG_COND.kicad_sch]
2026-08-22 sch update
    [SIG_COND.kicad_sch]
2026-09-15 sch and pcb update
    [ADC_Driver.kicad_sch, FE_Channel.kicad_sch, Thunderscope_Rev5.3.kicad_pcb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]

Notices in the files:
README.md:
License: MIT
